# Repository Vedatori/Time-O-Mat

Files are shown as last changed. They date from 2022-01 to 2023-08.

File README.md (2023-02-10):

# Time-O-Mat [cz]
Time-O-Mat jsou hodiny navržené pro Letní robotický tábor 2022 organizovaný spolkem [Vědátoři](vedatori.com). Jedná se o otevřenou platformu, která si klade za cíle zlepšit dovednosti při mechanické stavbě a pájení. Účastníci dostali tento výrobek jako stavebnici, kdy z předem připravených dílů sestavili mechanickou část a poté pájeli nestandardní součástky na DPS s předem osazenými SMD součástkami. Po finalizaci je možné hodiny naprogramovat a používat pro zlepšení schopností algoritmizace a programování účastníků díky možnostem, které poskytují vsupní a výstupní periferie.

Mechanickou část lze rozdělit na dvě hlavní části - krabici a osmičky (segmentové zobrazovače). Vnější části krabice jsou vyřezány z překližky na laserové řezačce a obsahují zámkové západky. Ty se při stavbě lepí disperzním lepidlem a po vyschnutí tvoří pevný základ pro uložení ostatních dílů. Pouze horní část je odnímatelná a připevněná šrouby, které jsou schované v podpůrných 3D tištěných dílech, aby nekazily estetický dojem. Základní díl osmiček a dvojtečky je vytisknutý na 3D tiskárně a difuzery jednotlivých segmentů vyřezané z mléčného plexiskla se do něj vkládají z vnitřní strany a jsou uchyceny pomocí západek. Spojení osmiček a krabice zajišťuje 3D tištěný nosník umístěný uvnitř krabice, který také fixuje desky plošných spojů (DPS).

Hlavní DPS obsahuje zejména mikrokontroler ESP32, který je na ni připájen. Programování a napájení je zajištěno přes USB C. Hlavní DPS obsahuje také tlačítka, fotorezistory, bzučák a teplotní senzor. Do horního krytu je vsazena tenká podlouhlá DPS, která slouží jako senzor s osmi kapacitními tlačítky. Dominantou tohoto zařízení jsou DPS ve tvaru osmiček a dvojtečky, které jsou vsazeny za difuzery. Za každým segmentem jsou umístěny tři adresovatelné RGB LED. Další takové LED jsou umístěny zezadu na LED pásku, který zajišťuje ambientní podsvětlení prostoru za výrobkem. Hodiny jsou rozebiratelné, jednotlivé DPS jsou spojeny konektory, vzdálenější periferie pomocí kabelů.

Všechny periferie byly zvoleny tak, aby vytvořily hodiny s mnoha volitelnými postranními funkcionalitami. Díky nim je možné u účastníků tábora rozvíjet jejich schopnost algoritmizovat úlohu a programovat. Pro hodiny byla naprogramována softwarová knihovna, která výrazně zjednodušuje ovládání všech periferií. Pomocí této knihovny byl vytvořen vzorový software, který zobrazuje základní čas po připojení hodin na Wi-Fi. Po odpojení je poté čas uchován pomocí integrovaného RTC modulu, což umožňuje provoz hodin bez trvalého připojení k internetu. Hodiny je možné ovládat pomocí vstupních periferií nebo přes WiFi skrz počítač nebo smartphone, které přistupojí k interně hostované webové stránce. Všechny tyto vlastnosti lze přeprogramovat a přidat nové funkcionality podle přání vlastníka hodin. Zařízení se programuje ve Visual studio Code v jazyce c++ pomocí frameworku esp32-arduino.

Myšlenkou tohoto projektu je, aby Time-O-Mat tvořil každodenní užitečný doplněk pokoje, ale aby mohl být jeho software jednoduše modifikován a rozvíjen tak, jak si každý jeho vlastník představuje.

## Návod
Při stavbě hodin Time-O-Mat postupujte podle připravených návodů v následujícím pořadí:
1. [Návod pro elektroniku](https://github.com/vedatori/Time-O-Mat/blob/main/Manuals/Time-O-Mat_electronics_cz.md)
1. [Návod pro mechaniku](https://github.com/vedatori/Time-O-Mat/blob/main/Manuals/Time-O-Mat_mechanics_cz.md)
1. [Návod pro programování](https://github.com/vedatori/Time-O-Mat/blob/main/Manuals/Time-O-Mat_programming_cz.md)

# Time-O-Mat [en]
Time-O-Mat is a clock designed for Summer robotics camp 2022 (cz) organized by Vědátoři team (cz). It is a robotic platform offering development of mechanical assembly and soldering skills. The project has been designed as a kit for participants to be assembled and special electronic components to be soldered on a pre-assembled printed circuit board (PCB). When assembled it can be used to improve algorithmization and programming skills.

Mechanical set consists of two main parts - box and eights (segment displays). Box is made of laser cut plywood parts with latches that are mostly glued together. Upper parts are fastened using bolts hidden in inner 3D printed parts. The eights are 3D printed bodies with diffusers made of plexiglass clicked in them. Inner 3D printed parts ensure connection of the box and the eights.

Main PCB carries ESP32. It is programmed and powered using USB C and contains buttons, buzzer and photosensors. Capacitive touchbar with eight touch buttons is placed on upper part of the enclosure. Main eye-catcher of the clock is eight-shaped PCB with segments containing three adressable RGB LEDs in each segment. Ambient backlight is provided by LED strip on the backside of the clock. Clock can be disassembled if needed for upgrade or service and connectors are used for PCB interconnections.

All of the peripherals had been chosen to enrich the clock with various related functions. This enables development of algorithmization and programming skills of camp participants. Special internally developed software library makes programming of the clock much easier and allows better understanding of software features. Repository contains demo project that allows WiFi connection and time alignment of the clock with the Internet. Time is stored in RTC module after power off and it is not needed to establish WiFi connection after next power on. Clock can be controlled using input peripherals and Wi-Fi (using smartphone or PC) thru internally hosted website.

New features based on owner's needs can be easily introduced. Main aim of Time-O-Mat is to be a daily companion that offers easy software modifications and development.

## Licence
* Obsah tohoto repozitáře mimo složku *Software* je sdílen pod licencí [Attribution-NonCommercial-ShareAlike 4.0 International (CC BY-NC-SA 4.0)](https://creativecommons.org/licenses/by-nc-sa/4.0/).
* Obsah složky *Software* je sdílen pod licencí [GNU Lesser General Public License v3.0](https://www.gnu.org/licenses/lgpl-3.0.en.html).

## License
* The contents of this repository excluding folder *Software* is shared under license [Attribution-NonCommercial-ShareAlike 4.0 International (CC BY-NC-SA 4.0)](https://creativecommons.org/licenses/by-nc-sa/4.0/).
* The contents of the folder *Software* is shared under license [GNU Lesser General Public License v3.0](https://www.gnu.org/licenses/lgpl-3.0.en.html).

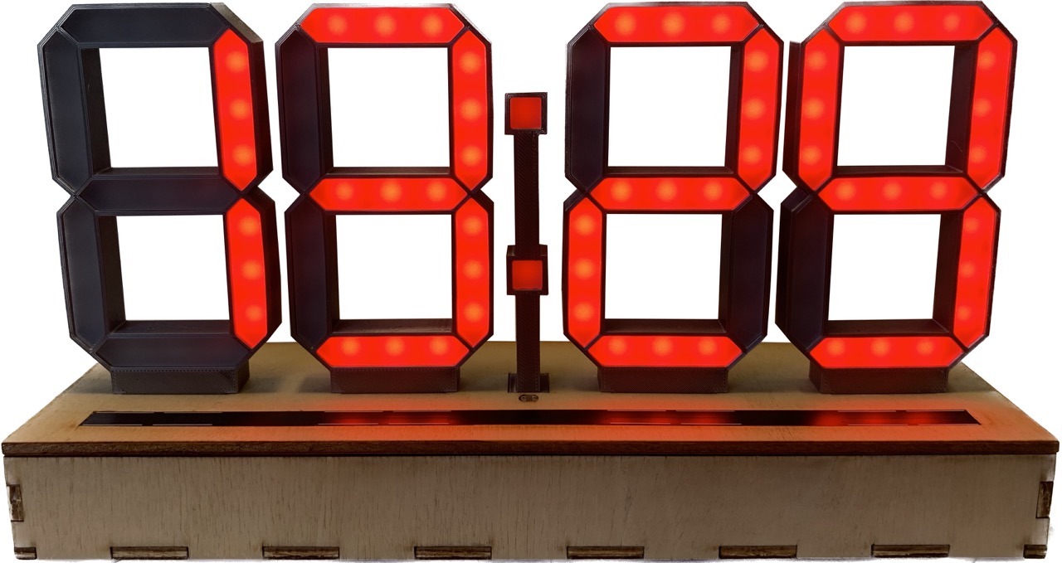
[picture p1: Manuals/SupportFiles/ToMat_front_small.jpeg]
Time-O-Mat front view

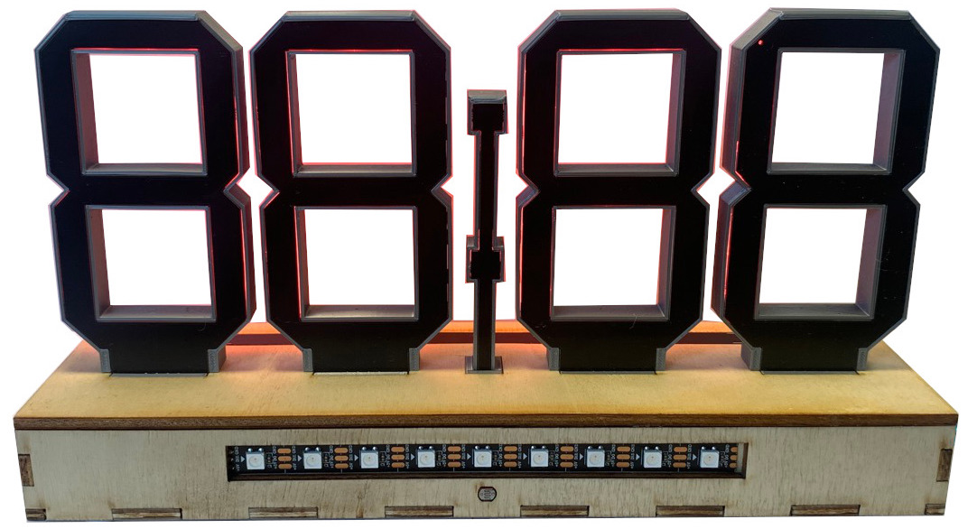
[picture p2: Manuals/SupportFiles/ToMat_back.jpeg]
Time-O-Mat back view

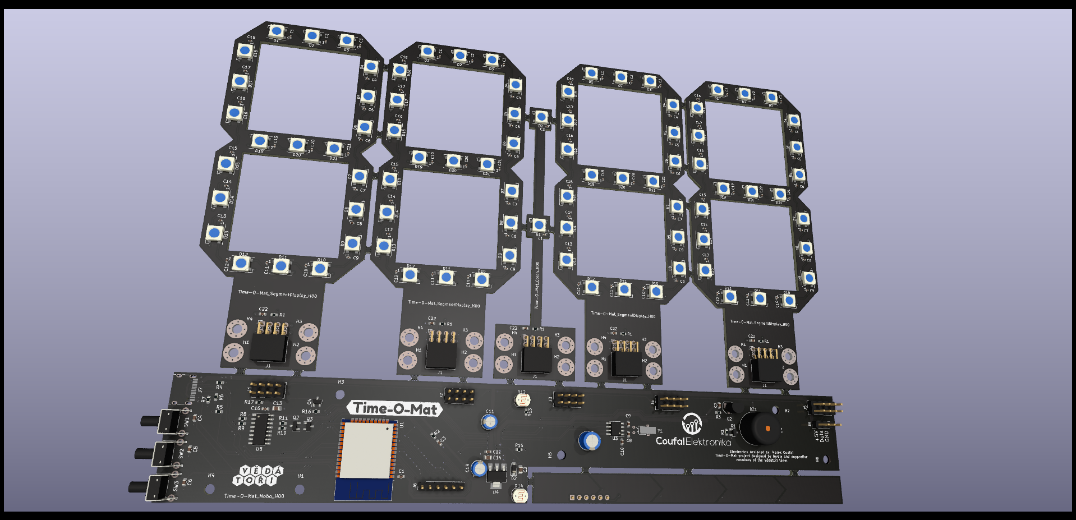
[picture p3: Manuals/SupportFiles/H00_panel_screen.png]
generated 3D model of panelized H00 PCBs


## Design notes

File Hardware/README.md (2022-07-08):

<h1>Designer's notes for Hardware development</h1>
<h2>USB C power supply current capability</h2>
The capability of each power supply can be determined by reading analog voltages on pins CC1 and CC2 connected to voltage dividers.

If the USB C standard in the cable and power adapter in use is properly implemented, one of the CC pins should always read 0V and the second one should be on one of the following voltage levels:
<ul>
  <li><strong>0,42V</strong> - legcy USB (1000mA most of the times)</li>
  <li><strong>0,94V</strong> - 1500mA</li>
  <li><strong>1,68V</strong> - 3000mA</li>
</ul>
The order of CC pins (e.g. if CC1 is 0V and CC2 is one of the three voltages or vice versa) is determined by the orientation of the cable and does not matter in our application.

<h2>To do list for next HW revision</h2>
<ul>
  <li>Zener diodes for power rails protection</li>
  <li>multi board wide power connector for testing</li>
  <li>add I2C header if possible</li>
  <li>buzzer pin spacing too wide</li>
  <li>Touch connector to JST, possibly without ground</li>
  <li>Fotorezistory - jeden na prostředek před dvojtečokou kolmo z desky, druhej ve stejné výčce</li>
  <li>lišta 240 mm</li>
  <li>díry 4 dolů a dvě mezi osmičky</li>
  <li>konektor na ws pásek k hraně</li>
  <li>reset possibly šroubovákem</li>
  <li>smdčka u segmentů bokem</li>

</ul>

<h2>To do list for next (H02) HW revision</h2>
<ul>
  <li>Add JST-XH connectors for the photoresistor in the back and backlight LED strip.</li>
  <li>Change touchbar graphics</li>
  <li>Lower supercapacitor resistor value</li>
  <li>Add 100k resistors in series between CC and Sensor V pins</li>
  <li>Maybye move the temperature sensor to the bottom</li>
  <li>Add LPF to photoresistor inputs</li>
  <li>Bigger Vedatori logo on the bottom, change to silk layer instead of copper.</li>
</ul>

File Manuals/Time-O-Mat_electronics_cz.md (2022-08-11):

V tomto dokumentu je uveden návod na osazení desky plošných spojů elektronickými součástkami. Některé součástky byly osazeny strojově při výrobě desek. Zbytek osazení je předmětem tohoto návodu.
Pro tento návod si zavedeme následující pojmy:
* DPS (Deska Plošných Spojů) - Laminátová deska pokrytá elektricky vodivými měděnými cestami, na kterou budeme nyní pájet součástky.
* PCB (Printed Circuit Board) - To stejné, co DPS.
* SMD (Surface Mount Device) - Tzv. bezvývodové elektronické součástky, které mají krátké nožičky. Tyto součástky jsou připájeny k DPS pouze z jedné strany. Tyto součástky byly osazevy strojově při výrobě DPS.
* THT (Through-hole Technology) - Tzv. vývodové elekotronické součástky, které mají dlouhé nožičky. Tyto nožičky jsou před zapájením součástky prostrčeny skrz otvory v DPS.

THT součástky budeme pájet následujícím způsobem:
1. Součástku vkládáme ze strany, kde je její obrys naznačen bílou čárou, tzv. silkscreenem.
1. Vývody (nožičky) součástek prostrčíme přisušnými otvory v DPS. Musí to jít lehce.
1. Součástku přitlačíme až k desce nebo co nejblíže.
1. Součástku pájíme ze strany, na kterou trčí její vývody. Tzn. z opačné strany, než je její bílý obrys na silkscreenu.
1. Vývody po zapájení zastřihneme.

___
# Obsah
* [Číslice - digity](#digity)
* [Hlavní PCB - horní strana](#hlavni_pcb_horni)
* [Hlavní PCB - spodní strana](#hlavni_pcb_spodni)
* [LED pásek](#led_pasek)
* [Dotyková lišta](#dotykova_lista)
* [Zadní fotorezistor](#zadni_fotorezistor)
___

<!-- _________________________________________________________________ -->
# <a name = digity>Číslice - digity</a>

## Potřebujeme:
* PCB s digity a dvojtečkou
* 5x female konektor 2x4 pinů do L
* 3D tištěný držák pro pájení konektorů
* štípací kleště
* pilník
* páječka

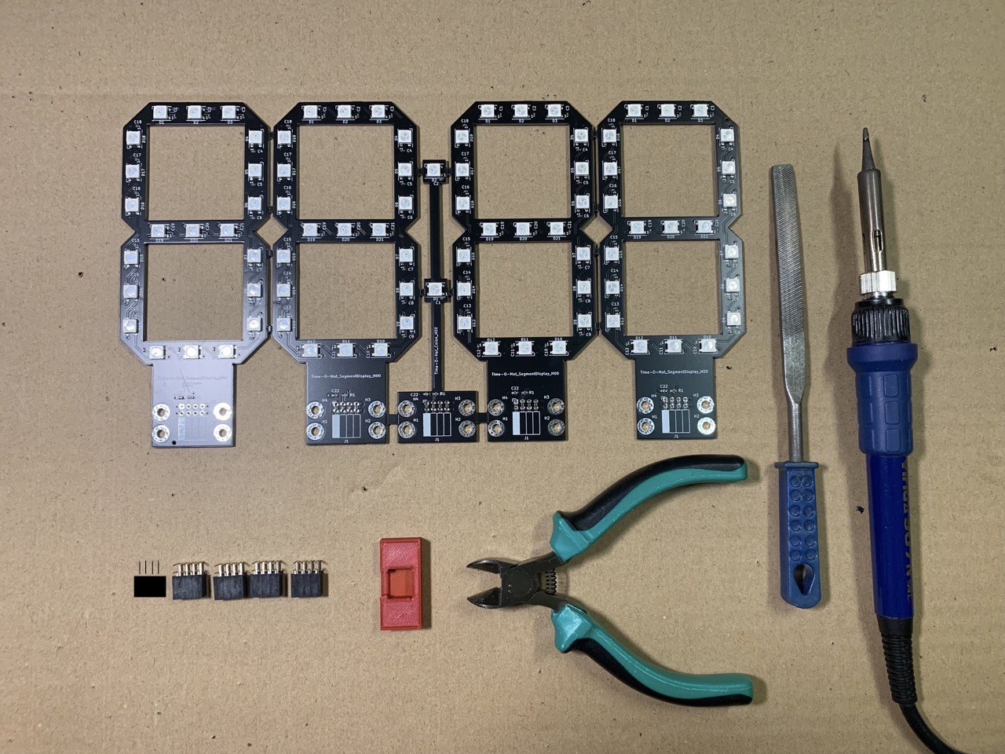
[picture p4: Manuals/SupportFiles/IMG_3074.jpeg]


## Postup:
Opatrně proti stolu od sebe odlámeme jednotlivé digity a dvojtečku.
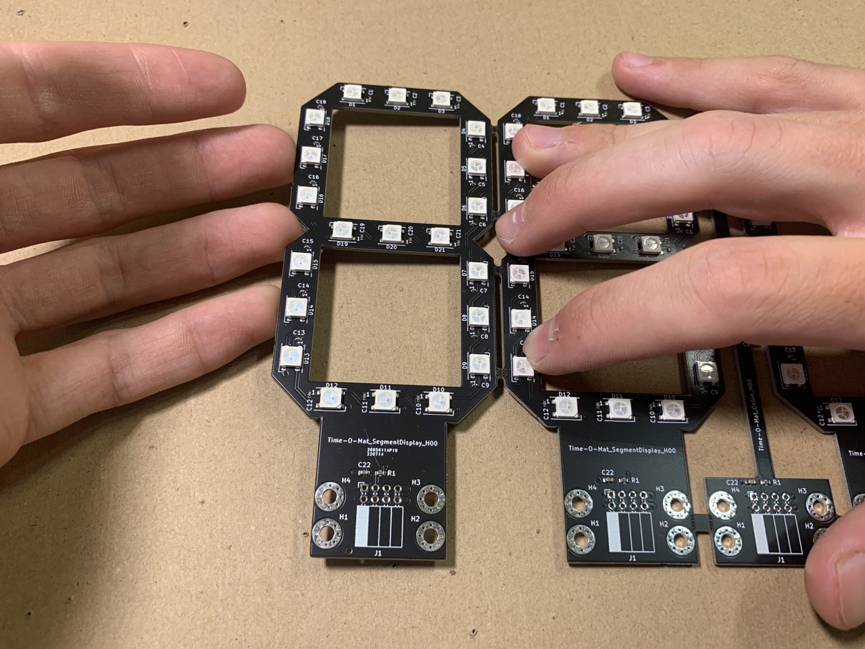
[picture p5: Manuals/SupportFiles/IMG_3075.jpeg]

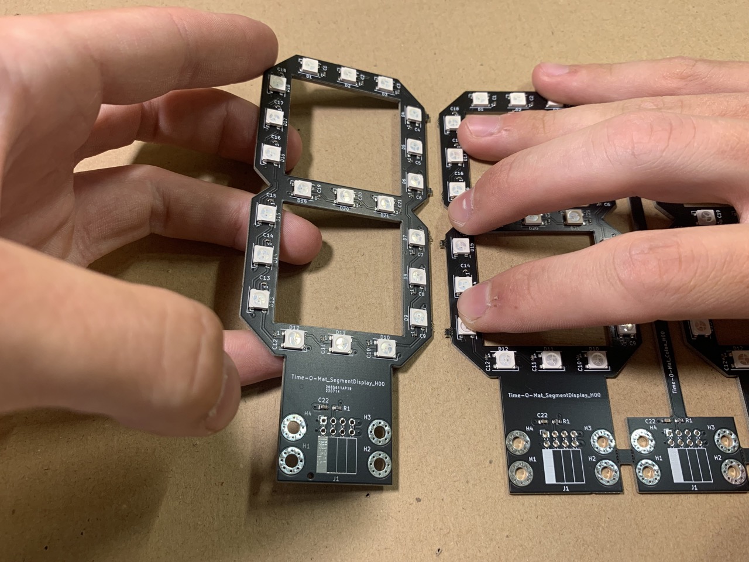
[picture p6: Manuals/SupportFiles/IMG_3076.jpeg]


Dáváme velký pozor, abychom lámali jen připravené můstky a nezlomili samotnou dvojtečku.
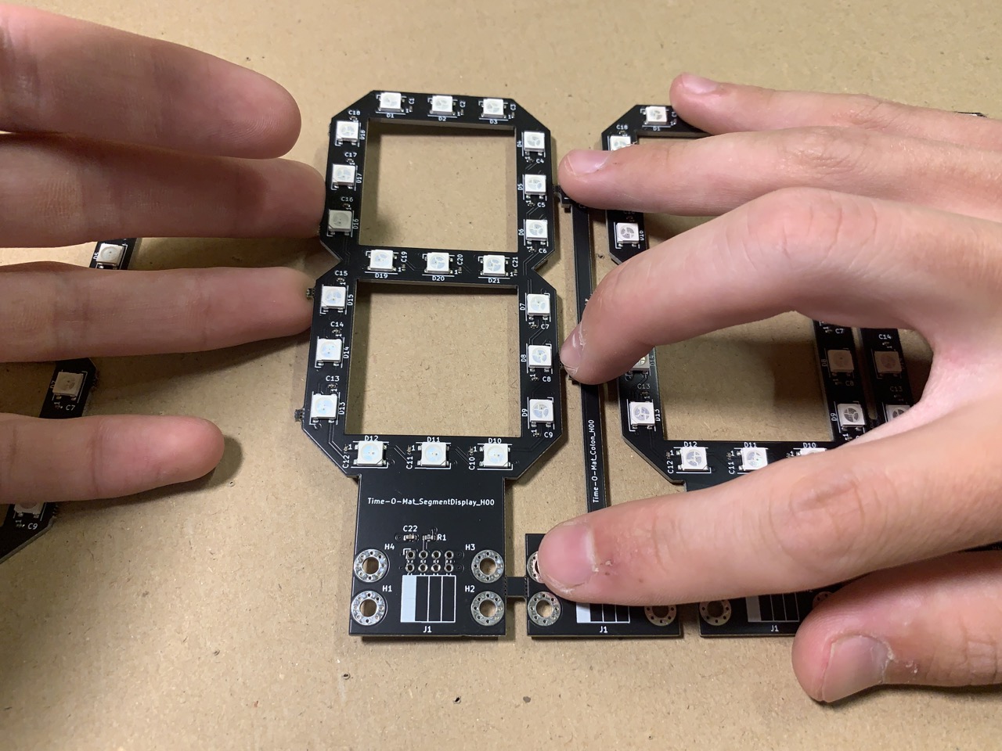
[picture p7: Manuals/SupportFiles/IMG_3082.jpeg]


Postupně rozlámeme všechny připravené můstky.
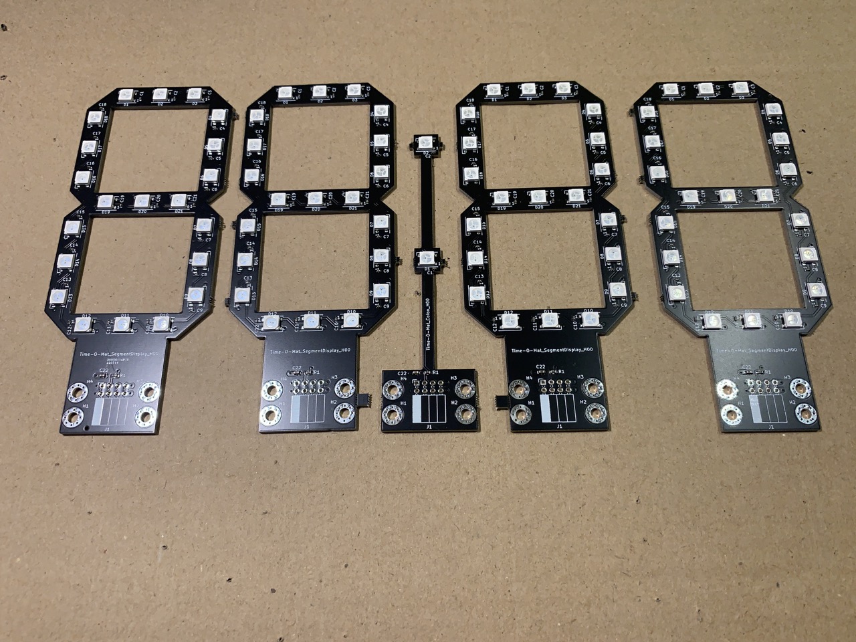
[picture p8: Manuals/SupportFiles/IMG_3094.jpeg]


Pomocí štípacích kleští odštípeme všechny zbylé můstky.
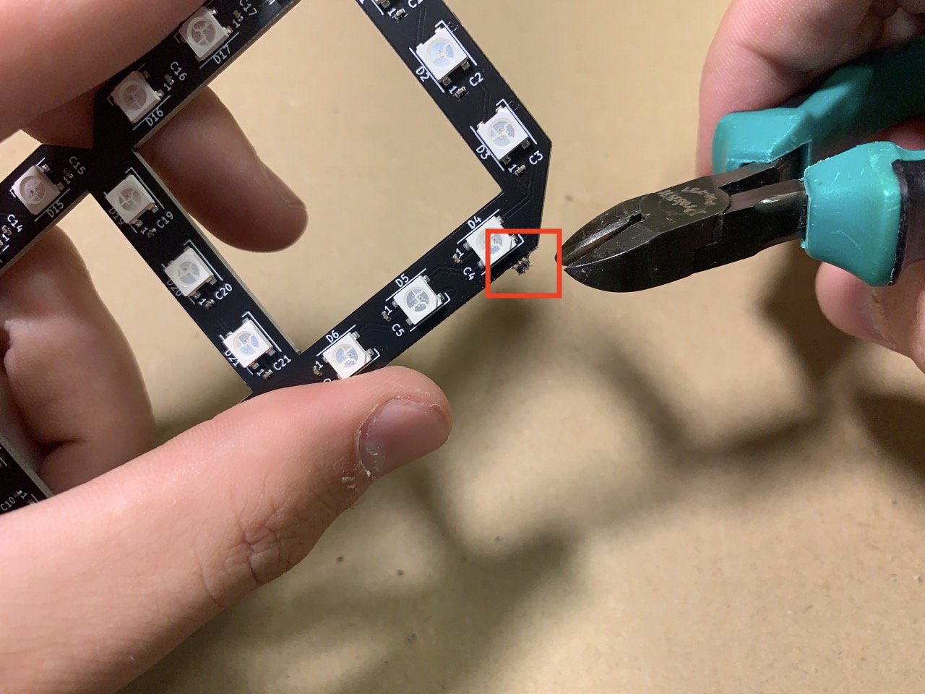
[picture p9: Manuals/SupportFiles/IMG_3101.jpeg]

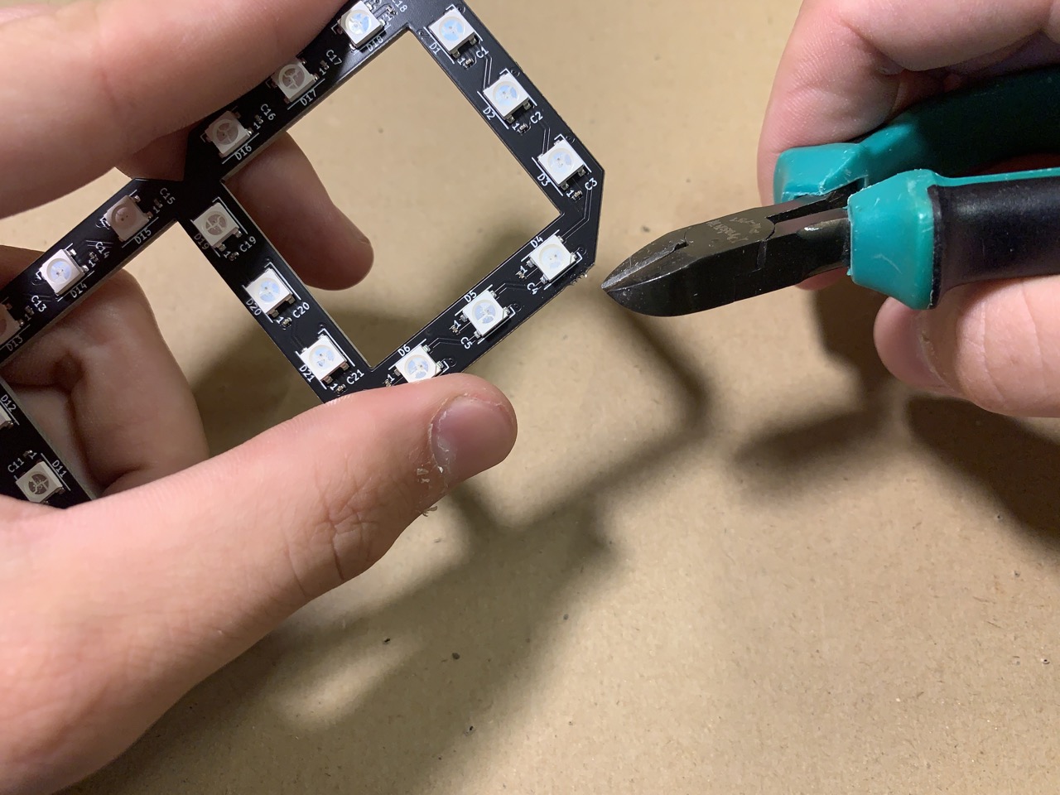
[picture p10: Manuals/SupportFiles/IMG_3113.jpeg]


Pomocí pilníků zabrousíme všechny zbytky po můstcích do roviny.
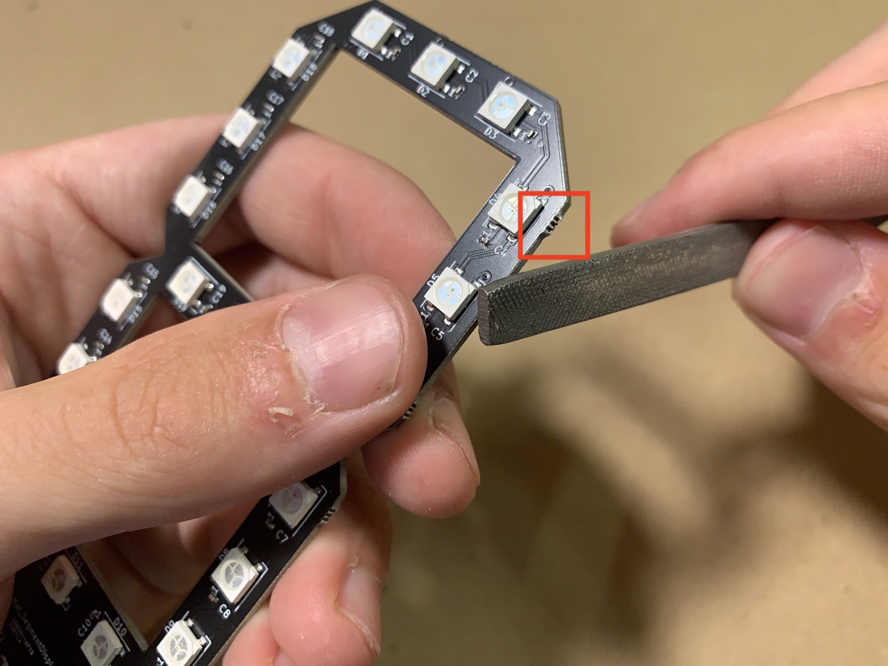
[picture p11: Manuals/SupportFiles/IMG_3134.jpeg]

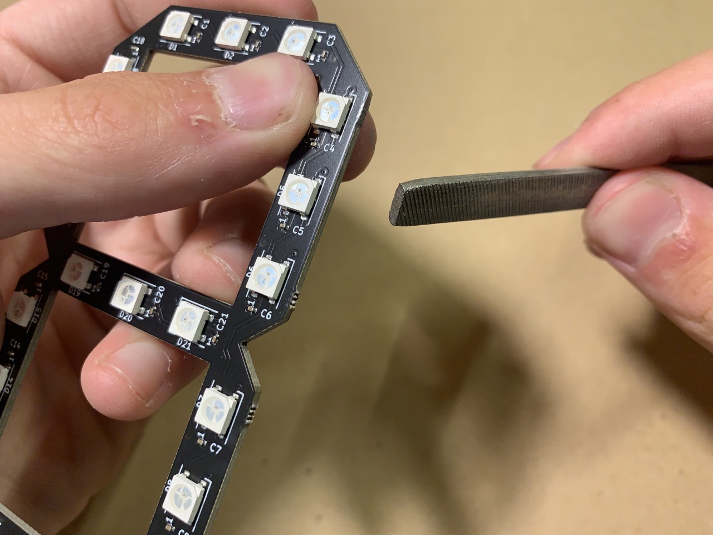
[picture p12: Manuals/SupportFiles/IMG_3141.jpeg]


Připravíme si díly pro pájení konektoru na 1 digit.
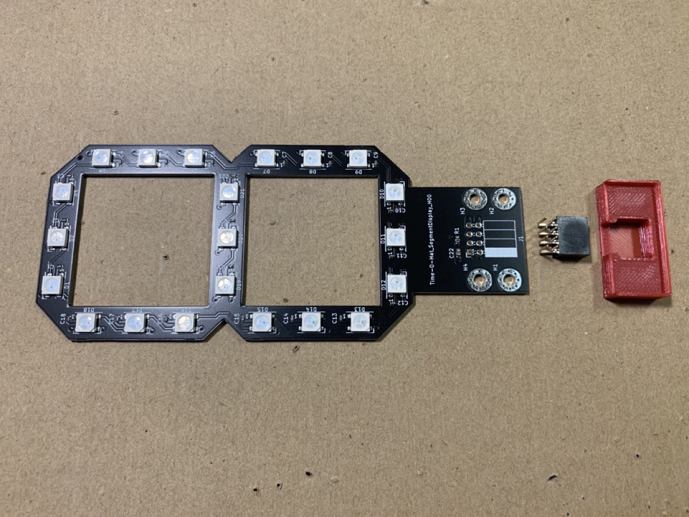
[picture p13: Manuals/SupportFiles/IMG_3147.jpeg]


Konektor zasuneme do 3D tištěného držáku.
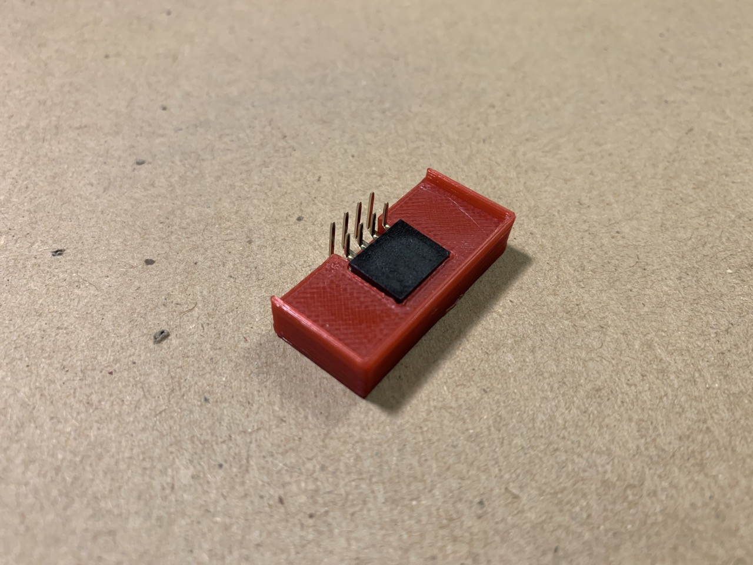
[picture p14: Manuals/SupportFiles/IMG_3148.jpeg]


Konektor s držákem nasadíme na digit.
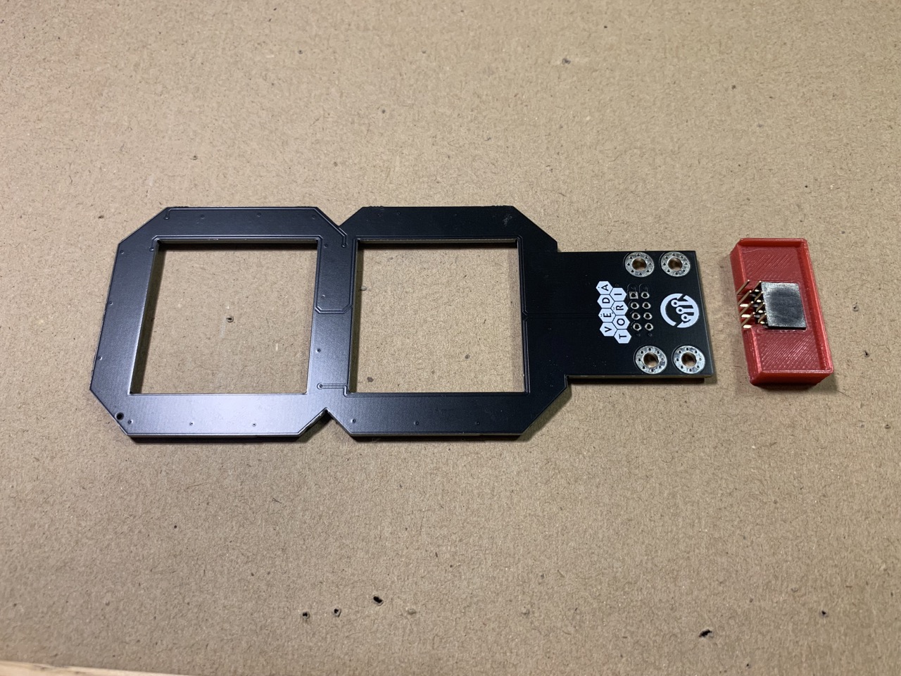
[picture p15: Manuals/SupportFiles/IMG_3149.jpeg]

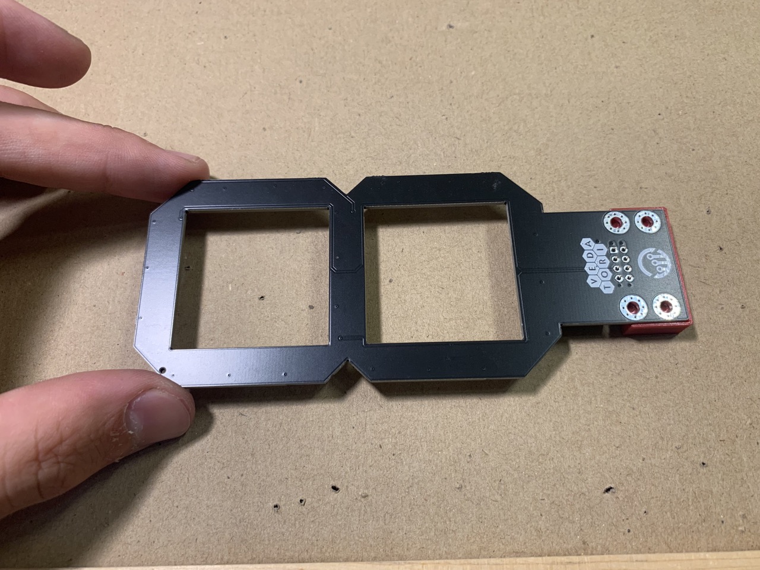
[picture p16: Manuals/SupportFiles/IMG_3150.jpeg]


Protější (levou) stranu digitu podložíme do roviny
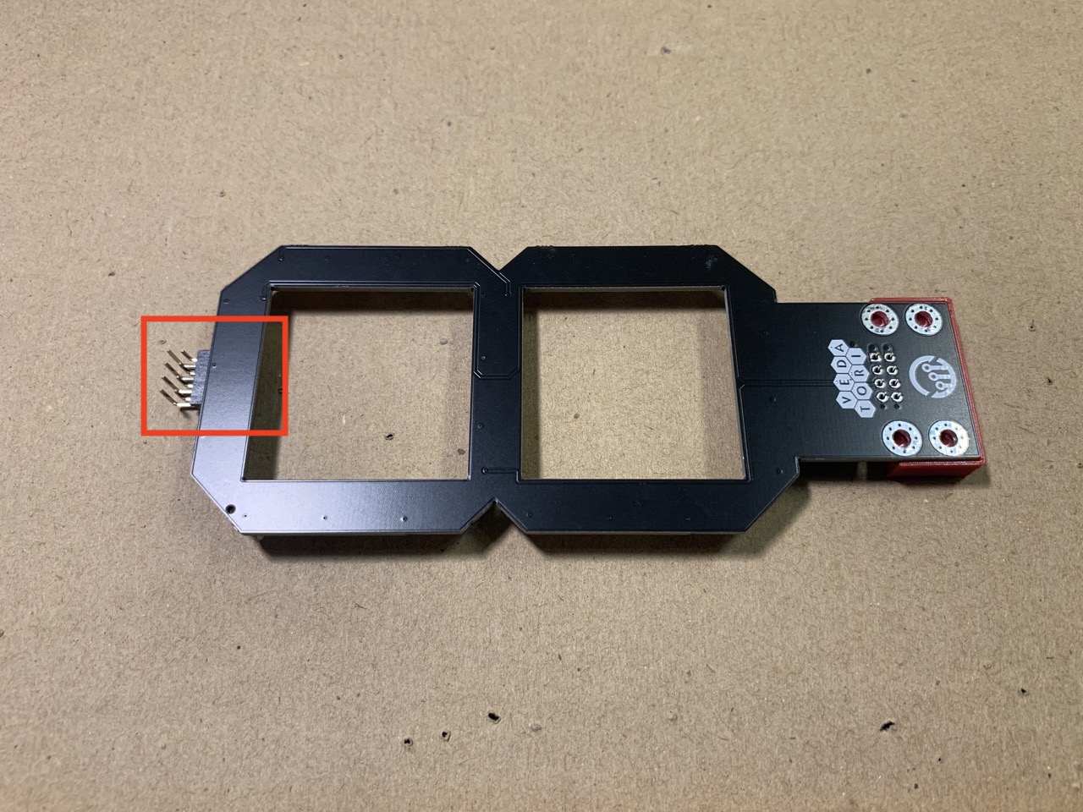
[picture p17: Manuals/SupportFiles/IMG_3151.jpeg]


Zapájíme všechny piny konektoru.
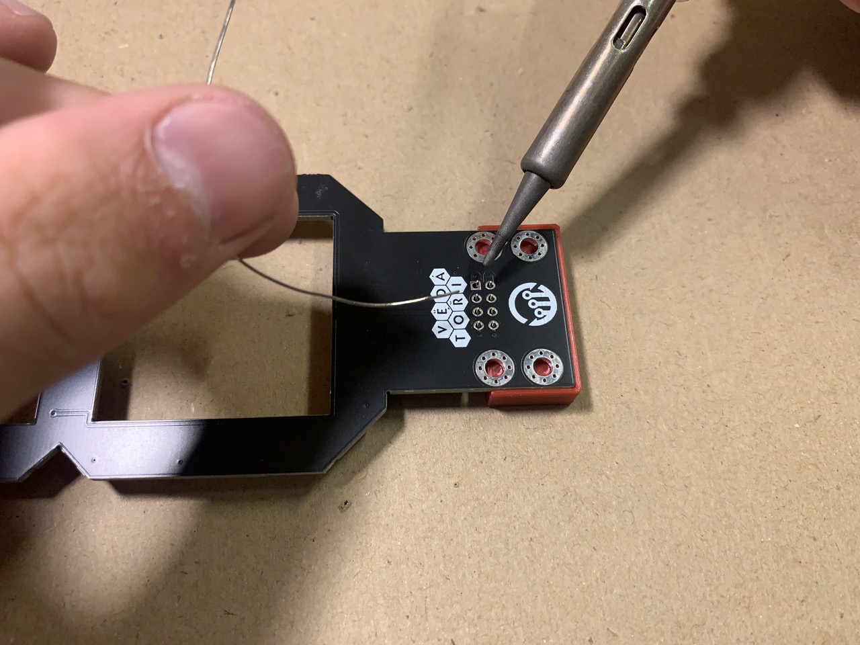
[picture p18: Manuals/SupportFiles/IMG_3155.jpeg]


Zapájíme tímto způsobem konektory na všechny digity a dvojtečku.
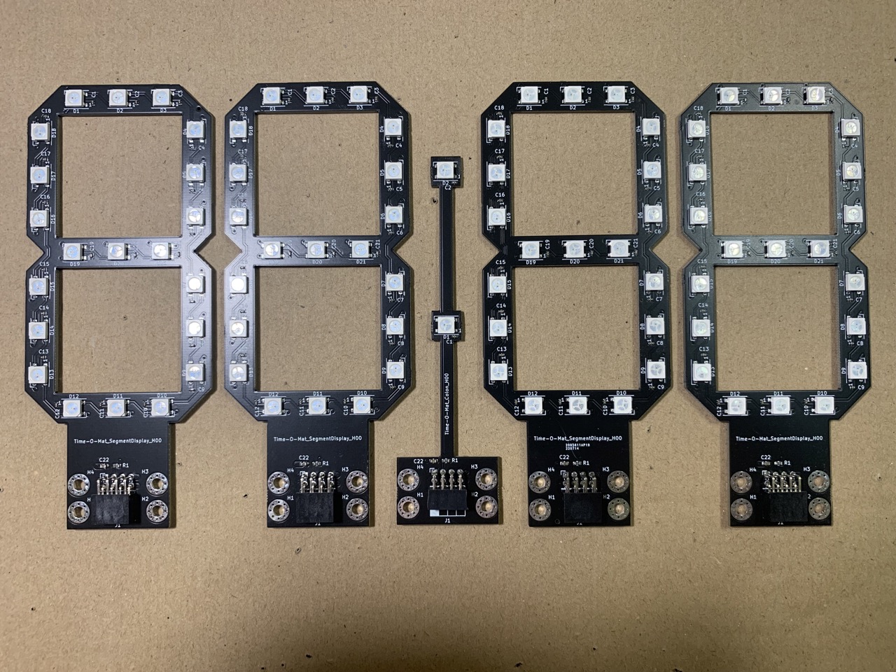
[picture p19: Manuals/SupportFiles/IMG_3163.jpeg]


<!-- _________________________________________________________________ -->
# <a name = hlavni_pcb_horni>Hlavní PCB - horní strana</a>

## Potřebujeme:
* hlavní PCB
* konektorovou lištu s piny 2x20
* konektor s 2 piny - horizontální
* konektor s 3 piny - horizontální
* konektor s 6 piny - vertikální
* 2x kondenzátor
* fotorezistor
* krystal
* piezoakustický měnič
* 3x tlačítko
* 2x 3D tištěný držák konektorů digitů
* 3D tištěný držák fotorezistoru
* štípací kleště
* páječka

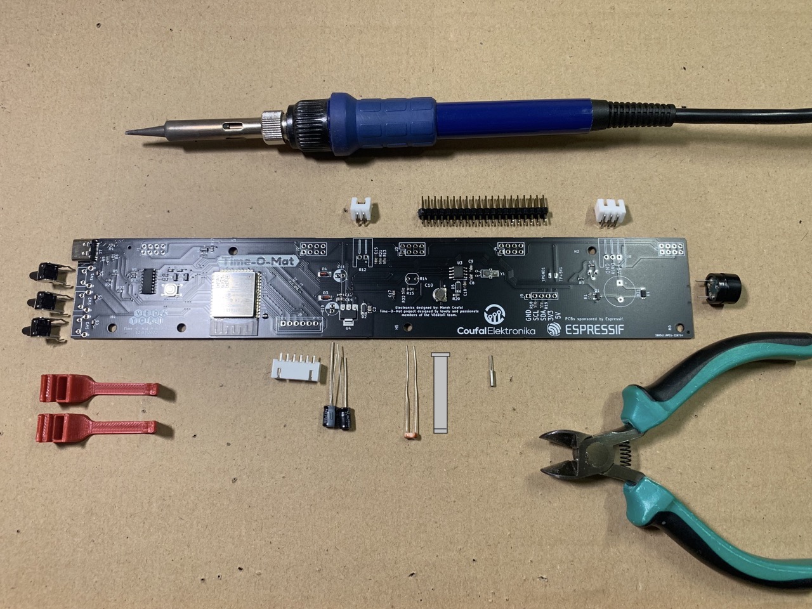
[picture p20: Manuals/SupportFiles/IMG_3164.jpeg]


## Postup:
Nasadíme horizontální konektory s 2 a 3 piny na hlavní PCB.
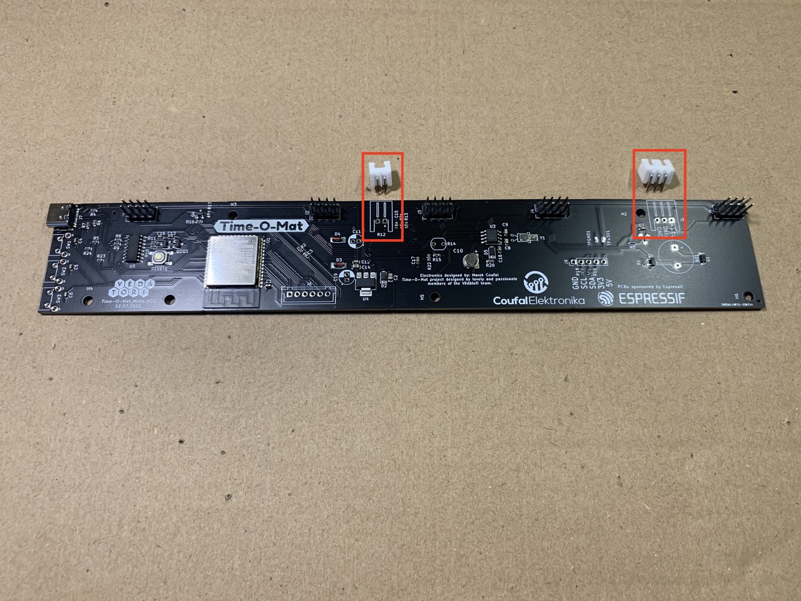
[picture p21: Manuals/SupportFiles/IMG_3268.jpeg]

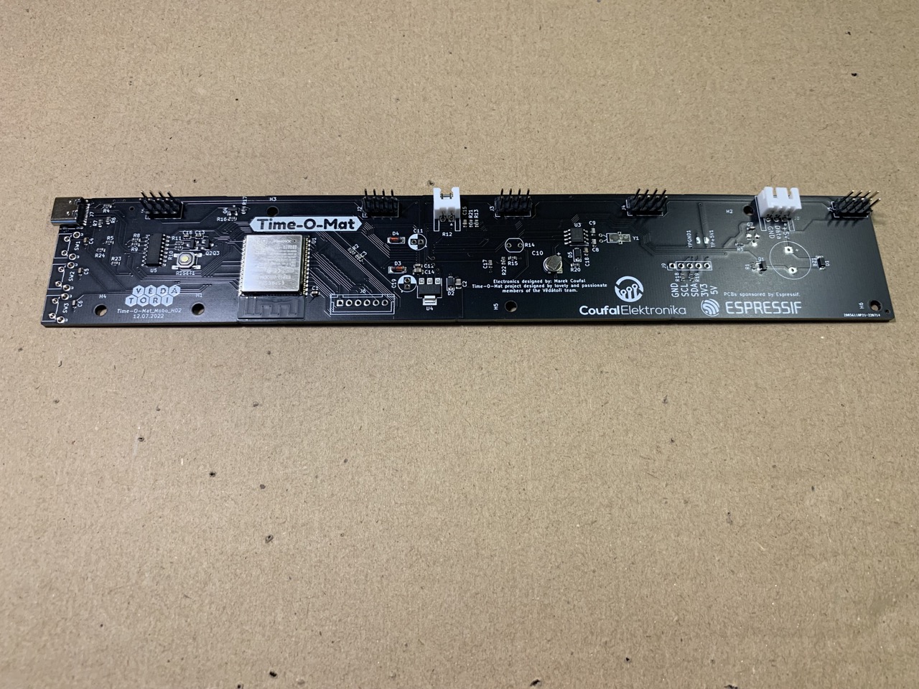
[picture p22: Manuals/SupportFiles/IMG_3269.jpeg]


Opatrně otočíme hlavní PCB a konektory zapájíme. Dáváme pozor, aby zůstaly přitlačené co nejblíže k PCB.
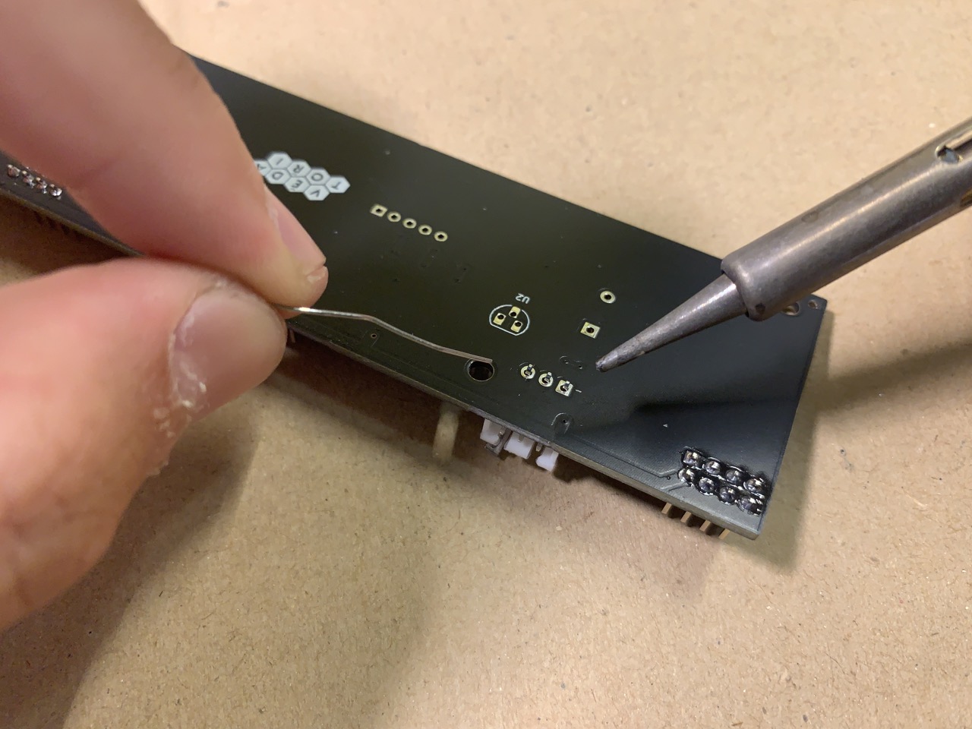
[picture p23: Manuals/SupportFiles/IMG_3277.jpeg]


Nasadíme 3 tlačítka na hlavní PCB.
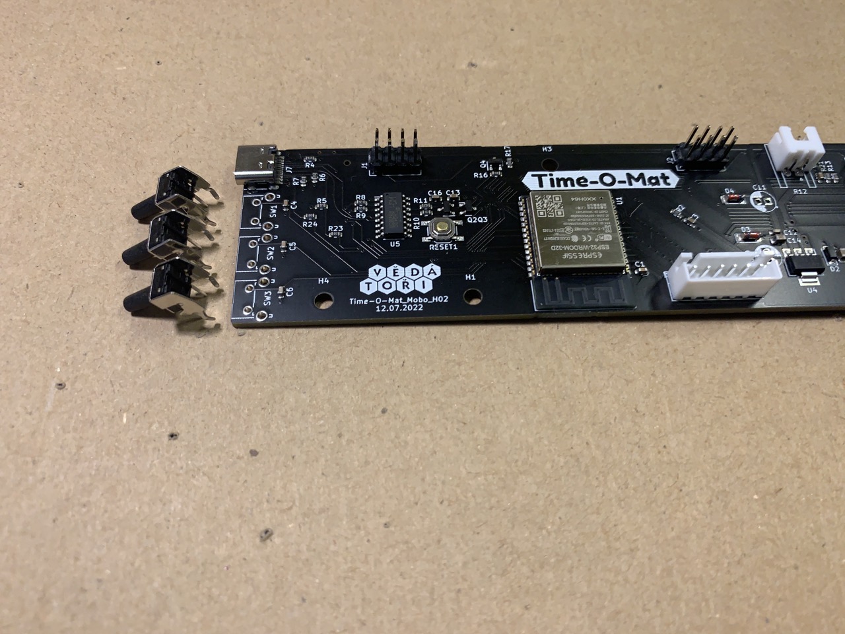
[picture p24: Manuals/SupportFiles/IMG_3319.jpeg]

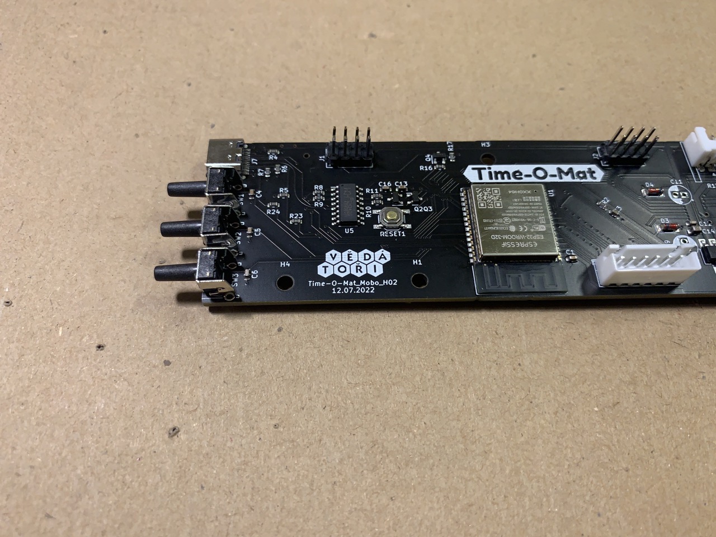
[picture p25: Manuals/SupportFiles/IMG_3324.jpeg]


Zapájíme tlačítka na hlavní PCB.
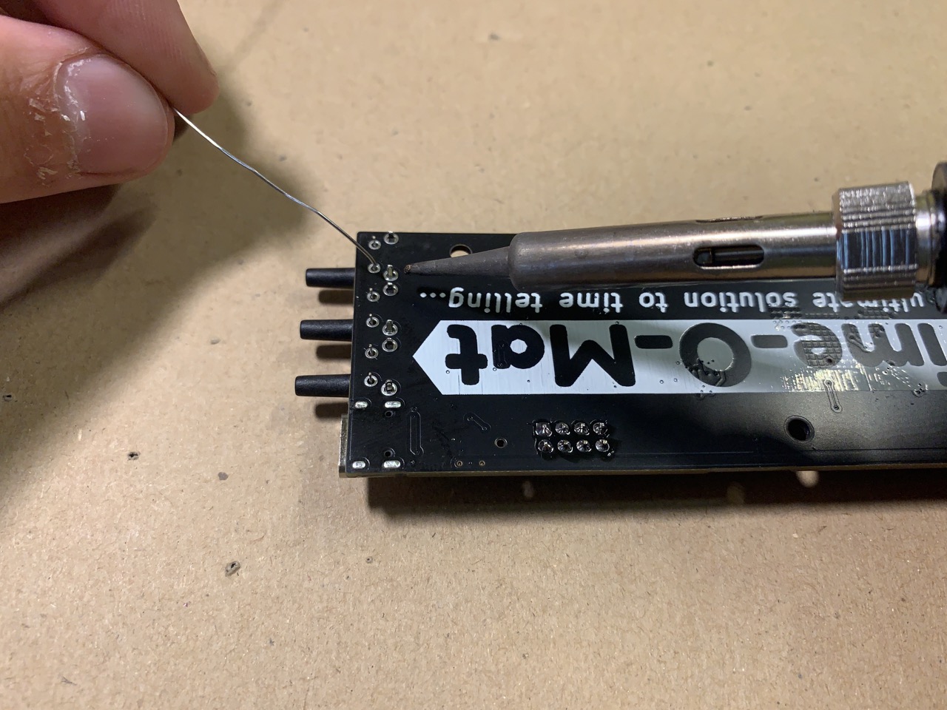
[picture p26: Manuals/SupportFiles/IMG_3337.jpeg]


U tlačítka 3 zakrátíme vývody štípacími kleštěmi.
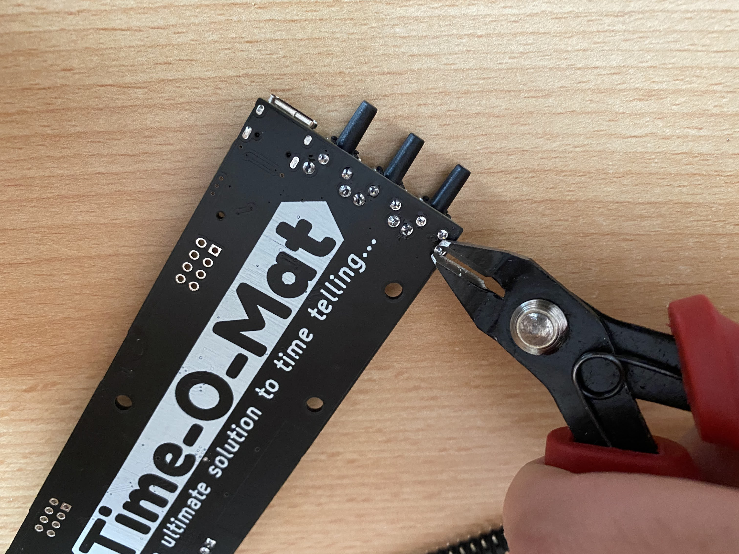
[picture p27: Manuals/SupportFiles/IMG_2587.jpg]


Pomocí štípacích kleští nastříháme konektorovou lištu na 5 kusů o rozměrech 2x4 piny. Vzniknou konektory digitů.



Nasuneme konektory digitů do 3D tištěných držáků.



Nasadíme držáky s konektory digitů na hlavní PCB.



Držáky konektorů digitů namáčkneme co nejblíže na hlavní PCB.


Zapájíme všech 8 pinů každého konektoru digitu.


Tímto způsobem zapájíme všech 5 konektorů digitů. Pozor, aby byl hlavní PCB při pájení vždy v rovině.


Nasadíme konektor s 6 piny na hlavní PCB.



Opatrně otočíme hlavní PCB a konektor zapájíme. Dáváme pozor, aby zůstal natlačený co nejblíže na PCB.


Nasadíme oba kondenzátory na hlavní PCB. Dbáme na polaritu! Delší nožička (+) patří do otvoru s černým okolím a vyznačeným plusem.



Kondenzátory zapájíme.


Pomocí štípacích kleští ustřihneme nožičky kondenzátorů co nejblíže hlavnímu PCB.


Nasadíme piezoakustický měnič na hlavní PCB. Dbáme na polaritu! Plus na měniči musí odpovídat plusu na PCB.



Měnič zapájíme.


Pomocí štípacích kleští ustřihneme nožičky měniče co nejblíže hlavnímu PCB.


Nasadíme krystal na hlavní PCB. Polarita je libovolná.


Krystal zapájímě. Dbáme na to, aby byl krystal při pájení opřený o stůl, tedy dělila ho od PCB mezera.


Krystal ohneme k PCB do pozice vyznačené na silkscreen.


Vybereme si jednu z ustřižených nožiček kondenzátorů z minulých kroků a v polovině ji ohneme.


Nožičku nasadíme do hlavní PCB do děr vedle krystalu.



Nožičku zapájíme ze spodní strany PCB.


Pomocí štípacích kleští ustřihneme zbytky nožičky co nejblíže PCB.


Zapájíme nožičku ke krystalu na horní straně PCB.



Vsuneme fotorezistor do držáku fotorezistoru.



Nasadíme držák s fotorezistorem na hlavní PCB. Na polaritě nezáleží. Dbáme, aby byl fotorezistor co nejvíce natlačen na PCB.


Fotorezistor zapájíme.


Pomocí štípacích kleští ustřihneme zbytky nožiček co nejblíže PCB.


<!-- _________________________________________________________________ -->
# <a name = hlavni_pcb_spodni>Hlavní PCB - spodní strana</a>

## Potřebujeme:
* hlavní PCB
* teploměr DS18B12
* štípací kleště
* páječku



# Postup:
Nasadíme teploměr za *spodní* strany PCB až skoro nejblíže k PCB.


Teploměr zapájíme.


Pomocí štípacích kleští ustřiheneme zbytky nožiček co nejblíže k PCB.


<!-- _________________________________________________________________ -->
# <a name = led_pasek>LED pásek</a>

## Potřebujeme:
* LED pásek
* konektor s 3 piny a drátovými vývody
* páječku



## Postup:
LED pásek a konce drátů sesouhlasíme v pořadí tak, jak je vidět na obrázku. Důležité je, aby šipky mezi LED směřovaly pryč od drátků a aby barvy drátků byly ve stejném pořadí, jako na fotce.


Odizolované konce drátků zapájíme.



<!-- _________________________________________________________________ -->
# <a name = dotykova_lista>Dotyková lišta</a>

## Potřebujeme:
* dotykovou lištu
* konektor s 6 piny a drátovými vývody
* páječku

## Postup:
Na všechny plošky na spodní straně lišty předem naneseme pájku.


Postupně zapájíme drátky. Zelený připojíme na plošku s popisem GND, ostatní připojujeme tak, jak jsou zasunuté v konektoru (žádné se nesmí křížit). Je nutné dodržet orientaci podle fotky. Také je možné si podle ní zkontrolovat pořadí barev.



<!-- _________________________________________________________________ -->
# <a name = zadni_fotorezistor>Zadní fotorezistor</a>

## Potřebujeme:
* fotorezistor
* konektor 2 piny a drátovými vývody
* 2x cca 0,8 cm dlouhý kousek smršťovací bužírky
* 3D tištěný držák fotorezistoru
* stahovací pásku
* páječku
* zdroj tepla (zapalovač)



## Postup:
Vývody fotorezistoru provlékneme skrz 3D tištěný držák. Výstupek v držáku směřuje směrem k tělu fotorezistoru.


Na oba drátky nasuneme smršťovací bužírku.


Vývody fotorezistoru zkrátíme tak, aby v délce cca 7 mm čněly z držáku.


K oběma vývodům fotorezistoru připájíme drátky. Na polaritě nezáleží.


Oba vývody ohneme směrem ke ztenčené části 3D tištěného držáku. Smršťovací bužírku nasuneme co nejvíce přes pájené spoje. Pod dozorem vedoucího teplem smrštíme. Pozor, pracujete s otevřeným plamenem!


Kolem zúžené části držáku utáhneme stahovací pásku tak, aby její hlava směřovala k drátkům. Stahovací pásku poté zastřihneme.



Finální pohled na díl:


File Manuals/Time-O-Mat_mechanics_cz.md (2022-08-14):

Tento dokument je návodem k sestavení mechanické části hodin Time-O-Mat. Hodiny jsou sestaveny z dílů vytištěných na 3D tiskárně, řezaných laserem (plexisklo a dřevo), spojovacího materiálu (šrouby a matky) a dalších doplňků.
Do postupu poprvé přidáváme lepení dílů, takže je potřeba tomu uzpůsobit styl práce. Pokud si před zalepením dílu nejste něčím jistí, je dobré si to buďto vyzkoušet ještě před nanesením lepidla a nebo zavolat vedoucího, který vám poradí. 

Používat budeme dvě lepidla
* **Herkules** - disperzní vodou ředitelné lepidlo na dřevo. Doba zasychání záleží na objemu naneseného lepidla, obecně platí, že pomocí tečkování aplikátorem ho naneseme takové množství, aby moc nebo vůbec nevytékalo z lepeného spoje po jeho zmáčnutí. Nanášíme pouze na jednu lepenou plochu a tečky můžeme poté špičkou lepidla rozetřít do plochy.
* **Chemoprén** - ten se nanáší pomocí párátka na obě plochy a roztírá se po ploše. I tady platí, že by lepidlo nemělo vytékat z lepeného spoje nadměrně ven. Po nanesení máte několik minut na spojení ploch, takže ani v tomto případě nemusíte extrémně spěchat. 

Při práci je důležité mít pořád čisté ruce a pracovní podložku, abyste si dřevo neumazali.
Další novinkou je lakování krabice. K tomu jsme vybrali polyurethanový lak, který je ředitelný vodou. Pro dobrý výsledek stačí nanést tenkou vrstvu laku tak, aby byla pokrytá celá lakovaná plocha (poznáte po naklonění plochy proti světlu). Nanáší se dvě vrstvy, to je v návodu popsáno.

___
# Obsah
* [Příprava překližkových dílů](#preklizka)
* [Vlepení LED pásku](#LEDpas)
* [Ochrana dotykové lišty](#lista)
* [Slepení krabičky](#krabice)
* [Vkládání difuzorů do segmentů](#osmicky)
* [Lakování krabičky](#lak)
* [Druhá vrstva laku](#lak2)
* [Vlepení lišty a fotorezistou](#vlepeni)
* [Finální sestavení](#final)
___

<!-- _________________________________________________________________ -->
# <a name = preklizka>Příprava překližkových dílů</a>

## Potřebujeme:
* všechny díly z překližky
* Hrubý smirek (zelený - 150)
* Jemný smirek (černý - 600)




## Postup:
Ukliďte si pracovní plochu po předchozích krocích, tj. odstraňte pájku, příslušenství k pájení a zbytky po něm.

Obruste hrubým (zeleným) smirkem tmavě gravírovaný prostor pro dotykovou lištu. Odbrušte tmavé gravírování v zahloubení. Zelený smirek nepoužívejte pro další broušení!



Výsledek po broušení tmavě gravírovaného prostoru musí vypadat jako na obrázku. Vyzkoušejte, že vám do něj zapadne dotyková lišta a že nikde nevyčnívá.



Jemným (černým) smirkem obruste pohledové plochy dřevěných dílů. Pohledové plochy jsou ty, kde je něco vygravírováno nebo ty, které jsou méně opálené od laseru.


Ukliďte si pracovní plochu po předchozích krocích, tj. setřete prach vzniklý broušením (nejlépe mokrou hadrou nebo kapesníkem).

<!-- _________________________________________________________________ -->
# <a name = LEDpas>Vlepení LED pásku</a>

## Potřebujeme: 
* zadní strana krabice
* podpůrný díl překližky pro LED pásek
* LED pásek s napájenými přívodními drátky
* Lepidlo Herkules
* Malý zalamovací nůž

 

## Postup:
Seřízněte hranu na vnitřní (nepohledové straně) zadního dílu překližky. Při pohledu na vnitřní stranu (zámky dolů) je to pravá hrana vnitřního otvoru. Zahlubte ji cca do hloubky 2 mm. 



Nalepte LED pásek na podpůrný díl. Musí být nalepený rovně, k tomu slouží vodící linky na dřevěném díle. Dávejte pozor, ať vývody směřují k výřezu na okraji.



BEZ LEPENÍ si sestavte spodní a zadní díl krabice, jak vidíte na obrázku. Do otvoru vložte 3D tištěný držák na fotorezistor, také ho NELEPTE.



Lepidlem Herkules nalepte překližku s LED páskem na zadní stěnu krabičky. Naneste malé množství lepidla tak, aby se nedostalo do prostoru uvnitř vodících čar. Je nutné díly slepit přesně tak, aby vodící čáry lícovaly s otvorem v zadní stěně překilžky. 




Slepené díly zatěžte a nechte uschnout.


<!-- _________________________________________________________________ -->
# <a name = lista>Ochrana dotykové lišty</a>

## Potřebujeme:
* Dotkyová lišta
* Papírová páska
* Malý zalamovací nůž



## Postup:
Nalepte pohledovou stranu (bez pájecích plošek) dotykové lišty na papírovou pásku.


Ořežte papírovou pásku přesně na rozměr lišty. Pásku nechte přilepenou, dokud v návodu nebude pokyn k jejímu sundání.



<!-- _________________________________________________________________ -->
# <a name = krabice>Slepení krabičky</a>

## Potřebujeme:
* Všechny díly krabice kromě víka
* Lepidlo Herkules
* Papírová páska




## Dobrá rada pro lepení:
Nanášejte vždy odpovídající množství lepidla. Pokud vám lepidlo po stlačení dílů vyteče na pohledové hraně, otřete ho papírovým ubrouskem směrem ven z krabice, nikdy ne dovnitř.



## Postup:
Slepte "ohrádku" ze zadní, přední, levé a pravé stěny krabičky. Zalepte první spoj, lepidlo naneste na všechny plochy, které se spojí. Slepený spoj poté stáhněte kusem pásky o délce cca 6 cm. Spodní překližkový díl zatím nelepte, ale použijte ho jako stojánek při lepení.





Stejně slepte i další rohy.




Před přilepením spodního dílu se ujistěte, že je správně otočený - je v něm výřez, který musí být blíž přední straně (bez LED pásku). Obdobným způsobem slepte "ohrádku" se spodním dílem. Papírovou páskou uchyťte všechny rohy a třemi pásy pásky délky cca 10 cm spojte krabičku tak, jak je vidět na obrázku. Při spojování dílů páskou vždy přidržte spojované díly tak, aby mezi nimi nebyla mezera.







<!-- _________________________________________________________________ -->
# <a name = osmicky>Vkládání difuzorů do segmentů</a>

## Potřebujeme:
* 4x 7-segment hodin (osmička)
* 28x Plexi segment hodin
* 1x dvojtečka
* 2x Plexi segment dvojtečky
* Kapesník / čistý hadr
* Inbus klíč vel. cca 3
* Jemný smirek (černý - 600)




## Postup:
Zkontrolujte všechny segmenty, jestli se na jejich hranách nenachází otřepy. Případné otřepy zbruste jemným smirkem. Stačí 1-2 tahy smirkem přes hranu.



Otřete kapesníkem všechny segmenty, které budete do osmiček a dvojtečky vkládat. 


Vsaďte segmenty do osmičky. Mají mírně lichoběžníkovitý tvar, do osmičky směřujte užší plochu segmentu. Jako první vsaďte spodní segment, poté postupujte směrem nahoru. Segmenty musíte vsazovat rovně, jinak se v tištěném díle vzpříčí. Pokud se to stane, nejjednoduší je segment vytáhnout a usadit znovu. Každý segment musí zapadnout do 3D tištěných západek.






Pokud je plast v okolí osmičky ohnutý, segment je nejspíš špatně usazený. Srovnejte ho, zkontrolujte, zda je zapadlý do zámků. Pokud je ohnutí jen mírné, je možné ho srovnat tak, že se 3D tištěný díl zmáčkne prsty.


Vsaďte plexi segmenty do dvojtečky. Tentokrát je vkládejte pod úhlem, jako první pod západku vložte širokou část. Tenkou část poté zatlačte inbus klíčem nebo podobnou širší koncovkou. 



<!-- _________________________________________________________________ -->
# <a name = lak>Lakování krabičky</a>

## Potřebujeme:
* Polyuretanový lak
* Slepená spodní část krabičky
* Víko krabičky
* Štětec
* Miska s vodou



## Postup:
Nalakujte pohledovou stranu víka (s gravírováním). Snažte se, aby lak nevniknul do otvorů v desce a do vygravírované prohlubně. Lak, který se do nich dostane, z nich odstraňte pomocí špejle, špachtle nebo párátka. Štětcem setřete přebytečný lak, který se usadil na hranách.



Sundejte ze spodní části krabice všechny pásky, které je držely při lepení. Natřete vnější plochy krabičky. Nechte ji uschnout tak, aby se natřené části nedotýkaly podložky (něčím krabičku podepřete). Štětcem setřete přebytečný lak, který se usadil na hranách. Lakem kompletně přetřete i LED pásek.

 


Štětec po dokončení lakování okamžitě ponořte do vody a vymyjte.

Ukliďte si pracovní plochu po předchozích krocích, tj. setřete prach vzniklý broušením (nejlépe mokrou hadrou nebo kapesníkem).

<!-- _________________________________________________________________ -->
# <a name = lak2>Druhá vrstva laku</a>

## Potřebujeme:
* Horní víko krabičky
* Spodní část krabičky
* Jemný smirkový papír (600 - černý)
* Polyuretanový lak
* Štětec, sklenice s vodou

## Postup:
Převědčte se, že první vrstva laku je vytvrzená. Poku ano, přebrušte lakované plochy. Většinou stačí méně než 10 tahů po každé ploše. Nebrušte LED pásek ani jeho okolí.


Přejeďte čistým prstem po vybroušeném povrchu a přesvědčte se, že je hladký.

Přebroušené povrchy nalakujte druhou vrstvou laku. Lak nechte vyschnout tak, aby se lakované části nedotýkaly podkladu (jako minule). Lak naneste znovu i k LED pásku.

Štětec po dokončení lakování okamžitě ponořte do vody a vymyjte.    

<!-- _________________________________________________________________ -->
# <a name = vlepeni>Vlepení lišty, fotorezistoru a spaceru</a>

## Potřebujeme:
* Fotorezistor napájený na přívodní kabel
* Dotyková lišta s napájeným kabelem
* Spacer pro desku plošných spojů
* Lepidlo Chemopren
* Libovolný šroub M3 a matka
* Párátko
* Šroubovák

## Postup:
Před slepením ověřte orientaci dotykové lišty, kabel musí směřovat k otvorům na osmičky. 



Vlepte dotykovou lištu do vygravírované prohlubně. Naneste lepidlo na obě lepené plochy. Lepidlo nanášejte pomocí párátka a rozetřete. Zatěžte.    




Vlepte fotorezistor s jeho držákem. Lepidlo naneste na zadní a spodní plochu držáku i dřeva. Přimáčkněte nejlépe svorkou.




Nalepte spacer do krabice. Musí být umístěn v blízkosti děr v boční ploše. Po nalepení ho stáhněte šroubem a matkou.




Tavnou pistolí zafixujte vývody dotykové lišty.



<!-- _________________________________________________________________ -->
# <a name = final>Finální sestavení</a>

## Potřebujeme:
* 4x osmička
* Dvojtečka
* Distanční vložky pro osmičky a dvojtečku
* 10x M3x25
* 1x M3x20
* 4x M3x30
* 15x M3 matka
* Nalakovaná krabice
* Obě části 3D tištěného nosníku
* Stojné nožky



## Postup:
Do horních otvorů na matky v nosnících vložte 5 matek. V případě potřeby je zatlačte o tvrdou podložku. Pokdu volně vypadávají, můžete je přichytit trochou lepidla.



Vložte desku plošných spojů do plastové osmičky. Stejně tak i do dvojtečky.



 

Plastovou osmičku vsuňte do první pozice včetně plastového distančního dílu. 




Do otvoru u kraje desky zasuňte předem šroub M3x25 se zápustnou hlavou.


Nosník vložte k první plastové osmičce. Do otvoru vložte matku a do ní zašroubujte první šroub. Nedotahujte.




Stejný postup zopakujte s druhou částí nosníku a osmičkou na poslední pozici.




Vložte ostatní osmičky a dvojtečku, jejich desky plošných spojů a distanční díly, přidejte k nim matky a zašroubujte. Pořád neutahujte.



Až jsou vložené všechny části, postupně šrouby utáhněte.
 


Zapojte konektor dotykové lišty na hlavní desku.


Spojte hlavní desku s osmičkami a dvojtečkou.
 



Zapojte fotorezistor a LED pásek.


Připevněte hlavní desku šroubem M3x20.


Vsuňte horní část sestavy do spodní, zasuňte na doraz. Pozor na kabely, neskřípněte je.


Na šrouby M3x30 nasuňte nožky. Šrouby s nožkami zašroubujte skrz otvory ve spodní části krabice.


Až bude mechanika kompletní, sundejte ochrannou pásku z dotykové lišty.


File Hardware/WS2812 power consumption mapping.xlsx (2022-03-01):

All LEDs, blue only
PWM value 8 bit | PSU current (mA) | LEDs only current (mA) | Current / LED (mA)
0 | 101 | 0 | 0.00000
1 | 102 | 1 | 0.01163
2 | 103 | 2 | 0.02326
3 | 104 | 3 | 0.03488
4 | 106 | 5 | 0.05814
5 | 107 | 6 | 0.06977
6 | 109 | 8 | 0.09302
7 | 110 | 9 | 0.10465
8 | 113 | 12 | 0.13953
9 | 116 | 15 | 0.17442
10 | 118 | 17 | 0.19767
11 | 121 | 20 | 0.23256
12 | 124 | 23 | 0.26744
13 | 127 | 26 | 0.30233
14 | 130 | 29 | 0.33721
15 | 132 | 31 | 0.36047
16 | 136 | 35 | 0.40698
17 | 138 | 37 | 0.43023
18 | 141 | 40 | 0.46512
19 | 144 | 43 | 0.50000
20 | 146 | 45 | 0.52326
21 | 148 | 47 | 0.54651
22 | 155 | 54 | 0.62791
23 | 159 | 58 | 0.67442
24 | 164 | 63 | 0.73256
25 | 170 | 69 | 0.80233
26 | 175 | 74 | 0.86047
27 | 180 | 79 | 0.91860
28 | 186 | 85 | 0.98837
29 | 191 | 90 | 1.04651
30 | 196 | 95 | 1.10465
31 | 201 | 100 | 1.16279
32 | 206 | 105 | 1.22093
33 | 211 | 110 | 1.27907
34 | 217 | 116 | 1.34884
35 | 222 | 121 | 1.40698
36 | 227 | 126 | 1.46512
37 | 232 | 131 | 1.52326
38 | 236 | 135 | 1.56977
39 | 241 | 140 | 1.62791
40 | 247 | 146 | 1.69767
41 | 253 | 152 | 1.76744
42 | 258 | 157 | 1.82558
43 | 264 | 163 | 1.89535
44 | 269 | 168 | 1.95349
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

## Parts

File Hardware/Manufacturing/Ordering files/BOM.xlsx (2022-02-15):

Comment | Designator | Footprint | LCSC Part Number
100nF | C1,C2 | Capacitor_SMD:C_0402_1005Metric | C1525
10uF | C22 | Capacitor_SMD:C_0603_1608Metric | C19702
WS2812E | D1,D2 | LED_SMD:LED_WS2812B_PLCC4_5.0x5.0mm_P3.2mm | C139127
75R | R1 | Resistor_SMD:R_0603_1608Metric | C4275
100n | C1,C4,C5,C6,C7,C12,C16,C18 | Capacitor_SMD:C_0603_1608Metric | C14663
10u | C2,C13,C14 | Capacitor_SMD:C_0805_2012Metric | C15850
1u | C3 | Capacitor_SMD:C_0603_1608Metric | C15849
6pF | C8,C9 | Capacitor_SMD:C_0603_1608Metric | C37474
B5819W | D1,D2 | Diode_SMD:D_SOD-123 | C8598
918-418K2023S40001 | J7 | Connector_USB:USB_C_Receptacle_HRO_TYPE-C-31-M-12 | C167321
2N7002 | Q1,Q4 | Package_TO_SOT_SMD:SOT-23 | C8545
S8050 | Q2,Q3 | Package_TO_SOT_SMD:SOT-23 | C2146
10K | R1,R2,R13,R15,R16,R17 | Resistor_SMD:R_0603_1608Metric | C25804
12K | R10,R11 | Resistor_SMD:R_0603_1608Metric | C22790
4K7 | R3 | Resistor_SMD:R_0603_1608Metric | C23162
5K1 | R4,R5,R6,R7 | Resistor_SMD:R_0603_1608Metric | C23186
470R | R8,R9 | Resistor_SMD:R_0603_1608Metric | C23179
ESP32-WROOM-32D | U1 | RF_Module:ESP32-WROOM-32 | C473012
DS1302ZN+ | U3 | Package_SO:SOIC-8_3.9x4.9mm_P1.27mm | C910859
AMS1117-3.3 | U4 | Package_TO_SOT_SMD:SOT-223-3_TabPin2 | C6186
CH340G | U5 | Package_SO:SOIC-16_3.9x9.9mm_P1.27mm | C84681
100nF | C1,C2,C3,C4,C5,C6,C7,C8,C9,C10,C11,C12,C13,C14,C15,C16,C17,C18,C19,C20,C21 | Capacitor_SMD:C_0402_1005Metric | C1525
10uF | C22 | Capacitor_SMD:C_0603_1608Metric | C19702
WS2812E | D1,D2,D3,D4,D5,D6,D7,D8,D9,D10,D11,D12,D13,D14,D15,D16,D17,D18,D19,D20,D21 | LED_SMD:LED_WS2812B_PLCC4_5.0x5.0mm_P3.2mm | C139127
75R | R1 | Resistor_SMD:R_0603_1608Metric | C4275
100nF | C1,C2,C3,C4,C5,C6,C7,C8,C9,C10,C11,C12,C13,C14,C15,C16,C17,C18,C19,C20,C21 | Capacitor_SMD:C_0402_1005Metric | C1525
10uF | C22 | Capacitor_SMD:C_0603_1608Metric | C19702
WS2812E | D1,D2,D3,D4,D5,D6,D7,D8,D9,D10,D11,D12,D13,D14,D15,D16,D17,D18,D19,D20,D21 | LED_SMD:LED_WS2812B_PLCC4_5.0x5.0mm_P3.2mm | C139127
75R | R1 | Resistor_SMD:R_0603_1608Metric | C4275
100nF | C1,C2,C3,C4,C5,C6,C7,C8,C9,C10,C11,C12,C13,C14,C15,C16,C17,C18,C19,C20,C21 | Capacitor_SMD:C_0402_1005Metric | C1525
10uF | C22 | Capacitor_SMD:C_0603_1608Metric | C19702
WS2812E | D1,D2,D3,D4,D5,D6,D7,D8,D9,D10,D11,D12,D13,D14,D15,D16,D17,D18,D19,D20,D21 | LED_SMD:LED_WS2812B_PLCC4_5.0x5.0mm_P3.2mm | C139127
75R | R1 | Resistor_SMD:R_0603_1608Metric | C4275
100nF | C1,C2,C3,C4,C5,C6,C7,C8,C9,C10,C11,C12,C13,C14,C15,C16,C17,C18,C19,C20,C21 | Capacitor_SMD:C_0402_1005Metric | C1525
10uF | C22 | Capacitor_SMD:C_0603_1608Metric | C19702
WS2812E | D1,D2,D3,D4,D5,D6,D7,D8,D9,D10,D11,D12,D13,D14,D15,D16,D17,D18,D19,D20,D21 | LED_SMD:LED_WS2812B_PLCC4_5.0x5.0mm_P3.2mm | C139127
75R | R1 | Resistor_SMD:R_0603_1608Metric | C4275

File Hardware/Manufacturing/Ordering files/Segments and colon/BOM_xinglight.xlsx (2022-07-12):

Comment | Designator | Footprint | LCSC Part Number
100nF | C1,C2,C3,C4,C5,C6,C7,C8,C9,C10,C11,C12,C13,C14,C15,C16,C17,C18,C19,C20,C21 | Capacitor_SMD:C_0402_1005Metric | C1525
10uF | C22 | Capacitor_SMD:C_0603_1608Metric | C19702
470R | R1 | Resistor_SMD:R_0603_1608Metric | C23179
WS2812 Xinglight | D1,D2,D3,D4,D5,D6,D7,D8,D9, D10,D11,D12,D13,D14,D15,D16,D17,D18,D19,D20,D21 | LED_SMD:LED_WS2812B_PLCC4_5.0x5.0mm_P3.2mm | C2843785

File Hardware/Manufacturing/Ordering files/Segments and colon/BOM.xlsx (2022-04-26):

Comment | Designator | Footprint | LCSC Part Number
100nF | C1,C2,C3,C4,C5,C6,C7,C8,C9,C10,C11,C12,C13,C14,C15,C16,C17,C18,C19,C20,C21 | Capacitor_SMD:C_0402_1005Metric | C1525
10uF | C22 | Capacitor_SMD:C_0603_1608Metric | C19702
WS2812 Worldsemi | D1,D2,D3,D4,D5,D6,D7,D8,D9 | LED_SMD:LED_WS2812B_PLCC4_5.0x5.0mm_P3.2mm | C2761795
470R | R1 | Resistor_SMD:R_0603_1608Metric | C23179
WS2812 Xinglight | D10,D11,D12,D13,D14,D15,D16,D17,D18,D19,D20,D21 | LED_SMD:LED_WS2812B_PLCC4_5.0x5.0mm_P3.2mm | C2843785

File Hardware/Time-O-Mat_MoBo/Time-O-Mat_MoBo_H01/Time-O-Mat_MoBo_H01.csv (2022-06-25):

Comment | Designator | Footprint | LCSC
Buzzer | BZ1 | Time-O-Mat_Library:Buzzer_12x9.5RM6.6
100n | C1,C4,C5,C6,C7,C12,C16,C18 | Capacitor_SMD:C_0603_1608Metric | C14663
70mF | C10 | Time-O-Mat_Library:SM3R3703T01U | C396469
100u | C11,C19 | Capacitor_THT:CP_Radial_D5.0mm_P2.00mm | C43803
10u | C13 | Capacitor_SMD:C_0603_1608Metric | C19702
10u | C2,C14 | Capacitor_SMD:C_0805_2012Metric | C15850
1u | C3 | Capacitor_SMD:C_0603_1608Metric | C15849
6pF | C8,C9 | Capacitor_SMD:C_0603_1608Metric | C37474
B5819W | D1,D2,D5 | Diode_SMD:D_SOD-123 | C8598
3V3 | D3 | Diode_SMD:D_MiniMELF | C8056
5V6 | D4 | Diode_SMD:D_MiniMELF | C8062
CoufalElektronika_logo | G1 | Time-O-Mat_Library:Coufal_elektronika_text_30x13mm
Vedatori_logo | G2 | Time-O-Mat_Library:Vedatori_copper_exposed_15mm
Vedatori_logo | G3 | Time-O-Mat_Library:Vedatori_15mm
Espressif_logo | G5 | Time-O-Mat_Library:Espressif_logo_30mm
MountingHole | H1,H2,H3,H4,H5,H6 | MountingHole:MountingHole_3.2mm_M3
Conn_02x04_Odd_Even | J1,J2,J3,J4,J5 | Connector_PinHeader_2.54mm:PinHeader_2x04_P2.54mm_Vertical
Conn_01x06_Male | J6 | Connector_JST:JST_XH_B6B-XH-A_1x06_P2.50mm_Vertical
918-418K2023S40001 | J7 | Connector_USB:USB_C_Receptacle_HRO_TYPE-C-31-M-12 | C167321
Conn_01x03 | J8 | Connector_PinHeader_2.54mm:PinHeader_1x03_P2.54mm_Vertical
Conn_01x05_Male | J9 | Connector_PinHeader_2.54mm:PinHeader_1x05_P2.54mm_Vertical
2N7002 | Q1,Q4 | Package_TO_SOT_SMD:SOT-23 | C8545
S8050 | Q2,Q3 | Package_TO_SOT_SMD:SOT-23 | C2146
10K | R1,R2,R13,R15,R18,R19 | Resistor_SMD:R_0603_1608Metric | C25804
12K | R10,R11 | Resistor_SMD:R_0603_1608Metric | C22790
R_Photo | R12,R14 | OptoDevice:R_LDR_5.1x4.3mm_P3.4mm_Vertical
1K | R16,R17 | Resistor_SMD:R_0603_1608Metric | C21190
100K | R20 | Resistor_SMD:R_0603_1608Metric | C25803
4K7 | R3 | Resistor_SMD:R_0603_1608Metric | C23162
5K1 | R4,R5,R6,R7 | Resistor_SMD:R_0603_1608Metric | C23186
470R | R8,R9 | Resistor_SMD:R_0603_1608Metric | C23179
SW_SPST | RESET1 | Button_Switch_SMD:SW_SPST_TL3342 | C318884
SW_SPST | SW1,SW2,SW3 | Button_Switch_THT:SW_Tactile_SPST_Angled_PTS645Vx83-2LFS
TestPoint | TPGND1,TP+5V1 | Connector_Wire:SolderWirePad_1x01_SMD_1x2mm
ESP32-WROOM-32D | U1 | RF_Module:ESP32-WROOM-32 | C473012
DS18B20 | U2 | Package_TO_SOT_THT:TO-92_HandSolder
DS1302ZN+ | U3 | Package_SO:SOIC-8_3.9x4.9mm_P1.27mm | C910859
AMS1117-3.3 | U4 | Package_TO_SOT_SMD:SOT-223-3_TabPin2 | C6186
CH340G | U5 | Package_SO:SOIC-16_3.9x9.9mm_P1.27mm | C84681
Crystal_GND2 | Y1 | Crystal:Crystal_DS26_D2.0mm_L6.0mm_Horizontal_1EP_style2

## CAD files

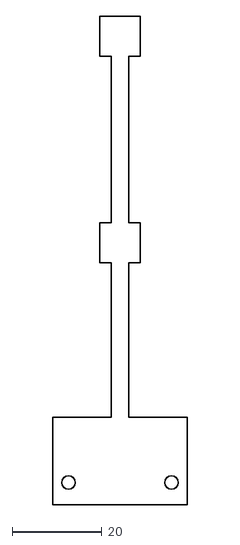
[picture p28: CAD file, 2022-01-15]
Hardware/Time-O-Mat_Colon/Eight v2 - Dot PCB outline.dxf
30.0 x 109.2

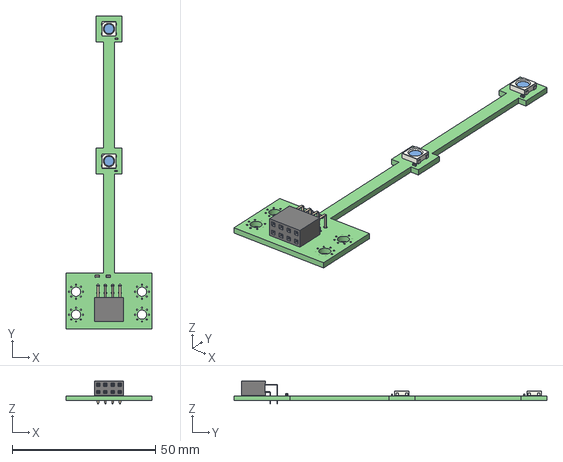
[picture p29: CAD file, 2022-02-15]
Hardware/Time-O-Mat_Colon/Time-O-Mat_Colon_H00/Time-O-Mat_Colon_H00.step
30.0 x 109.2 x 7.98 mm
Time-O-Mat_Colon_H00 PCB

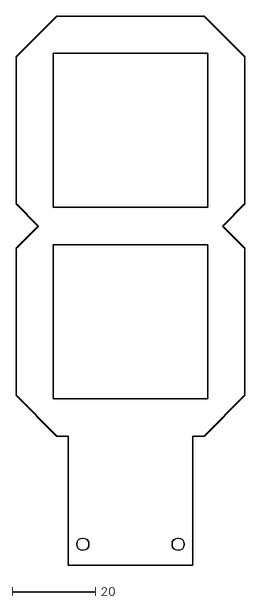
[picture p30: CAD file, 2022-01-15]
Hardware/Time-O-Mat_SegmentDisplay/Eight v2 - PCB outline (1).dxf
55.1 x 132.3

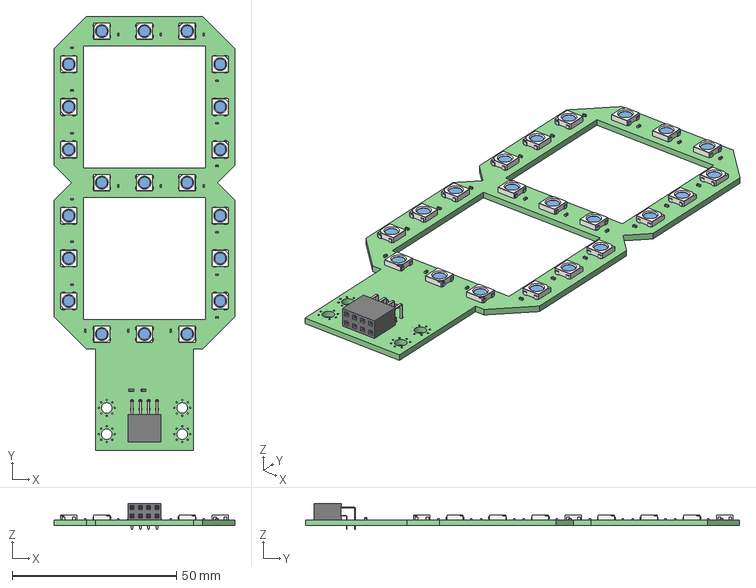
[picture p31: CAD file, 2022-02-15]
Hardware/Time-O-Mat_SegmentDisplay/Time-O-Mat_SegmentDisplay_H00/Time-O-Mat_SegmentDisplay_H00.step
55.1 x 132.3 x 7.98 mm
Time-O-Mat_SegmentDisplay_H00 PCB

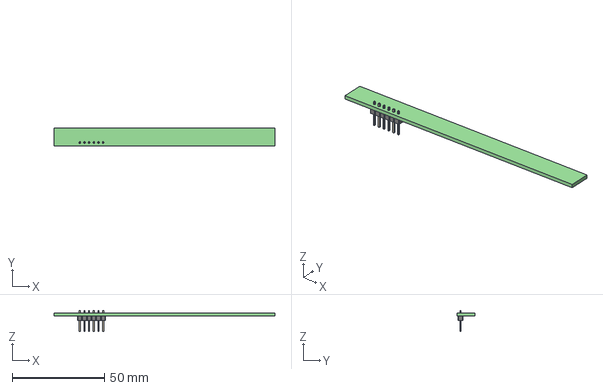
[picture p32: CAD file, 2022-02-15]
Hardware/Time-O-Mat_TouchBar/Time-O-Mat_TouchBar_H00/Time-O-Mat_TouchBar_H00.step
120.0 x 10.0 x 11.5 mm
Time-O-Mat_TouchBar_H00 PCB

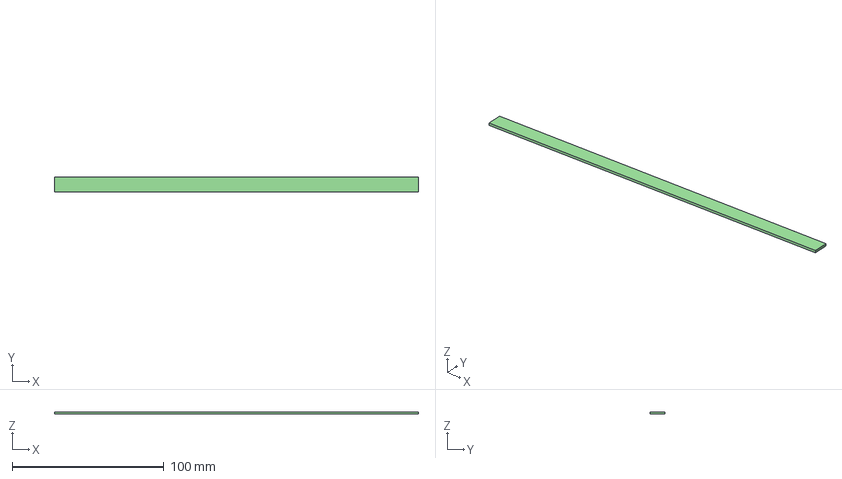
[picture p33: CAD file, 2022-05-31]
Hardware/Time-O-Mat_TouchBar/Time-O-Mat_TouchBar_H01/Time-O-Mat_TouchBar_H01.step
240.0 x 10.0 x 1.60 mm

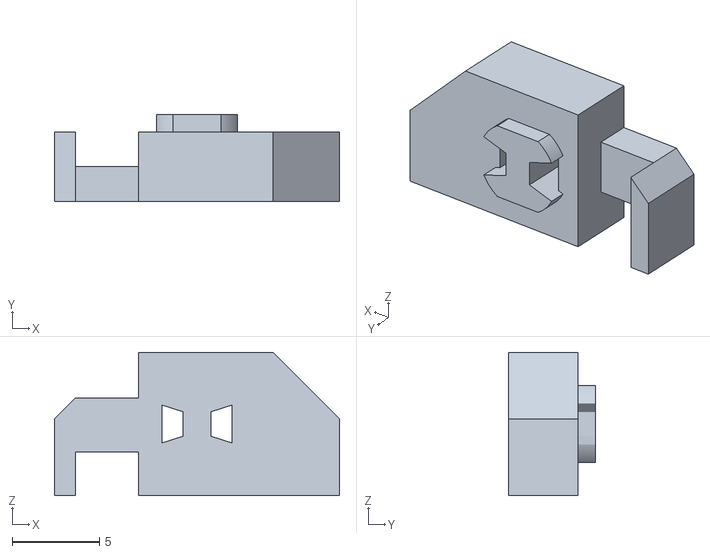
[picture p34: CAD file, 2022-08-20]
Mechanics/Box/Box - Photoresistor bracket 3DP.stl
16.3 x 5.00 x 8.20

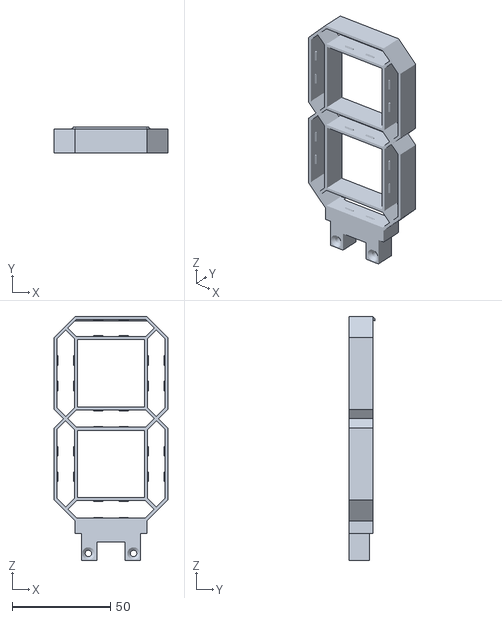
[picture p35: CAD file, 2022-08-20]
Mechanics/Eight/Eight v3 - Eight 3DP.stl
57.9 x 13.0 x 124.3

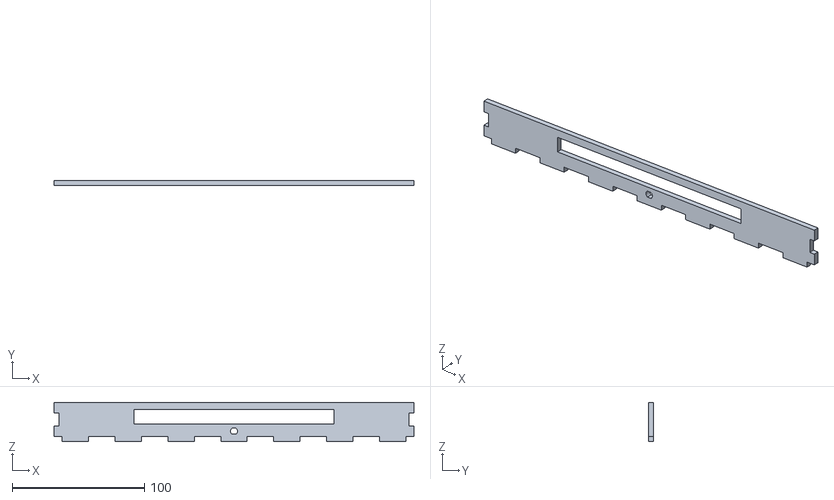
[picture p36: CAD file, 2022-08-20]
Mechanics/Box/Box - Back.stl
272.0 x 3.80 x 29.8

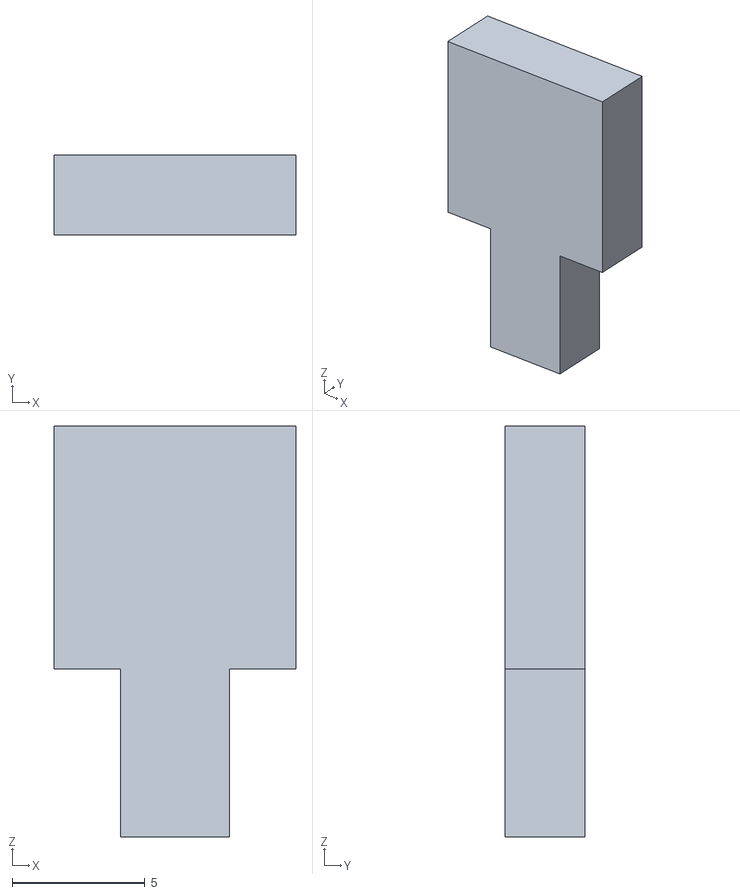
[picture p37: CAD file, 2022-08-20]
Mechanics/Eight/Eight v3 - Diff dot.stl
9.10 x 3.00 x 15.5

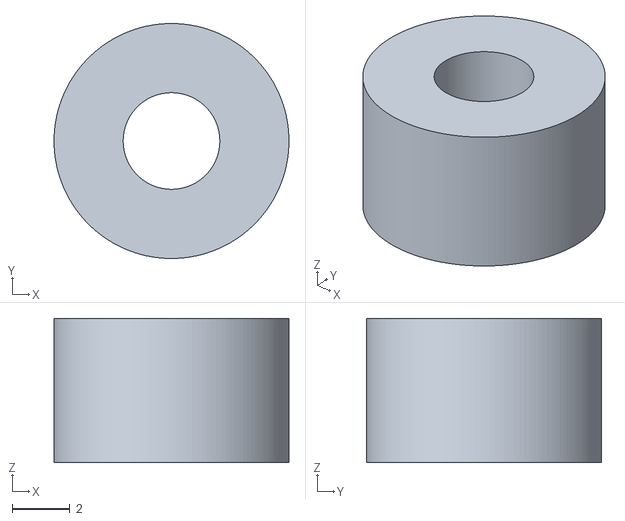
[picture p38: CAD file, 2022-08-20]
Mechanics/Box/Box - Spacer 3DP.stl
8.15 x 8.15 x 5.00

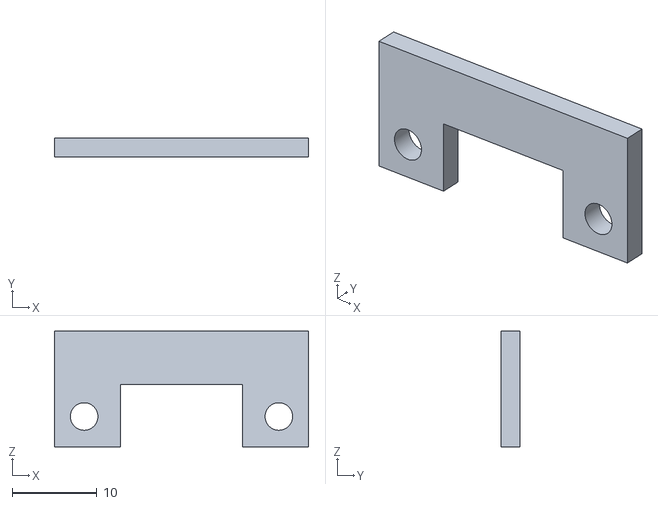
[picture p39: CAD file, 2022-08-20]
Mechanics/Eight/Eight v3 - Eight spacer 3DP.stl
30.0 x 2.25 x 13.7

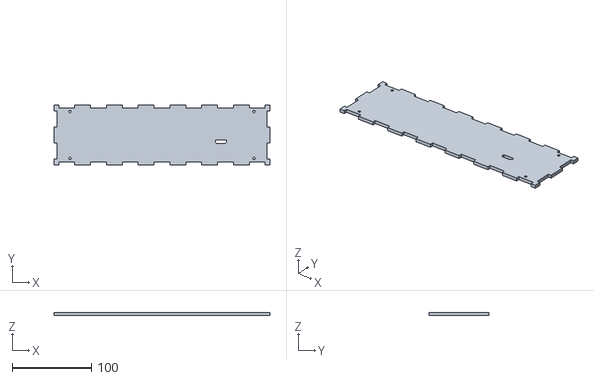
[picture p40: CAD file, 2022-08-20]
Mechanics/Box/Box - Bottom.stl
272.0 x 76.0 x 3.80

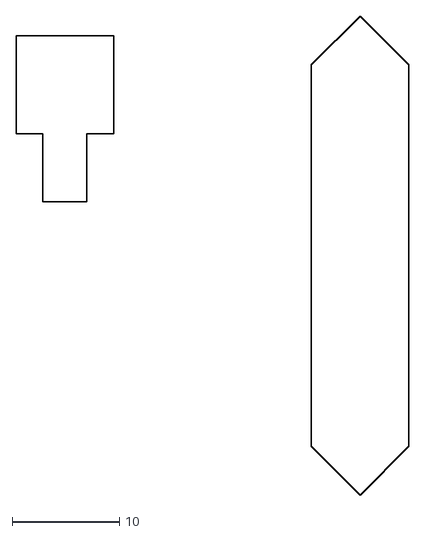
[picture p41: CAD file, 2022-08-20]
Mechanics/Eight/Eight v3 segments.dxf
36.6 x 44.6

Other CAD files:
Mechanics/Box/Box - Front.stl
Mechanics/Eight/Eight v3 - Dot 3DP.stl
Mechanics/Box/Box - Top.stl
Mechanics/Eight/Eight v3 - Diffuser.stl
Mechanics/Box/Box - Holder pt1 3DP.stl
Mechanics/Box/Box - Holder pt2 3DP.stl
Mechanics/Box/Box - LED strip bracket.stl
Mechanics/Box/Box - Left.stl
Mechanics/Box/Box - Right.stl
Mechanics/Box/Box - Stand 3DP.stl
Mechanics/Box/box.dxf
Mechanics/Eight/Eight v3 - Dot spacer 3DP.stl

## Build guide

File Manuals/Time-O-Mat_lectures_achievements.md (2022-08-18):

V tomto dokumentu se nachází rozpis programovacích lekcí a zadání programovacích úkolů. 

**Programovací lekce** nejsou povinné, ale jsou velmi vhodné pro začátečníky. Zájem o lekci budete vyjadřovat tak, že na svůj řádek v tabulce připíšete na konec číslo lekce, o kterou máte zájem. Jakmile jste lekci absolvovali, číslo zakroužkujete tak, aby bylo jasné, které lekce už jste absolvovali. Účast na lekci je ohodnocena 1 Chotěcoinem.

**Programovací úkoly** jsou úkoly, které budete řešit samostatně. Ke každému úkolu potřebujete soubor znalostí, který je obsažen v některých z lekcí. Úkoly je však možné řešit i jen pomocí programovacího manuálu (pro pokročilé). Splnění úkolu bude kontrolovat vedoucí a odmění ho 2 - 4 Chotěcoiny. Po splnění úkolu si v tabulce na vašem řádku zaznačte křížkem jeho splnění. 

# Lekce 0
Zprovozníme programovací prostředí VS Code + PlatformIO tak, abyste mohli nahrát kód do Time-O-Mat z vašeho PC.

## Úkol 0 - Blikání LED
Pomocí kódu z manuálu rozsvítit LED.

# Lekce 1
Rozblikáme LED na digitech nebo LED pásku.

## Výsledný kód

```
#include "ToMat/ToMat.h"

void setup() {
    ToMat.begin();
}

void loop() {
    ToMat.display.setLED(0, 5, blue);
    delay(500);

    ToMat.display.setLED(0, 5, black);
    delay(500);    
}
```

## Úkol 1 - Blikání LED
Napište program, který bude blikat druhou LED na nultém digitu. Doba svitu i doba zhasnutí je 300 ms.

## Úkol 2 - Záblesky LED
Napište program, který každou vteřinu krátce zobrazí číslo 1 na posledním digitu. Doba zobrazení je 100 ms v každé vteřině.

## Úkol 3 - Železniční přejezd
Napište program, který bude blikat jako železniční přejezd. Blikat budou levý a pravý horní segment na jednom digitu, oba červenou barvou.

# Lekce 2
Přečteme stav tlačítka, ukážeme si binární proměnnou a v závislosti na ní rozezníme piezoakustický měnič.

## Výsledný kód

```
#include "ToMat/ToMat.h"

void setup() {
    ToMat.begin();
}

void loop() {
    if(ToMat.buttonRead(0)) {
        ToMat.piezo.tone(100);
    }
    else {
        ToMat.piezo.stop();
    }
    delay(20);
}
```

## Úkol 4 - Manuální blikání LED
Napište program, který bliká libovolnou LED pouze při stisknutém tlačítku nejblíž USB konektoru. Doba svícení je 200 ms. Doba zhasnutí je 200 ms.

## Úkol 5 - Stabilní stav LED
Napište program, který bude stiskem tlačítka přepínat svícení dvou různých segmentů na dvou různách digitech. Vždy bude svítit pouze jeden segment, stiskem tlačítka se tento segment vypne a zapne se ten druhý. Dalším stiskem tlačítka se znovu zapne pouze ten původní segment a proces lze opakovat.

# Lekce 3
Přečteme hodnotu na fotorezistoru, ukážeme si číselnou proměnnou. Hodnotu výstupu z fotorezistoru si zobrazíme na LED.

## Výsledný kód

```
#include "ToMat/ToMat.h"

void setup() {
    ToMat.begin();
}

int x;

void loop() {
    ToMat.display.setFront(black);
    x = (ToMat.illumination.getRaw(0)/205);
    ToMat.display.setLED(0, x, blue);
    printf("%d \n ", x);
    delay(20);
}
```

## Úkol 6 - Rychlost blikání
Napište program, který bude blikat libovolným segmentem a rychlost tohoto blikání se zvětší, když se sníží intenzita osvětlení na předním fotorezistoru (např. bude zakrytý prstem).

## Úkol 7 - Počítadlo stisků tlačítka
Napište program, který počítá, kolikrát bylo stisknuto tlačítko SW1. Při resetování programu se počítadlo vynuluje. Pokud chceme zjistit, kolikrát bylo tlačítko SW1 stisknuto, musíme stisknout tlačítko SW2 a program musí pípnout daným počtem pípnutí.

# Lekce 4
Ukážeme si podmínku "if" na příkladu s LED. Pro ovládání se naučíme použít dotykovou lištu. 

```
#include "ToMat/ToMat.h"

void setup() {
    ToMat.begin();
}

void loop() {
    ToMat.display.setFront(black);
    if(ToMat.touchBar.getPressed(2)) {
        ToMat.display.setLED(1, 0, green);
    }
    else if(ToMat.touchBar.getPressed(3)) {
        ToMat.display.setLED(1, 2, green);
    }
    else {
        ToMat.display.setLED(1, 1, red);
    }
    delay(20);
}
```

## Úkol 8 - Zvuková signaliazce tmy
Napište program, který rozezní piezoakustický měnič, pokud Time-O-Mat vneseme do temnoty.

## Úkol 9 - Nastavení jasu LED po stisku tlačítka
Napište program, který při každém stisku jednoho z tlačítek na dotykové liště rozsvítí další LED v rámci jednoho segmentu a původní LED zhasne - "posune" světlo na LED na další pozici(začne se LED s indexem 0 a vždy se zvyšuje o 1). Po dosažení poslední LED se znovu rozsvítí nultá LED a proces se opakuje. Pokud není tlačítlo stisknuto, pořád svítí stejná LED.

# Lekce 5
Time-O-Mat začne komunikovat s počítačem pomocí sériové linky. Vyčteme okolní teplotu.

```
#include "ToMat/ToMat.h"

void setup() {
    ToMat.begin();
}

int teplota;

void loop() {
    teplota = ToMat.getTemperature();
    printf("%d\n", teplota);
    delay(200);
}
```

## Úkol 10 - Vypsání hodnoty LED
Přepracujte úkol 9 tak, aby Time-O-Mat přes sériovou linku přenášel číslo LED, která právě svítí.

## Úkol 11 - Vyslání času od startu Time-O-Mat bez funkce millis()
Napište program, který bude vypisovat celočíselnou proměnnou každou vteřinu. Tuto proměnnou však každou milisekundu zvyšte o 1. Je chování tohoto programu stejné jako v případě použití funkce `millis()`?

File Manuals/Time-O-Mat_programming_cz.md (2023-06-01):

Toto je návod na programování hodin Time-O-Mat. Začneme instalací vývojového prostředí na váš PC, následně si ukážeme základní pravidla programovacího jazyka C++ a poté začneme využívat funkce výrobku Time-O-Mat.

V tomto návodu se budeme zabývat programováním mikrokontroléru (mikropočítače) ESP32. K tomu je od výrobce ESP32 připraven framework (sada nástrojů urychlujících vývoj) ESP-IDF v jazyce C. Nadstavbou tohoto frameworku je další framework [arduino-esp32](https://github.com/espressif/arduino-esp32), který přidává další sadu nástrojů a je již napsán v jazyce C++. Arduino-esp32 používáme v našem projektu pro Time-O-Mat. Bylo k němu potřeba přidat množství kódu (knihovna *Time-O-Mat*), který se stará o *základní životní funkce* Time-O-Mat a umožňuje jednodušší používání jeho funkcionalit (z `main.cpp`). V tomto návodě se budeme zabývat jen uživatelským pohledem na používání knihovny *Time-O-Mat*.

___
# Obsah
* [Vývojové prostředí](#IDE)
* [Nahrání demo programu - kontrola](#kontrola)
* [Ovládání demo programu](#ovladani)
* [Nový projekt](#novyprojekt)
* [První program](#prvniprogram)
* [Komentáře](#komentare)
* [Proměnné](#promenne)
* [Podmínky](#podminky)
* [Cyklus](#cyklus)
* [Funkce](#funkce)
* [LEDky](#ledky)
* [Tlačítka](#tlacitka)
* [Piezoakustický měnič](#piezo)
* [Fotorezistory](#fotorezistory)
* [Dotyková lišta](#lista)
* [Teploměr](#teplomer)
* [Sériová linka](#seriovka)
* [Displej a podsvícení](#displej)
* [WiFi](#wifi)
* [Vzdálený příkazový řádek](#prikazy)
___

<!-- _________________________________________________________________ -->
# <a name = IDE>Vývojové prostředí</a>

Pro programování Time-O-Mat je použito vývojové prostředí [Visual Studio Code](https://code.visualstudio.com/download) s rozšířením PlatformIO. Pro instalaci prostředí a rozšíření můžete použít tento [návod](https://docs.platformio.org/en/latest/ide/vscode.html#installation), jehož hlavní část je na obrázku níže:

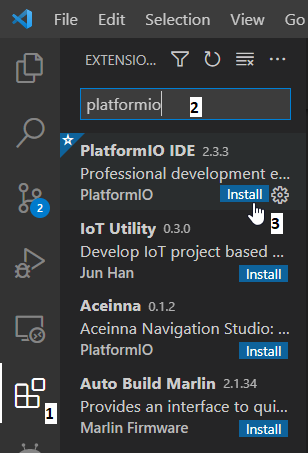
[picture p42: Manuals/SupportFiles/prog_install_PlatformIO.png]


<!-- _________________________________________________________________ -->
# <a name = kontrola>Nahrání demo programu - kontrola</a>

V této části nahrajete do Time-O-Mat připravený program pro jeho otestování. Program umožňuje připojení Time-O-Mat k WiFi a zobrazení aktuálního času.

Pro naprogramování Time-O-Mat si stáhněte [tento repozitář](https://github.com/vedatori/Time-O-Mat/archive/refs/heads/main.zip). Stáhnutý soubor *Time-O-Mat-main.zip* si rozbalte na disk svého PC na libovolnou lokaci tak, abyste ho našli. 
**Pozor:** PlatformIO nedokáže pracovat s diakritikou v cestě k projektu. Projekt tedy nesmí být součástí složky, která má diakritiku v názvu. Všechny projekty musí být uloženy v cestě bez háčků a čárek!
Pokud vaše uživatelské jméno obsahuje diakritiku, tak nemůžete používat Plochu ani složku Dokumenty, ale musíte vytvořit například *C:/Vedatori/Time-O-Mat-main*.

Ve VS Code otevřete nabídku *File*, klikněte na *Open Folder* a zvolte složku *Software/demo_project* z dříve rozbalené složky-repozitáře *Time-O-Mat-main*.

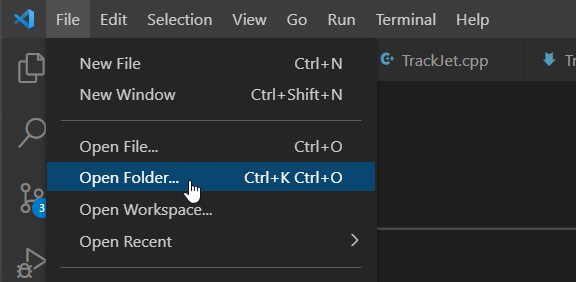
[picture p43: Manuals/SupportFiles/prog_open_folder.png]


Otevřete soubor *main.cpp* který je v cestě *demo_project/src/main.cpp*.

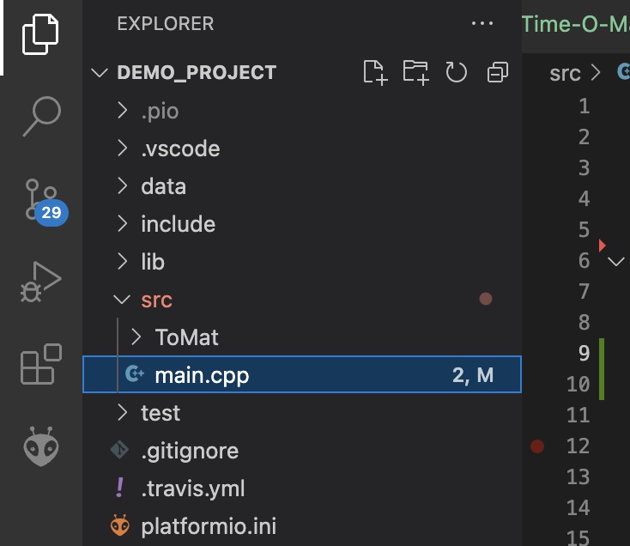
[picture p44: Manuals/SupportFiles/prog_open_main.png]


V souboru *main.cpp* upravte název výrobku "<your_name>" tak, aby byl poznatelný, např. jako "Franta" nebo "FrantaFlinta". 
Je možné přidat i heslo pro přihlašování např. takto
"`Time-O-Mat.startWiFiCaptain("<your_name>", "12345678");`".
Heslo musí mít minimálně 8 znaků, jinak nebude použito.

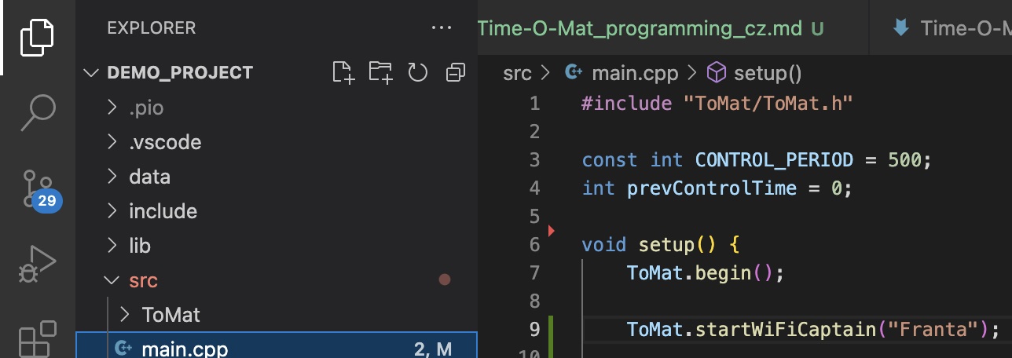
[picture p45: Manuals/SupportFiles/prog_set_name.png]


Po otevření projektu bude VS Code chvíli pracovat. Pokud ještě pracuje, počkejte, dokud text na dolní liště nezmizí.



Připojte Time-O-Mat pomocí USB-C kabelu k PC.

V dolní liště PlatformIO stiskněte šipku a tím nahrejte program do Time-O-Mat.



Počkejte, až se dokončí nahrávání a zobrazí v dolním terminálu *SUCCESS*.

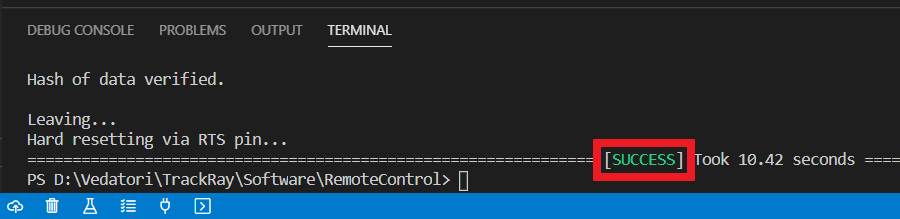
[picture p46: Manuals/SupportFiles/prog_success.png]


V dolní liště PlatformIO stiskněte tlačítko úplně v pravo a tím spusťe PlatformIO terminál.

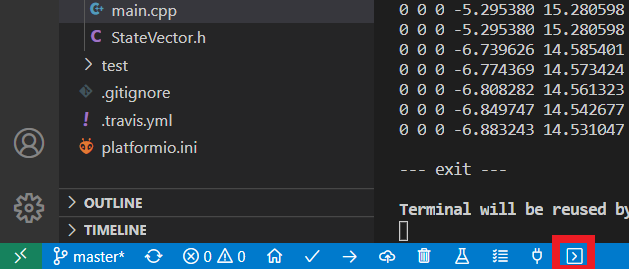
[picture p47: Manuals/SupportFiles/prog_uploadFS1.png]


Do nově otevřeného termínálu v dolní částí VS Code zadejte příkaz `pio run -t uploadfs` a stiskněte *ENTER*.

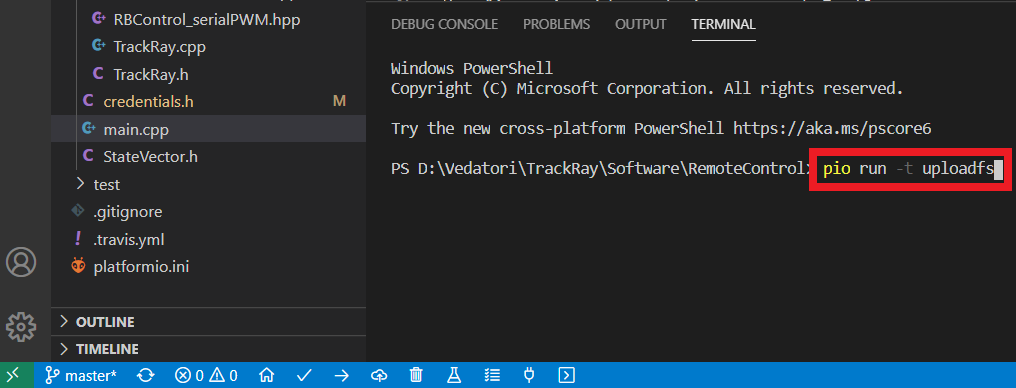
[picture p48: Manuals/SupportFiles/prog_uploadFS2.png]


Počkejte, až se dokončí nahrávání a zobrazí v dolním terminálu *SUCCESS*.



Nyní je výrobek plně naprogramován. Pro ovládání na svém chytrém zařízení vyhledejte WiFi síť s názvem *Time-O-Mat_<your_name>*. Zadejte do webového prohlížeče adresu *192.168.4.1* nebo jakoukoli jinou ve tvaru *www.neco.cz*. Načte se hlavní stránka pro ovládání Time-O-Mat.

Pro přihlášení Time-O-Mat k externí WiFi síti klikněte na tlačítko *WiFi setup*. Po delší chvíli se zobrazí stránka s dostupnými WiFi sítěmi. Zde zadejte přihlašovací údaje od externí WiFi a potvrďte přihlášení.

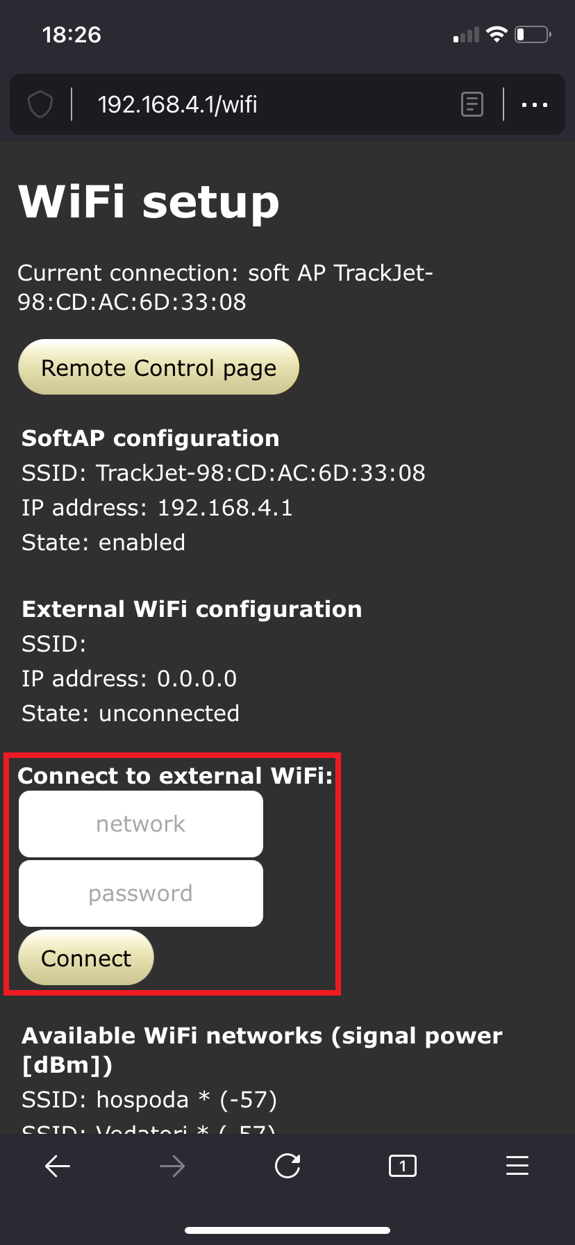
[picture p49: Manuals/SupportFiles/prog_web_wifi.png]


Pokud přihlášení k externí WiFi proběhne úspěšně, objeví se potvrzení *connected* a přidělená IP adresa. Tato síť bude uložena a vyhledána i po restartu. Připojte se se svým chytrým zařízením také na externí WiFi a zadejte do prohlížeče IP adresu přidělenou Time-O-Mat. V tomto případě *192.168.88.197*.

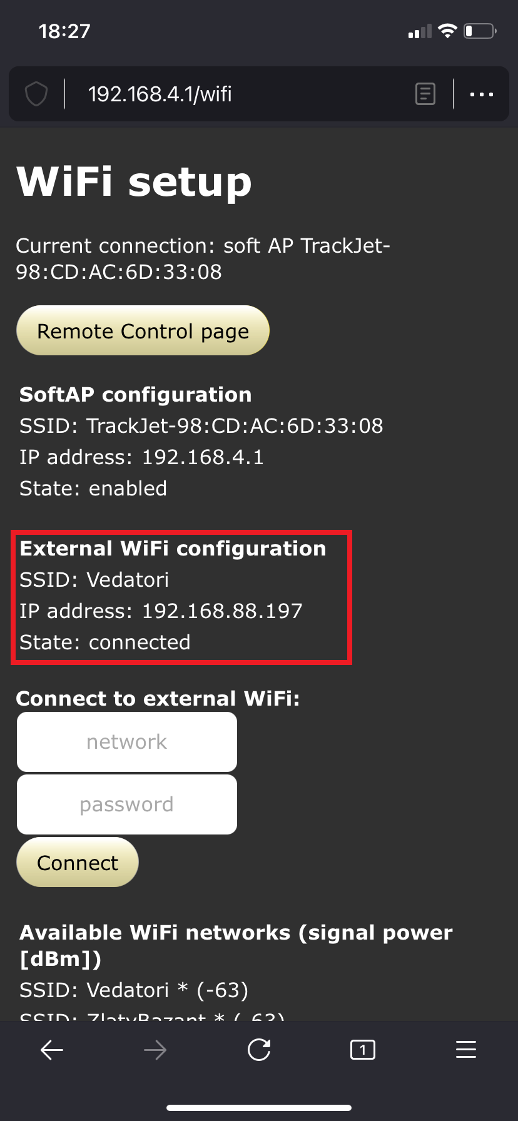
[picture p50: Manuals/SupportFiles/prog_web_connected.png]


Načte se opět hlavní stránka ovládání Time-O-Mat. Tímto je vypnuta interní WiFi *Time-O-Mat_<your_name>*. Pro její opětovné zapnutí přejděte do nastavení WiFi a klikněte na tlačítko *Enable AP* nebo restartujte Time-O-Mat.

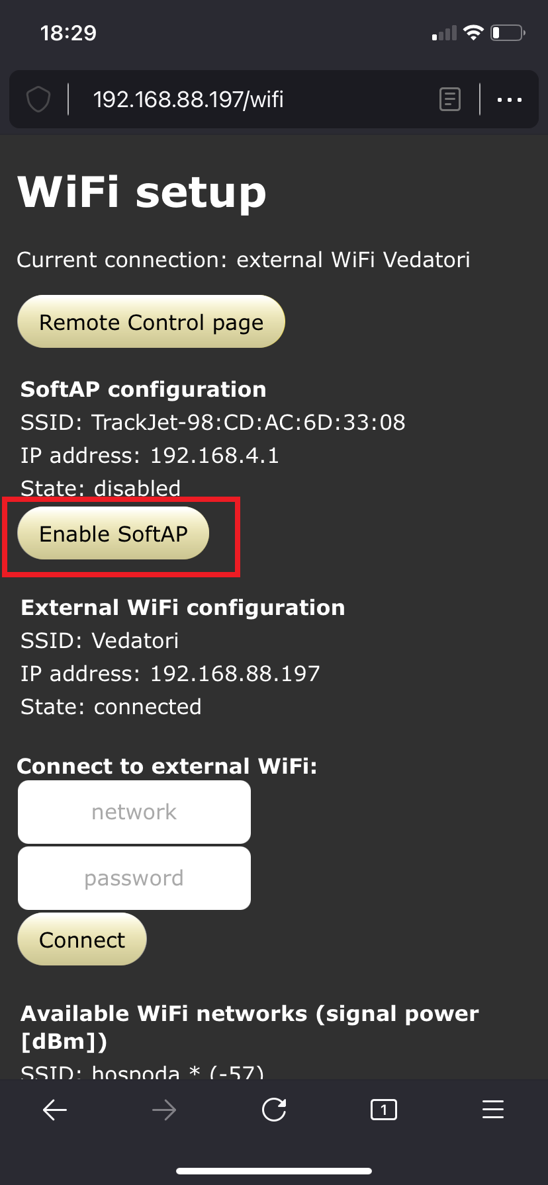
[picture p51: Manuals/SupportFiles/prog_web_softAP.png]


Demo program umožňuje také nastavení Time-O-Mat.
* Nastavení času pomocí tlačítek: 
* Nastavení času pomocí webového rozhraní: 
* Nastavení barvy displeje pomocí tlačítek: 
* Nastavení barvy displeje pomocí webového rozhraní: 
* 
* 

<!-- _________________________________________________________________ -->
# <a name = ovladani>Ovládání demo programu</a>

Time-O-Mat je možné skrze právě nahraný demo program uživatelsky ovládat a nastavovat jeho parametry. Jedná se o uživatelské funkce Time-O-Mat SW knihovny, které jsou zpravidla nastaveny v hlavním souboru *main.cpp*. Zde je také možné je jednoduše měnit a přizpůsobovat si funkčnost Time-O-Matu. Demo program je možné ovládat násedujícími způsoby:

## Fyzická tlačítka a dotyková lišta
* Nastavení času: Při přidržení tlačítka 0 na levé straně (nejdále od displeje) a dotýkání se 2 dotykových tlačítek nejvíce vlevo je možné nastavit čas po minutách dolů (levé) a nahoru (pravé). Po tomto nastavení se přestane synchronizovat čas s internetovým časem až do restartu.
* Nastavení barvy displeje: Při přidržení tlačítka 0 na levé straně (nejdále od displeje) a dotýkání se zleva 3. a 4. dotykového tlačítka je možné nastavit červenou složku barvy displeje. Levým ubereme a pravým přidáme na intenzitě. Pro zelenou složku použijeme 5. a 6. dotykové tlačítko. Pro modrou složku použijeme 7. a 8. tlačítko.
* Zahrání táborové znělky: Stiskem tlačítka 1 na levé straně (uprostřed) spustíme demo skladbu *Maniac*.
* Reset: Stiskem tlačítka 2 na levé straně (nejblíže displeji) resetujeme Time-O-Mat.

## Webové rozhraní
* Nastavení času: Do pole *Command entry* zadáme příkaz je ve tvaru `settime HH MM`. Parametry `HH` a `MM` odpovídají hodinám a minutám. Například pro nastavení času 12:34 použijeme příkaz `settime 12 34`. Příkaz odešleme stiskem tlačítka *Enter*.
* Nastavení časové zóny: Do pole *Command entry* zadáme příkaz je ve tvaru `setzone X`. Parametr `X` je textový řetězec (kód) popisující danou časovou zónu. [Seznam časových zón a jejich kódů je zde](https://github.com/nayarsystems/posix_tz_db/blob/master/zones.csv). Například pro nastavení české časové zóny včetně časových posuvů použijeme příkaz `setzone CET-1CEST,M3.5.0,M10.5.0/3`. Změna času po úspěšné změně časové zóny se za dostupného internetu projeví okamžitě. Pozor, v případě zadání nesprávného kódu časové zóny bude automatická sychronizace času vypnuta (neprobíhá kontrola validnosti zadaného kódu).
* Nastavení barvy displeje: Do pole *Command entry* zadáme příkaz je ve tvaru `rgb R G B`. Parametry `R`, `G` a `B` odpovídají jednotlivým hodnotám RGB kódu zvolené barvy v rozsahu 0-255. Například pro nastavení zelené barvy použijeme příkaz `rgb 0 255 0`. Příkaz odešleme stiskem tlačítka *Enter*.

<!-- _________________________________________________________________ -->
# <a name = novyprojekt>Nový projekt</a>

Vytvoříme nový projekt a nahrajeme program do Time-O-Mat.

## Postup
Vytvořte si na disku svého PC složku pro vaše budoucí programy, například *C:/Time-O-Mat-moje-programy*.

Do této nové složky překopírujte složku *demo_project* ze stáhnutého repozitáře *Time-O-Mat-main*. Tato složka bude sloužit jako šablona tvých budoucích programů pro Time-O-Mat. 

Překopírovanou složku *demo_project* přejmenuj novým názvem, například na *01_prvni_program*.

Ve VS Code otevřete složku *01_prvni_program* pomocí *File*->*Open folder*.

Ve VS Code otevřete soubor *main.cpp* a nahraď jeho obsah následujícím kódem šablony:
```
#include "ToMat/ToMat.h"

void setup() {
    ToMat.begin();
}

void loop() {
    
}
```
Jednotlivé řádky šablony mají následující význam:
* `#include "ToMat/ToMat.h"` - Příkaz *#include* přidává do našeho programu kód z jiných míst. Nyní nám stačí přidání knihovny *ToMat.h* ze složky ToMat.
* `void setup() {}` - Toto je definice funkce. Funkce jsou kusy kódu, které můžeš opakovaně spustit tak, že zavoláš jejich jméno. Kód (tělo) funkce je ohraničen složenými závorkami { a }, a mezi nimi odsazen. Tato funkce se jmenuje *setup* a je spuštěna jedenkrát po zapnutí Time-O-Mat. O to se postará arduino-esp32 framework.
* `ToMat.begin();` - Toto je volání funkce z knihovny *Time-O-Mat*, která knihovnu inicializuje a připraví všechny její komponenty pro budoucí použití. Toto je třeba provést pouze jednou po startu výrobku, proto je příkaz umístěn ve funkci *setup*.
* `void loop()` - Toto je definice funkce *loop*. Ta je spouštěna stále dokola dokud je Time-O-Mat zapnutý.

Připojte Time-O-Mat pomocí USB-C kabelu k PC.

V dolní liště PlatformIO stiskněte šipku (*Upload*) a tím nahrajte program do Time-O-Mat.


Počkejte až se dokončí nahrávání a zobrazí v dolním terminálu *SUCCESS*. Nyní je nový program nahrán.


<!-- _________________________________________________________________ -->
# <a name = prvniprogram>První program</a>

Nyní napíšete svůj první vlastní program pro Time-O-Mat. Do šablony kódu na konec funkce *setup* připiště příkaz `ToMat.display.setLED(0, 0, white);`, tedy nad uzavírací závorku }. Tento příkaz vydá požadavek, aby se na digitu číslo 0 rozsvítila LED číslo 0 bílou barvou.

Všimněte si, že při psaní vám VS Code napovídá. Stačí napsat `ToMat.` a uvidíte nabídku připravených funkcí z knihovny *Time-O-Mat*. Pokud se tak nestane, nabídku vyvoláte stisknutím *Ctrl + Space*.
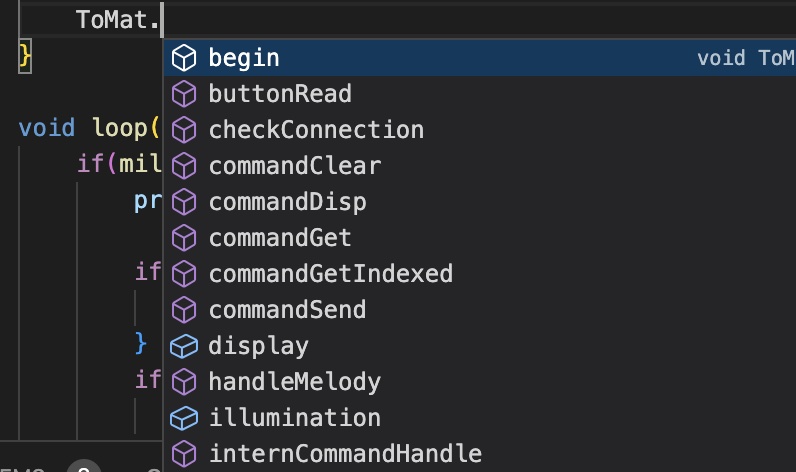
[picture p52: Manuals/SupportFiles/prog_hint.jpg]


Nahrajte program do Time-O-Mat a počkejte, až se LED rozsvítí. Gratulujeme, toto byl váš první vlastní program pro Time-O-Mat :-)

## Výsledný kód

```
#include "ToMat/ToMat.h"

void setup() {
    ToMat.begin();
    ToMat.display.setLED(0, 0, white);
}

void loop() {}
```

<!-- _________________________________________________________________ -->
# <a name = komentare>Komentáře</a>

Do svého kódu je někdy vhodné psát komentáře. Komentáře jsou kusy textu, které jsou viditelné pro programátora, čili vás, ale TracJet si jich nevšímá (ani se do něj nenahrají). Jsou vhodné zejména v místech, kdy ze samotného funkčního kódu není zřejmé, co dělá a k čemu slouží.

V jazyce C++ máme 2 typy komentářů:
1. Jenořádkový komentář je uvozen dvojitým lomítkem `//`. Celý zbytek řádku za dvojitým lomítkem je považován za komentář.
1. Víceřádkový komentář je uvozen lomítkem a hvězdičkou `/*`. Ukončen je hvězdičkou a lomítkem `*/`. Veškerý text mezi je považován za komentář. Začátek a konec mohou být na různých řádcích.

Příklad: Tento program nerozsvítí LEDku.
```
#include "ToMat/ToMat.h"

void setup() {
    ToMat.begin();
    ToMat.display.setLED(0, 0, white); // Toto je komentář
    //ToMat.display.setLED(0, 0, black); tento řádek se neprovede

    /* Toto je 
    víceřádkový komentář. */
}

void loop() {}
```

<!-- _________________________________________________________________ -->
# <a name = promenne>Proměnné</a>

## Motivace
Při psaní programů brzy dojdete k tomu, že potřebujete, aby si program něco *zapamatoval*. Může se jednat o výsledek matematicé operace, počítadlo kroků, uchování měřené hodnoty a tak dále. K tomuto účelu se v programech používají **proměnné**. Proměnné si můžeme představovat jako šuplíky s textovými popisky na sobě. Do šuplíku můžeme *vložit* nějakou informaci a někdy později ji opět vytáhnout. Popisek šuplíku zde představuje název proměnné.

## Vytvoření proměnné
Proměnnou vytvoříme následujícím příkazem:
```
typ_promenne nazev_promenne = hodnota;
```
`typ_promenne` udává jaký typ informace budeme do proměnné ukládat. Říkáme mu také *datový typ proměnné*. Může to být číslo, text atd.

`nazev_promenne` udává název proměnné, pomocí kterého dokážeme od sebe jednotlivé proměnné odlišit. Proto musí mít každá proměnná svůj jedinečný název. Snaž se pojménovávat proměnné výstižně, tedy např. *rychlost* je mnohem lepší než *prom*. V názvu proměnné můžeš používat znaky anglické abecedy, tj. bez diakritiky, velká a malá písmena, čísla a speciální znaky jako podrtžítko `_`. Podtžítkem můžeme oddělovat slova v názvu jedné proměnné.

`=` je operátor sloužící k přiřazení (vložení) určité hodnoty do proměnné.

`;` čili středník slouží k oddělování příkazů a píšeme ho vždy na konec příkazu. Na české klávesnici se nachází pod klávesou *ESC* vlevo nahoře.

## Základní datové typy proměnných
* `int` označuje proměnnou pro ukládání celých čísel, například `3`.
* `float` označuje proměnnou pro ukládání desetinných čísel, například `3.14`.
* `char` označuje jeden textový znak -> znak se udává v apostrofech, například `'c'` označuje znak *c*.
* `bool` označuje pravdivostní hodnotu -> *true* pro pravdu a *false* pro nepravdu.
* `String` označuje řetězec textových znaků -> řetězec se ohraničuje uvozovkami, například `"Ahoj svete"`.

## Operace s proměnnými

Operace *přiřazení* slouží k uložení dané hodnoty do proměnné. Hodnota, která je napravo od rovnítka `=` je uložena do proměnné uvedené nalevo od `=`: 
```
nazev_promenne = hodnota;
```

Číselné proměnné můžeme sčítat (+), odečítat (-), násobit (*) a dělit (/). 

Příklad:
```
#include "ToMat/ToMat.h"

void setup() {
    ToMat.begin();
    int cele_cislo = 0;
    cele_cislo = cele_cislo + 10;   // Zvýšíme hodnotu v proměnné o 10
    cele_cislo += 10;   // Zkrácený zápis stejné operace jako výše
    // Nyní je v proměnné cele_cislo uložena hodnota 20
}

void loop() {}
```

Zde jsou uvedeny příklady vytvoření proměnných zmíněných datových typů a uložení hodnoty do nich.
```
// proměnná pro celá čísla se jménem cele_cislo, ve které je hodnota 0
int cele_cislo = 0; 

// promenna pro desetinne cislo ve které je hodnota 3.14
float desetinne_cislo = 3.14; 

// proměnná znak, do které jsme uložili znak 'a'
char znak = 'a';

// proměnná otevreno, do které jsme uložili hodnotu pravda (true)
bool otevreno = true; 

// proměnná pro textový řetězec s hodnotou "nejaky text"
String text = "nejaky text";
```

<!-- _________________________________________________________________ -->
# <a name = podminky>Podmínky</a>

## Motivace
Při programování brzo zjistíte, že potřebujete, aby se váš program choval různě v různých situacích. Jinými slovy aby prováděl určité úseky kódu pouze za splnění daných podmínek. K tomu se používají *podmínky*. Ty umožňují programu provádět *rozhodnutí*.

## Konstrukce `if`
`if` je základní podmínka. Základem této konstrukce je *podmínka*, která se uvádí za `if` do kulatých závorek. Podmínka může být proměnná nebo logický výraz.
```
if(podminka) {
    ...kód který se provede, pokud je podmínka splněna (true)...
}
```

U `if` konstrukce docházi k vyhodnocení podmínky, tj. zjistí se, zda je podmínka pravdivá (`true`) nebo nepravdivá (`false(`). Pokud je pravdivá, provede se kód, který je za `if` uveden ve složených závorkách `{...kód...}`. V opačném případě program pokračuje až za `if`.

## Konstrukce `else`
Může existovat jen v případě, že před ní byl uvedený `if`. Úkolem `else` je provést kód v něm napsaný jen v případě, že předchozí `if` nebyl splněn.
```
if(podminka) {
    ...kód který se provede, pokud je podmínka splněna (true)...
}
else {
    ...kód který se provede, pokud není podmínka splněna (false)...
}
```

## Konstrukce `else if`
Pokud chceme postihnout více možných příapadů než dva dříve zmíněné (`true` a `false`), použijeme konstrukci `else if`.
```
if(podminka_1) {
    ...kód který se provede, pokud je podmínka 1 splněna (true)...
}
else if(podminka_2) {
    ...kód který se provede, pokud je podmínka 2 splněna (true)...
}
else {
    ...kód který se provede, pokud není podmínka 1 ani 2 splněna (false)...
}
```

Poznámka: Do jednotlivých konstrukcí větvení je možné libovolně vnořovat další konstrukce větvení.

## Podmínka
Podmínka dotazovaná při větvení určuje zda se bude daný úsek kódu provádět. K tomu je porovnávána s logickými hodnotami `true` a `false`. Tato hodnota může být uložena v pravdivostní proměnné typu `bool`:
```
bool podminka = true;
if(podminka) {
    ...kód je vykonán, protože podmínka je pravdivá...
}
```

K vytvoření podmínky z číselné hodnoty budeme používat tzv. *relační operátory*:
* `==` označuje porovnávání, takže 1 == 1 označuje, že se 1 rovná 1
* `!=` vykřičník před rovnítkem označuje opak, tudíž tento operátor značí nerovnost, tedy 1 != 2 označuje, že se 1 nerovná 2
* `<` menší než
* `>` větší než
* `<=` menší nebo rovno než
* `>=` větší nebo rovno než
Výsledek výrazu s relačními operátory nabývá hodnotu pravda `true` nebo nepravda `false`.
Příklad relačního operátoru:
```
int cele_cislo = 3;
if(cele_cislo < 5) {
    if (cele_cislo > -5) {
        cele_cislo = 0;
    }
}
// V proměnné cele_cislo je uložena hodnota 0, protože obě podmínky byly splněny
```

## Propojování podmínek
Podmínky je možné propojovat do jedné složitější pomocí logických operátorů. Jsou jimi
* `&&` (logické *A*) říká nám, že musí platit obě podmínky, aby byla podmínka splněna, jinak je nesplněna
* `||` (logické *NEBO*) říká nám, že musí platit alespoň jedna podmínka z nich, aby byla podmínka splněna, jinak je nesplněna
Ukázka: Následující program funguje stejně jako předchozí, používá ovšem využívá logické operátory.
```
int cele_cislo = 3;
if(cele_cislo < 5 && cele_cislo > -5) {
    cele_cislo = 0;
}
// V proměnné cele_cislo je uložena hodnota 0, protože obě podmínky byly splněny
```

<!-- _________________________________________________________________ -->
# <a name = cyklus>Cyklus</a>

## Motivace
Při programování se nám často stane, že potřebujeme některé úkony vykonat vícekrát. Případně vykonat velké množství podobných úkonů. K tomuto budeme používat *cykly*, které nám umožní opakovaně vykonávat úseky kódu.

Pro jedno bliknutí LEDkou poslouží tento program:
```
#include "ToMat/ToMat.h"

void setup() {
    ToMat.begin();

    ToMat.display.setLED(0, 0, white);

    delay(500);

    ToMat.display.setLED(0, 0, black);
}

void loop() {}
```

V tomto programu používáme příkaz *delay()* pro čekání na místu v kódu o určitý čas. Tento čas čekání je určen v milisekundách (1000 ms = 1s).

Pro 2 bliknutí LEDkou poslouží tento program, ve kterém jsme pouze zopakovali příkazy z minulého:
```
#include "ToMat/ToMat.h"

void setup() {
    ToMat.begin();

    ToMat.display.setLED(0, 0, white);
    delay(500);
    ToMat.display.setLED(0, 0, black);
    delay(500);
    ToMat.display.setLED(0, 0, white);
    delay(500);
    ToMat.display.setLED(0, 0, black);;
}

void loop() {}
```

Ale co kdybychom chtěli bliknout 1000 krát? Kód by nás přerostl. Cykly nám pomohou tento problém vyřešit. 

## Cyklus `while`
Cyklus `while` použijeme v případě, kdy předem nevíme, kolikrát chceme kód opakovat. Cyklus `while` se opakuje dokud je splněna jeho podmínka (`true`).
```
while(podminka){
    ...Co se ma provest pri kazdem opakovani...
}
```

V následném úseku kódu budeme blikat LEDkou dokud bude Time-O-Mat zapnutý:
```
while(true){
    ToMat.display.setLED(0, 0, white);
    delay(500);
    ToMat.display.setLED(0, 0, black);
}
```

## Cyklus `for`
Cyklus `for` použijeme v případě, kdy dopředu známe, kolikrát chceme kód opakovat. Cyklus `for` má následující formu:
```
for(vytvoreni_promenne; podminka; operace){
    ...Co se ma provest pri kazdem opakovani...
}
```

Oproti cyklu while je zde podmínková část složitější. Skládá se ze 3 částí:
* Vytvoř proměnnou, kterou využiješ v podmínce
* Zadej podmínku, která bude udávat, do kdy máme kód opakovat
* Uprav hodnotu proměnné, pokud je podmínka splněna

Následující program ukazuje, jak bliknout 10x s LED číslo 1 pomocí cyklus `for`.
```
for(int pocet_bliku = 0; pocet_bliku < 10; pocet_bliku++){
    ToMat.display.setLED(0, 0, white);
    delay(500);
    ToMat.display.setLED(0, 0, black);
}
```
Vytvořili jsme proměnnou `pocet_bliku`, která obsahuje celé číslo 0. Dokud je hodnota této proměnné menší než 10, zvýší se její hodnota 1 a provede se kód uvnitř cyklu. Jakmile hodnota proměnné rovna 10, cyklus se ukončí a program pokračuje směrem dolů.

<!-- _________________________________________________________________ -->
# <a name = ledky>LEDky</a>
V této kapitole si podrobněji ukážeme ovládání LEDek na Time-O-Mat.

Jednotlivé LEDky budeme ovládat pomocí příkazu `ToMat.display.setLED(int segmentID, int ledID, ColorRGB color)`. Jedná se o volání funkce s parametry v kulatých závorkách:
* `segmentID` udává, který digit chceme ovládat.
* `ledID` udává, kterou LED daného digitu chceme ovládat.
* `color` udává, jakou barvou má daná LED svítit. Můžeme použít předdefinované barvy *red, green, blue, cyan, magenta, yellow, black, white*, nebo si definovat vlastní.

Parametr `segmentID` nabývá následujících hodnot:
* `0` pro první digit zleva.
* `1` pro druhý digit zleva.
* `2` pro dvojtečku uprostřed.
* `3` pro třetí digit zleva.
* `4` pro čtvrtý digit zleva.
* `5` pro zadní LED pásek.

Parametr `ledID` čísluje LEDky v jednotlivých digitech v následujícím pořadí:
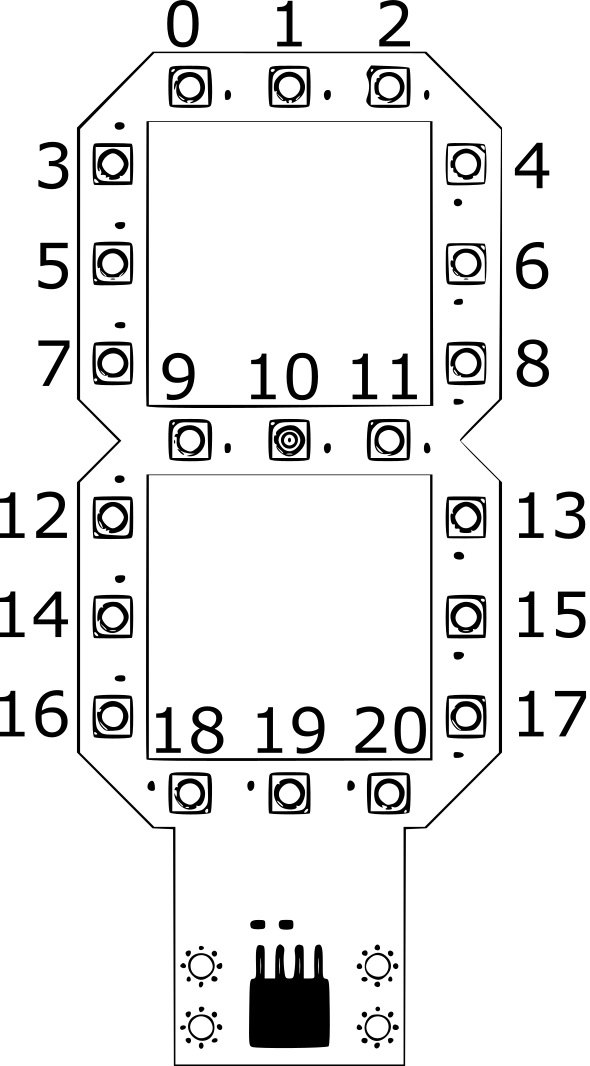
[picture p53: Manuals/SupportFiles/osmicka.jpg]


Parametr  `ledID` čísluje LEDky na dvojtečce od 0 (nahoře) po 1 (dole).

Parametr `ledID` čísluje LEDky na zadním LED pásku od 0 (vlevo) po 8 (vpravo) při pohledu na hodiny ze zadu.

Pro definování vlastní barvy použijeme kontrukci podobnou vytváření proměnných. Existují 2 formáty, pomocí kterých můžeme definovat vlastní barvu:
* RGB (red-červená, green-zelená, blue-modrá) příkazem `ColorRGB cervena = {255, 0, 0};`
* HSV (hue-chromatičnost, saturation-saturace, value-jas) příkazem `ColorHSV cervena = {0, 1, 1};`

Oba formáty dokážou definovat jakoukoli barvu, kterou umí barevné LEDky vysvítit, ale každý má své výhody a nevýhody. RGB popisuje barvy podobně jako stroje, tj. jak intenzivně má svítit která barevná složka každé z LEDek. HSV naopak popisuje barvy podobně, jako lidé a je v mnoha případech pohodlnější k použití, např. pro změnu barvy při zachování jasu.

Pomocí komentářů si v následujícím kódu vyberte jednu z definic barvy `cervena` a ověřte, že výsledkem je stejná červená barva.
```
#include "ToMat/ToMat.h"

void setup() {
    ToMat.begin();

    ColorRGB cervena = {255, 0, 0};
    ColorHSV cervena = {0, 1, 1};
    ToMat.display.setLED(0, 0, cervena);
}

void loop() {}
```

<!-- _________________________________________________________________ -->
# <a name = tlacitka>Tlačítka</a>
Nejjednodušším způsobem, jak můžete Time-O-Mat ovládat je pomocí tlačítek, která najdete na levé straně krabičky. Pro zjištění jestli je tlačítko zmáčknuto, budeme používat příkaz `ToMat.buttonRead(int buttonID)`. Parametrem `buttonID` určujeme, na které tlačítko se ptáme. Tlačítka jsou číslována od 0 (blíže USB) po 2 (dále od USB).

Příklad: Tento program rozsvítí LED při stisku tlačítka 0.
```
#include "ToMat/ToMat.h"

void setup() {
    ToMat.begin();
}

void loop() {
    if(ToMat.buttonRead(0)) {
        ToMat.display.setLED(0, 0, white);
    }
    else {
        ToMat.display.setLED(0, 0, black);
    }
    delay(20);
}
```

<!-- _________________________________________________________________ -->
# <a name = piezo>Piezoakustický měnič</a>
## Základy
Time-O-Mat obsahuje tzv. piezoakustický měnič, pomocí kterého dokáže vydávat zvuk.

* Stálý tón zapneme pomocí `ToMat.piezo.tone(uint16_t freq);`, kde `freq` je freqence v Hz.
* Veškerý zvuk vypneme pomocí `ToMat.piezo.stop();`.

Následující příklad přerušovaně "pípá" na frekvenci 1kHz.
```
#include "ToMat/ToMat.h"

void setup() {
    ToMat.begin();
}

void loop() {
    ToMat.piezo.tone(1000);
    delay(500);
    ToMat.piezo.stop();
    delay(500);
}
```

## Melodie
Time-O-Mat zvládá i jednoduché melodie. Jen pamatujte na to, že nedokáže hrát více tónů zároveň.
Pro spuštění melodie budeme používat `ToMat.piezo.playMelody(melodie);`.

### Melodie z Arduino songs
Asi nejjednoduším způsobem, jak přehrát melodii, je stáhnout ji z https://github.com/robsoncouto/arduino-songs.
Tam si najděte melodii, otevřte ji a zkopírujte `int melody[] = { ...` a `int tempo = ...`.
Melodii poté přehrajete pomocí `ToMat.piezo.playMelody(melody, sizeof(melody)/sizeof(melody[0]), tempo);`

Následující příklad zahraje melodi Nokie.

```
#include "ToMat/ToMat.h"

// Zkopírováno z Arduino songs
int nokieTempo = 180;
int nokieMelody[] = {

  // Nokia Ringtone 
  // Score available at https://musescore.com/user/29944637/scores/5266155
  
  NOTE_E5, 8, NOTE_D5, 8, NOTE_FS4, 4, NOTE_GS4, 4, 
  NOTE_CS5, 8, NOTE_B4, 8, NOTE_D4, 4, NOTE_E4, 4, 
  NOTE_B4, 8, NOTE_A4, 8, NOTE_CS4, 4, NOTE_E4, 4,
  NOTE_A4, 2, 
};

void setup() {
    ToMat.begin();
    ToMat.piezo.playMelody(nokieMelody, sizeof(nokieMelody)/sizeof(nokieMelody[0]), nokieTempo);
}

void loop() {
}
```

### Vlastní melodie
Psaní vlastních melodií je trochu složitější, ale zvládnutelné.

Vlastní melodii budeme zapisovat pomocí klasického notového zápisu, který v našem provedení vypadá následovně (celou melodii musíme psát do uvozovek): 
`Melody nazevMelodie("F5#/8 F5#/8 D5/8 B4/8 R/8*");`

Každá nota se skládá ze dvou částí.
* Před lomítkem se udává výška noty. `#` zvedá notu o 1/2 noty. `R` znamená pauza.
* Za lomítkem se udává délka noty. `*` prodlužuje notu o půlku.
    * `1` -> celá nota
    * `8` -> 1/8 celé noty
    * `2*` -> 1/2 + 1/4 -> 3/4 celé noty

#### Tempo
Vlastní melodii musíme nastavit i tempo. To se udává v BPM (beats per minute), nebo-li počet čtvrtnot za minutu.
Tempo lze nastavit dvěma způsoby.

Při definici melodie: 
```
Melody nazevMelodie("TEMPO=180 F5#/8 F5#/8 D5/8 B4/8 R/8*");
```

Nebo později:
```
Melody nazevMelodie("F5#/8 F5#/8 D5/8 B4/8 R/8*");
nazevMelodie.tempo = 180;
```
Ale pozor! `nazevMelodie.tempo = 180;` lze volat pouze uvnitř funkce (`void setup()`, `void loop()`, ... ). Proto doporučuji spíše první způsob.

#### Přehrání
Vlastní melodii přehrajeme pomocí `ToMat.piezo.playMelody(nazevMelodie);`.

Příklad:
```
#include "ToMat/ToMat.h"

Melody melodyTest("TEMPO=180 c3/4 d3/4 e3/4 f3/4 g3/4 g3/4 a3/4 h3/4 c4/2* c4#/1*");

void setup() {
    ToMat.begin();
	ToMat.piezo.playMelody(melodyTest);
}

void loop() {
}
```

## Další funkce ToMat.piezo
`ToMat.piezo.getState();` vrací aktuální stav.
* `0` -> nic nehraje
* `1` -> stálý tón
* `2` -> hraje melodie

<!-- _________________________________________________________________ -->
# <a name = fotorezistory>Fotorezistory</a>

Pro snímání úrovně osvětlení v okolí Time-O-Mat slouží fotorezistory. Hodiny jsou osazeny dvěma fotorezistory:
* Fotorezistor ID 0 je umístěn na horní straně krabice.
* Fotorezistor ID 1 je umístěn na zadní straně krabice.

Pro zjištění úrovně osvitu jednotlivých fotorezistorů použijeme příkaz `ToMat.illumination.getRaw(int photoresID);`, kde `photoresID` udává index fotorezistoru. Vrácena je nám celočíselná hodnota v rozsahu 0 (tma) až 4095 (světlo).

Následující příklad zjistí hodnotu osvitu fotorezistoru 0 a nastaví podle něj jas LEDky.
```
#include "ToMat/ToMat.h"

void setup() {
    ToMat.begin();
}

void loop() {
    int osvit = ToMat.illumination.getRaw(0);
    ColorRGB barva = {osvit/16, 0, 0};
    ToMat.display.setLED(0, 0, barva);
    delay(20);
}
```

<!-- _________________________________________________________________ -->
# <a name = lista>Dotyková lišta</a>

Pro detekci doteku prstu na horní dotykové liště použijeme příkaz `ToMat.touchBar.getPressed(int buttonID);`, kde `buttonID` udvává index dotykového tlačítka. Tlačítka jsou číslována od 0 (vlevo) po 7 (vpravo). Vrácena je binární hodnota 0 (nezmáčknuto) nebo 1 (zmáčknuto).

Následující příklad rozsvítí LED při zmáčknutí levého dotykového tlačítka (0).
```
#include "ToMat/ToMat.h"

void setup() {
    ToMat.begin();
}

void loop() {
    if(ToMat.touchBar.getPressed(0)) {
        ToMat.display.setLED(0, 0, white);
    }
    else {
        ToMat.display.setLED(0, 0, black);
    }
    delay(20);
}
```

<!-- _________________________________________________________________ -->
# <a name = teplomer>Teploměr</a>

Pro zjištění teploty v okolí Time-O-Mat pomocí senzoru DS18B20 použijeme příkaz `ToMat.getTemperature();`. Vráceno je desetinné číslo reprezentující teplotu ve stupních Celsia.

Následující příklad zjistí teplotu, uloží je do proměnné `teplota` a rozsvítí červenou LED pokud je vyšší než 25.
```
#include "ToMat/ToMat.h"

void setup() {
    ToMat.begin();
}

void loop() {
    int teplota = ToMat.getTemperature();
    if(teplota > 25.0) {
        ToMat.display.setLED(0, 0, red);
    }
    else {
        ToMat.display.setLED(0, 0, black);
    }
    delay(200);
}
```

<!-- _________________________________________________________________ -->
# <a name = seriovka>Sériová linka</a>

## Motivace
Při programování výrobků se často stane, že potřebujete s programem ve výrobku komunikovat. Například když se snažíte odhalit chybu, vypisovat hodnotu senzorů nebo informovat uživatele o ději v programu. Pro tento účel nám poslouží sériová linka.

## Program pro výpis textu na sériové lince
Pro výpis textu na sériové lince budeme používat příkaz `printf`. Abyste na sériové lince jedenkrát vypsali text *Hello World!*, použijte následující program:
```
#include "ToMat/ToMat.h"

void setup() {
    ToMat.begin();
}

void loop() {
    printf("Hello World!\n");
    delay(1000);
}
```

Okolo textu, který chceme vypsat, je třeba vložit dvojité uvozovky `"text"`. Řetězec `\n` označuje znak pro odřádkování, čili obdoba tlačítka *ENTER* v textových editorech. 

## Spuštění sériové linky
1. Po nahrání programu do Time-O-Mat necháme Time-O-Mat zapnutý a připojený USB kabelem k PC.
1. Pomocí tlačítka v levé dolní liště PlatformIO ve tvaru zásuvky spustíme sériovou linku.

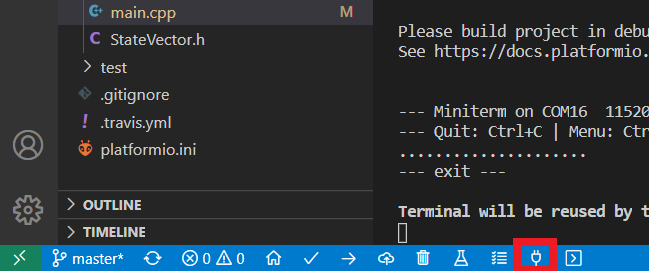
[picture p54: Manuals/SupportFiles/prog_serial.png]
    
1. V monitoru sériové linky v dolní částí okna VS Code najdete příchozí zprávy z Time-O-Mat. Uvidíte, že každou vteřinu přijde nová zpráva ve tvaru *Hello World!*, vždy na novém řádku:
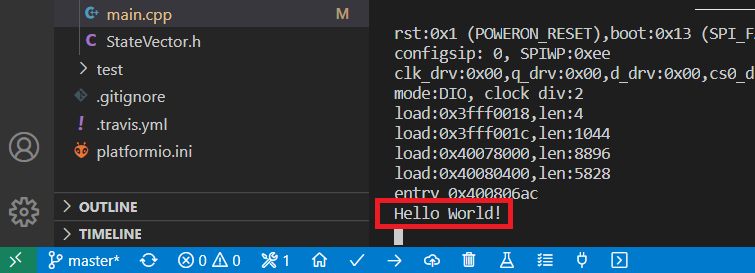
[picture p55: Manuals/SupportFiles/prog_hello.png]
    

## Výpis hodnot proměnných
Často potřebujeme vypsat i hodnotu některé z našich proměnných. V tomto případě můžeme použít takzvaná formátovací direktiva. V textu začínají znakem `%`:
* %d - (decimal) označuje proměnnou pro ukládání celých čísel, například `3`.
* %f - (float) označuje proměnnou pro ukládání desetinných čísel, například `3.14`.
* %c - (char) označuje jeden textový znak, například `'c'` označuje znak *c*.
* %s - (string) označuje řetězec textových znaků -> řetězec se ohraničuje uvozovkami, například `"Ahoj svete"`.

Pro úpravu formátu vypisovaných proměnných máme mnoho dalších možností, které jsou například na [Wiki](https://cs.wikipedia.org/wiki/Printf#Form%C3%A1tovac%C3%AD_%C5%99et%C4%9Bzec). Pro výpis celočíselné proměnné `cele_cislo` do sériové linky použijeme následující příkaz:
```
printf("%d\n", cele_cislo);
```

Příklad: Pro opakovaný výpis času od startu Time-O-Mat použijeme následující program. Hodnota času je uvedena v milisekundách:
```
#include "ToMat/ToMat.h"

void setup() {
    ToMat.begin();
}

void loop() {
    printf("%d\n", millis());
    delay(1000);
}
```

Funkce `millis()` nám vrací počet uplynulých milisekund od startu Time-O-Mat jako celé číslo. 

<!-- _________________________________________________________________ -->
# <a name = displej>Displej a podsvícení</a>
Pro ovládání LEDek na displeji a na zadním podsvícení je možné použít i schopnější funkce než `.setLED()`, která umí ovládat pouze jednu LEDku.

Pro rosvícení celého segmentu ledek jedním příkazem je možné použít konstrukci `ToMat.display.setSegment(int segmentID, ColorRGB color);`. Jedná se o volání funkce s parametry v kulatých závorkách:
* `segmentID` který segment (úsek LEDek) chceme ovládat. Odpovídají rozdělení jako u funkce `.setLED()`.
* `color` udává, jakou barvou má daný segment svítit.

Pro rozsvícení několika vybraných segmentů jedním příkazem použijeme konstrukci `ToMat.display.ssetSegments(SegmentSelector selector, ColorRGB color);`. Jedná se o volání funkce s parametry v kulatých závorkách:
* `selector` který definuje skupinu segmentů, které mají svítit. 
* `color` udává, jakou barvou mají dané segmenty svítit.

Parametr `selector` zde nabývá následujících hodnot:
* `all` - Svítí všechny LED.
* `frontlight` - Svítí všechny LED na předním panelu.
* `backlight` - Svítí všechny LED na zadním LED pásku.
* `digits` - Svítí všechny LED v digitech.
* `colon` - Svítí obě LED ve dvojtečce.

Pro definování vlastní kombinace pro rozsvícení více segmentů jedním příkazem použijeme kontrukci podobnou vytváření proměnných `SegmentSelector vyber = {0, 0, 0, 0, 0, 0};` Ve výčtu hodnota `0` udává, že daný segment nemá být rozsvícen a hodnota `1`, že daný digit má být rozsvícen. Hodnoty jsou ve stejném pořadí segmentů, jako je použito ve funkci `.setLED()`. 

Následující příklad nejdříve vybere 2 krajní digity s dvojtečkou a následně je rozsvítí červenou barvou.
```
#include "ToMat/ToMat.h"

void setup() {
    ToMat.begin();
    SegmentSelector vyber = {1, 0, 1, 0, 1, 0};
    ToMat.display.setSegments(vyber, red);
}

void loop() {}
```

Zobrazit znak na 1 digit z předního displeje je možné pomocí konstrukce `ToMat.display.setChar(int charID, char character, ColorRGB color);`. Jedná se o volání funkce s parametry v kulatých závorkách:
* `charID` udává, který digit chceme ovládat. Jsou číslovány od 0 (vlevo) po 3 (vpravo).
* `character` udává, jaké písmeno se má na digitu zobrazit. Hodnotou může být např. `"A"`.
* `color` udává, jakou barvou má daná LED svítit.

Konstrukce `ToMat.display.setText(String text, ColorRGB color);` slouží k nastavení všech 4 digitů na text definovaný v parametru `text` (typ String). Zobrazí se pouze první 4 písmena z parametru `text` a rozsvítí se barvou z parametru `color`.

Funkce `setChar()` i `setText` v základním volání zajístí, že je písmeno nebo text rozsvícen zvolenou barvou a okolní LED jsou zhasnuty. Toto chování je možné změnit pomocí volitelného parametru `mode` při volání `ToMat.display.setChar(int charID, char character, ColorRGB color, TextMode mode);` a obdobně pro funkci `setText`. Parametr `mode` je možné nastavit na následující hodnoty:
* `TextMode_textColor_otherBlack` - Standardní nastavení: text nastaven na zvolenou barvu, okolmní LED zhasnuty
* `TextMode_textColor_otherOmit` - Text nastaven na zvolenou barvu, okolní LED ponechány v původním stavu
* `TextMode_textBlack_otherColor` - Text zhasnut, okolní LED nastaveny na zvolenou barvu
* `TextMode_textBlack_otherOmit` - Text zhasnut na, okolní LED ponechány v původním stavu
* `TextMode_textOmit_otherColor` - Text ponechán v původním stavu, okolní LED nastaveny na zvolenou barvu
* `TextMode_textOmit_otherBlack` - Text ponechán v původním stavu, okolní LED zhasnuty

Konstrukce `ToMat.display.setBrightness(SegmentSelector selector, float brightness);` nastaví jas všech LEDek na vybraných segmentech. Všechny následující příkazy nastavující barvu LEDek vybraných segmentů budou nastavovat barvu se sníženým jasem. Jedná se o volání funkce s parametry v kulatých závorkách:
* `selector` udává výběr segmentů pro provedení nastavení.
* `brightness` nastavuje hodnotu jasu v rozsahu 0 (nesvítí vůbec) po 1 (svítí naplno).

Konstrukce `setTransition(SegmentSelector selector, TransitionType aTransitionType, float aTransitionRate);` slouží k nastavení přechodových animací, např. pro nastavení plynulých přechodů mezi různými stavy rozsvícení. Jedná se o volání funkce s parametry v kulatých závorkách:
* `selector` udává výběr segmentů pro provedení nastavení.
* `aTransitionType` udává druh přechodové animace. Možnosti jsou `Linear` a `Exponential`, kde 2. varianta je vizuálně přirozenější.
* `aTransitionTime` udává dobu trvání přechodové animace ve vteřinách. Např. `1.0` odpovídá přechodu plného rozsahu z tmy až do plného bílého svitu přechodem trvajícím 1 vteřinu.

Následující příklad nastaví jas předního displeje na `0.5`, plynulý přechod s rychlostí `2.0` a zobrazí červeně slovo `AHOJ` na předním displeji.
```
#include "ToMat/ToMat.h"

void setup() {
    ToMat.begin();
    ToMat.display.setBrightness(front, 0.5);
    ToMat.display.setTransition(front, linear, 2.0);
    ToMat.display.setText("AHOJ", red);
}

void loop() {}
```

Jas LED je shora omezen maximálním elektrickým proudem, který je možné udebírat z USB nabíječky. Proto nemusí být vždy možné dosáhnout plného jasu všech LED. USB-C nabíječky umožňují automatické zjištění maximálního dodávaného proudu, což Time-O-Mat podporuje. V standardním nastavení je zjišťování proudového limitu nabíječky automatické. Režim omezení odebíraného proudu je však možné nastavit i manuálně pomocí funkce `ToMat.power.setMode(PowerMode mode)`, kde parametr `mode` nabývá hodnot:
* `USB2_500mA` - Omezení proudu na 500mA
* `USB3_900mA` - Omezení proudu na 900mA
* `Medium_1500mA` - Omezení proudu na 1500mA
* `High_3000mA` - Omezení proudu na 3000mA
* `Automatic` - Automatické nastavení

Tuto funkci stačí zavolat pouze jednou a to umístěním do funkce `setup()`.

<!-- _________________________________________________________________ -->
# <a name = wifi>WiFi</a>
Pro spuštění WiFi a ovládací webové aplikace slouží funkce `ToMat.startWiFiCaptain("<your_name>")`. Po jejím zavolání bude postaráno o vytvoření WiFi přístupového bodu (AP) v Time-O-Mat a také o připojní k externí WiFi, jakmile má Time-O-Mat správné přihlašovací údaje a je v dosahu. Také je spuštěn server hostující webovou aplikaci pro dálkové ovládání Time-O-Mat.

<!-- _________________________________________________________________ -->
# <a name = prikazy>Vzdálený příkazový řádek</a>
Pro dálkové ovládání Time-O-Mat můžete použít i textové příkazy. Ty budete zadávat do pole *Command entry* na webové stránce dálkového ovládání. Po stisku tlačítka *Enter* (funguje i na klávesnici) je zadaný příkaz odeslán do Time-O-Mat. K použítí přijatého příkazu budeme používat následující funkce:
* `ToMat.commandGet()` - vrací textový řetězec (proměnnou typu *String*) obsahující aktuálně přijatý příkaz.
* `ToMat.commandGetIndexed(index)` - vrací textový řetězec obsahující jedno slovo z přijatého příkazu. Slova jsou oddělena mezerami a číslována od 0.
* `ToMat.commandClear()` - vymaže obsah celého aktuálně přijatého příkazu.

Příklad: Následující program blikne LED po obdržení příkazu "blink":
```
#include "ToMat/ToMat.h"

void setup() {
    ToMat.begin();
    ToMat.startWiFiCaptain("<your_name>");
}

void loop() {
    if(ToMat.commandGet() == "blink") {
        ToMat.display.setLED(0, 0, white);
        delay(500);
        ToMat.display.setLED(0, 0, black);
        ToMat.commandClear();  // nutné jinak bude v paměti pořád příkaz "blink" a LED bude pořád svítit
    }
    delay(100);
}
```

Time-O-Mat umožňuje textovou komunikaci i opačným směrem, tedy z Time-O-Mat do webové stránky dálkového ovládání.
* `ToMat.commandDisp(command)` - odešle textový příkaz *command* z Time-O-Mat a zobrazí ho šedě v poli *Command entry*.

Příklad: Následující program bude v textovém poli *Command entry* vypisovat stav tlačítka 1 na Time-O-Mat:
```
#include "ToMat/ToMat.h"

void setup() {
    ToMat.begin();
    ToMat.startWiFiCaptain("<your_name>");
}

void loop() {
    ToMat.commandDisp(String(Time-O-Mat.buttonRead(1)));
    delay(500);
}
```

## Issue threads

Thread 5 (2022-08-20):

Improved setText/setChar

ErikPech, 2022-08-20:
the setChar and setText functions both turn the unnecessary LED's off and the necessary LED's on, but sometimes it would be better to turn the unnecessary LED's off and do nothing else,  this can be done by just removing the "setLED(segmentID, i, color);" line of code from the setChar function but I believe that @MarPta has the skills to do this better and more organized thus why I created this issue

MarPta, 2023-06-01:
Done.

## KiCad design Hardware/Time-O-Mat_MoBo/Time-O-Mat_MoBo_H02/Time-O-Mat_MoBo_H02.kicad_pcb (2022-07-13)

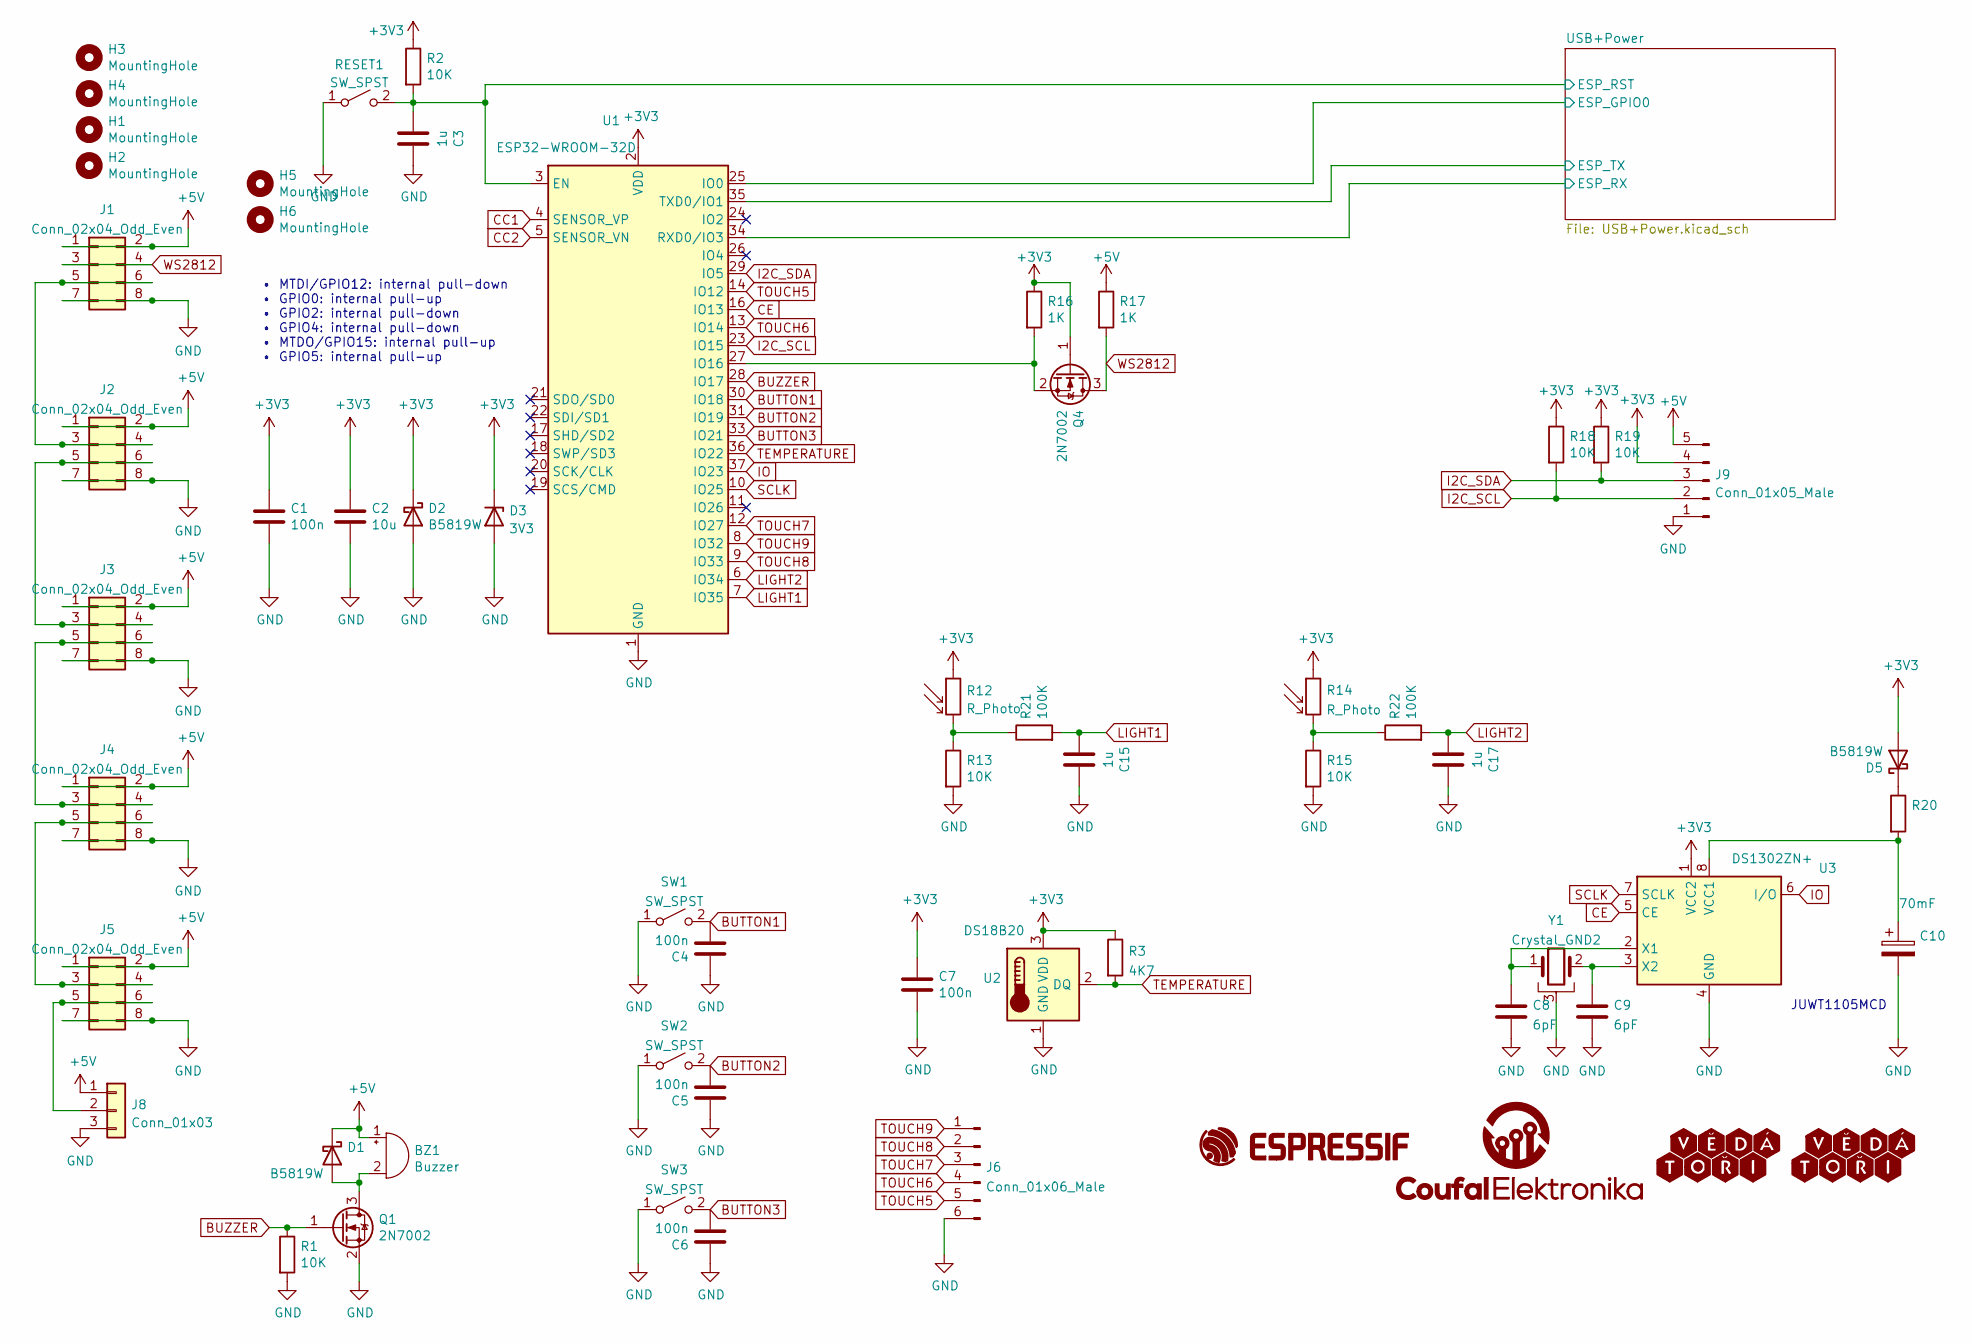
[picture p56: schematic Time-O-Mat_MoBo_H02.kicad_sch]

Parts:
BZ1: Buzzer; Buzzer_12x9.5RM6.6
C1, C4, C5, C6, C7: 100n; C_0603_1608Metric; LCSC C14663
C2: 10u; C_0805_2012Metric; LCSC C15850
C3, C15, C17: 1u; C_0603_1608Metric; LCSC C15849
C8, C9: 6pF; C_0603_1608Metric; LCSC C37474
C10: 70mF; SM3R3703T01U; LCSC C396469
D1, D2, D5: B5819W; D_SOD-123; LCSC C8598
D3: 3V3; D_MiniMELF; LCSC C8056
G1: CoufalElektronika_logo; Coufal_elektronika_text_30x13mm
G2: (no value)
G3: Vedatori_logo; Vedatori_15mm
G5: Espressif_logo; Espressif_logo_30mm
H1, H2, H3, H4, H5, H6: MountingHole; MountingHole_3.2mm_M3
J1, J2, J3, J4, J5: Conn_02x04_Odd_Even; PinHeader_2x04_P2.54mm_Vertical
J6: Conn_01x06_Male; JST_XH_B6B-XH-A_1x06_P2.50mm_Vertical
J8: Conn_01x03; JST_XH_S3B-XH-A-1_1x03_P2.50mm_Horizontal
J9: Conn_01x05_Male; PinHeader_1x05_P2.54mm_Vertical
Q1, Q4: 2N7002; SOT-23; LCSC C8545
R1, R2, R13, R15, R18, R19: 10K; R_0603_1608Metric; LCSC C25804
R3: 4K7; R_0603_1608Metric; LCSC C23162
R12: R_Photo; JST_XH_S2B-XH-A-1_1x02_P2.50mm_Horizontal
R14: R_Photo; R_LDR_5.1x4.3mm_P3.4mm_Vertical
R16, R17: 1K; R_0603_1608Metric; LCSC C21190
R20: LCSC C22859
R21, R22: 100K; R_0603_1608Metric; LCSC C25803
RESET1: SW_SPST; SW_SPST_TL3342; LCSC C318884
SW1, SW2, SW3: SW_SPST; SW_Tactile_SPST_Angled_PTS645Vx83-2LFS
U1: ESP32-WROOM-32D; ESP32-WROOM-32; LCSC C473012
U2: DS18B20; TO-92_HandSolder
U3: DS1302ZN+; SOIC-8_3.9x4.9mm_P1.27mm; LCSC C910859
Y1: Crystal_GND2; Crystal_DS26_D2.0mm_L6.0mm_Horizontal_1EP_style2

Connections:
+3V3: C1.1, C2.1, C7.1, D2.1 (K), D3.1 (K), D5.2 (A), J9.4, Q4.1 (G), R2.1, R3.1, R12.1, R14.1, R16.1, R18.1, R19.1, U1.2 (VDD), U2.3 (VDD), U3.1 (VCC2); also elsewhere on the board
+5V: BZ1.1 (-), D1.1 (K), J1.1, J1.2, J2.1, J2.2, J3.1, J3.2, J4.1, J4.2, J5.1, J5.2, J8.1, J9.5, R17.1; also elsewhere on the board
/USB+Power/ESP_GPIO0: U1.25 (IO0); also elsewhere on the board
/USB+Power/ESP_RST: C3.2, R2.2, RESET1.2 (B), U1.3 (EN); also elsewhere on the board
/USB+Power/ESP_RX: U1.34 (RXD0/IO3); also elsewhere on the board
/USB+Power/ESP_TX: U1.35 (TXD0/IO1); also elsewhere on the board
BUTTON1: C4.2, SW1.2 (B), U1.30 (IO18)
BUTTON2: C5.2, SW2.2 (B), U1.31 (IO19)
BUTTON3: C6.2, SW3.2 (B), U1.33 (IO21)
BUZZER: Q1.1 (G), R1.1, U1.28 (IO17)
CC1: U1.4 (SENSOR_VP); also elsewhere on the board
CC2: U1.5 (SENSOR_VN); also elsewhere on the board
CE: U1.16 (IO13), U3.5 (CE)
GND: C1.2, C2.2, C3.1, C4.1, C5.1, C6.1, C7.2, C8.2, C9.2, C10.2, C15.1, C17.1, D2.2 (A), D3.2 (A), J1.7, J1.8, J2.7, J2.8, J3.7, J3.8, J4.7, J4.8, J5.7, J5.8, J6.6, J8.3, J9.1, Q1.2 (S), R1.2, R13.2, R15.2, RESET1.1 (A), SW1.1 (A), SW2.1 (A), SW3.1 (A), U1.1 (GND), U1.15 (GND), U1.38 (GND), U1.39 (GND), U2.1 (GND), U3.4 (GND), Y1.3; also elsewhere on the board
I2C_SCL: J9.2, R18.2, U1.23 (IO15)
I2C_SDA: J9.3, R19.2, U1.29 (IO5)
IO: U1.37 (IO23), U3.6 (I/O)
LIGHT1: C15.2, R21.2, U1.7 (IO35)
LIGHT2: C17.2, R22.2, U1.6 (IO34)
unnamed: BZ1.2 (+), D1.2 (A), Q1.3 (D)
unnamed: C8.1, U3.2 (X1), Y1.1
unnamed: C9.1, U3.3 (X2), Y1.2
unnamed: C10.1, R20.2, U3.8 (VCC1)
unnamed: D5.1 (K), R20.1
unnamed: J1.5, J1.6, J2.3, J2.4
unnamed: J2.5, J2.6, J3.3, J3.4
unnamed: J3.5, J3.6, J4.3, J4.4
unnamed: J4.5, J4.6, J5.3, J5.4
unnamed: J5.5, J5.6, J8.2
unnamed: Q4.2 (S), R16.2, U1.27 (IO16)
unnamed: R12.2, R13.1, R21.1
unnamed: R14.2, R15.1, R22.1
SCLK: U1.10 (IO25), U3.7 (SCLK)
TEMPERATURE: R3.2, U1.36 (IO22), U2.2 (DQ)
TOUCH5: J6.5, U1.14 (IO12)
TOUCH6: J6.4, U1.13 (IO14)
TOUCH7: J6.3, U1.12 (IO27)
TOUCH8: J6.2, U1.9 (IO33)
TOUCH9: J6.1, U1.8 (IO32)
WS2812: J1.3, J1.4, Q4.3 (D), R17.2

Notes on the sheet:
JUWT1105MCD
• MTDI/GPIO12: internal pull-down • GPIO0: internal pull-up • GPIO2: internal pull-down • GPIO4: internal pull-down • MTDO/GPIO15: internal pull-up • GPIO5: internal pull-up

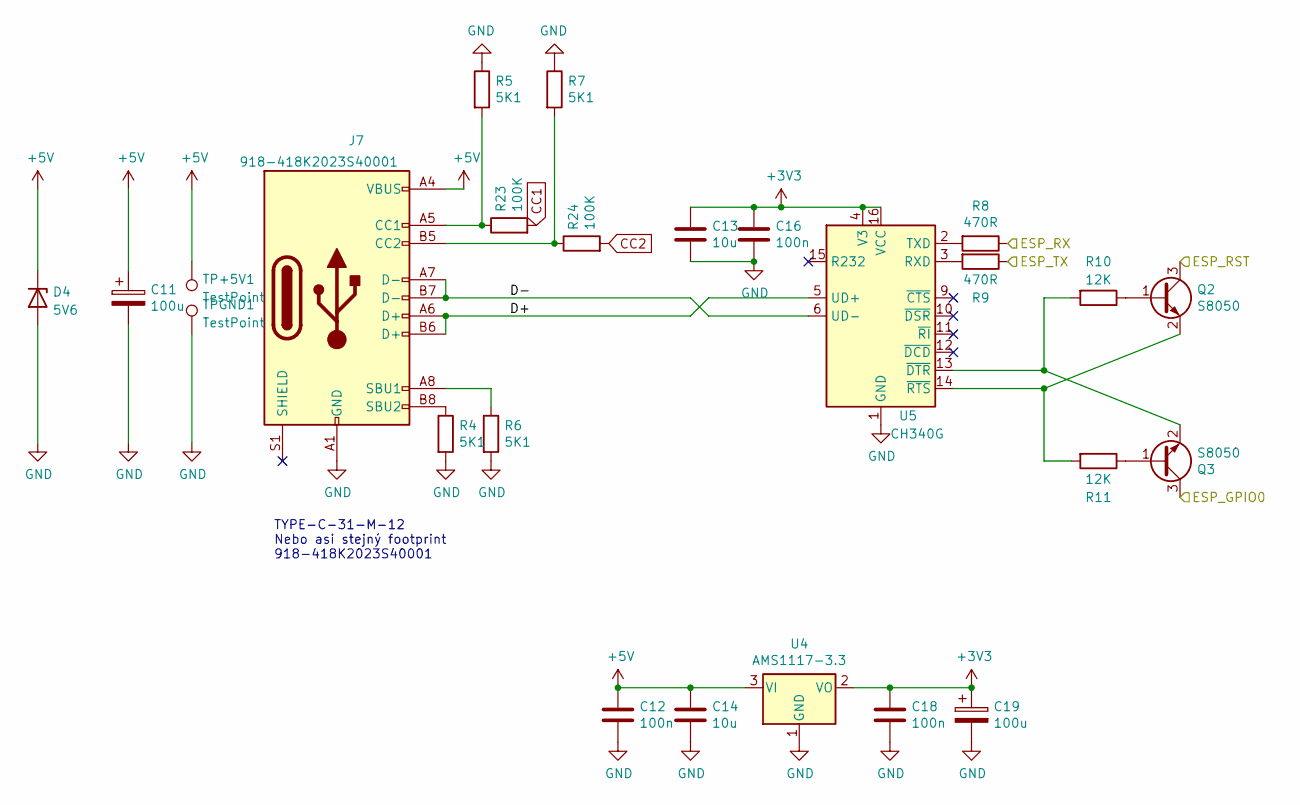
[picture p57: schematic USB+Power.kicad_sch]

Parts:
C11, C19: 100u; CP_Radial_D5.0mm_P2.00mm; LCSC C43803
C12, C16, C18: 100n; C_0603_1608Metric; LCSC C14663
C13: 10u; C_0603_1608Metric; LCSC C19702
C14: 10u; C_0805_2012Metric; LCSC C15850
D4: 5V6; D_MiniMELF; LCSC C8062
J7: 918-418K2023S40001; USB_C_Receptacle_HRO_TYPE-C-31-M-12; LCSC C167321
Q2, Q3: S8050; SOT-23; LCSC C2146
R4, R5, R6, R7: 5K1; R_0603_1608Metric; LCSC C23186
R8, R9: 470R; R_0603_1608Metric; LCSC C23179
R10, R11: 12K; R_0603_1608Metric; LCSC C22790
R23, R24: 100K; R_0603_1608Metric; LCSC C25803
TP+5V1: TestPoint; SolderWirePad_1x01_SMD_1x2mm
TPGND1: TestPoint; SolderWirePad_1x01_SMD_1x2mm
U4: AMS1117-3.3; SOT-223-3_TabPin2; LCSC C6186
U5: CH340G; SOIC-16_3.9x9.9mm_P1.27mm; LCSC C84681

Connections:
+3V3: C13.1, C16.1, C18.1, C19.1, U4.2 (VO), U5.4 (V3), U5.16 (VCC); also elsewhere on the board
+5V: C11.1, C12.1, C14.1, D4.1 (K), J7.A4 (VBUS), J7.A9 (VBUS), J7.B4 (VBUS), J7.B9 (VBUS), TP+5V1.1, U4.3 (VI); also elsewhere on the board
/USB+Power/D+: J7.A6 (D+), J7.B6 (D+), U5.5 (UD+)
/USB+Power/D-: J7.A7 (D-), J7.B7 (D-), U5.6 (UD-)
/USB+Power/ESP_GPIO0: Q3.3 (C); also elsewhere on the board
/USB+Power/ESP_RST: Q2.3 (C); also elsewhere on the board
/USB+Power/ESP_RX: R8.1; also elsewhere on the board
/USB+Power/ESP_TX: R9.1; also elsewhere on the board
CC1: R23.2; also elsewhere on the board
CC2: R24.2; also elsewhere on the board
GND: C11.2, C12.2, C13.2, C14.2, C16.2, C18.2, C19.2, D4.2 (A), J7.A1 (GND), J7.A12 (GND), J7.B1 (GND), J7.B12 (GND), R4.2, R5.1, R6.2, R7.1, TPGND1.1, U4.1 (GND), U5.1 (GND); also elsewhere on the board
unnamed: J7.A5 (CC1), R5.2, R23.1
unnamed: J7.A8 (SBU1), R6.1
unnamed: J7.B5 (CC2), R7.2, R24.1
unnamed: J7.B8 (SBU2), R4.1
unnamed: Q2.1 (B), R10.1
unnamed: Q2.2 (E), R11.2, U5.14 (~RTS)
unnamed: Q3.1 (B), R11.1
unnamed: Q3.2 (E), R10.2, U5.13 (~DTR)
unnamed: R8.2, U5.2 (TXD)
unnamed: R9.2, U5.3 (RXD)

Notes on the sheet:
TYPE-C-31-M-12 Nebo asi stejný footprint 918-418K2023S40001

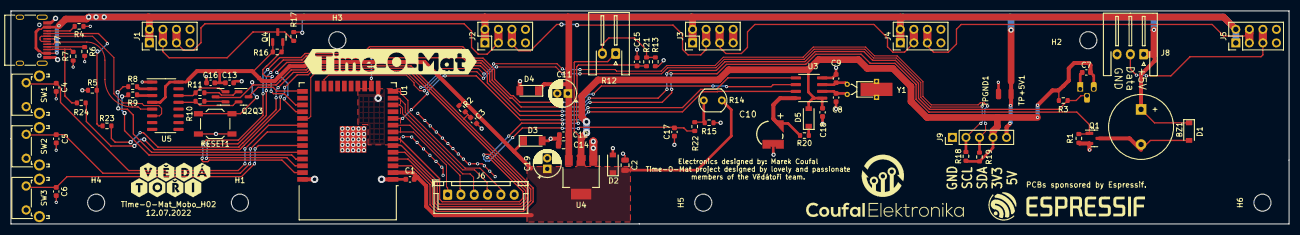
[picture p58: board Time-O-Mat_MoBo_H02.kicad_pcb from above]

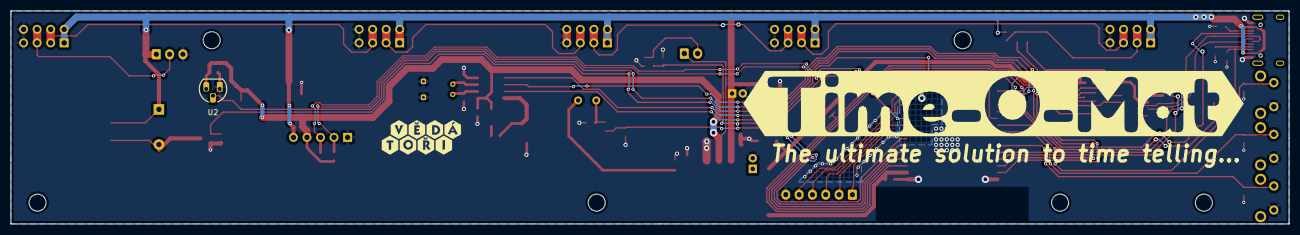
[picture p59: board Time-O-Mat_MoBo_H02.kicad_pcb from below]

Board: 2 copper layers, 240.0 x 40.0 mm, 86 parts (3 on the bottom side), 52 nets.

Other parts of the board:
kibuzzard-61E88A0E: G***; kibuzzard-61E88A0E
kibuzzard-61E8891A: G***; kibuzzard-61E8891A

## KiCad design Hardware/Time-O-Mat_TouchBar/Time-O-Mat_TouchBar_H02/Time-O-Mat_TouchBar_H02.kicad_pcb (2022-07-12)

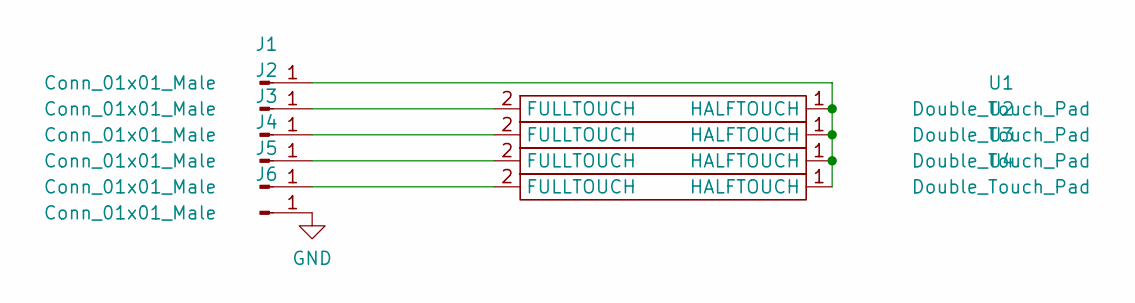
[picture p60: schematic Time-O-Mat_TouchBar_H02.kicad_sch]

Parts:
J1, J2, J3, J4, J5, J6: Conn_01x01_Male
U1, U2, U3, U4: Double_Touch_Pad; Double_Touchpad

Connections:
GND: J6.1
unnamed: J1.1, U1.1 (HALFTOUCH), U2.1 (HALFTOUCH), U3.1 (HALFTOUCH), U4.1 (HALFTOUCH)
unnamed: J2.1, U1.2 (FULLTOUCH)
unnamed: J3.1, U2.2 (FULLTOUCH)
unnamed: J4.1, U3.2 (FULLTOUCH)
unnamed: J5.1, U4.2 (FULLTOUCH)

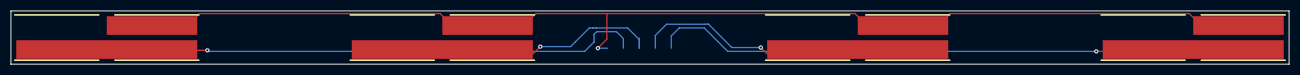
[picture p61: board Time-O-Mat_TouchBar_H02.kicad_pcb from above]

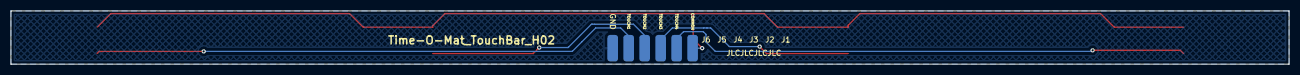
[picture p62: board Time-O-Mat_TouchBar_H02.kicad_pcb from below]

Board: 2 copper layers, 240.0 x 10.0 mm, 10 parts (6 on the bottom side), 5 nets.

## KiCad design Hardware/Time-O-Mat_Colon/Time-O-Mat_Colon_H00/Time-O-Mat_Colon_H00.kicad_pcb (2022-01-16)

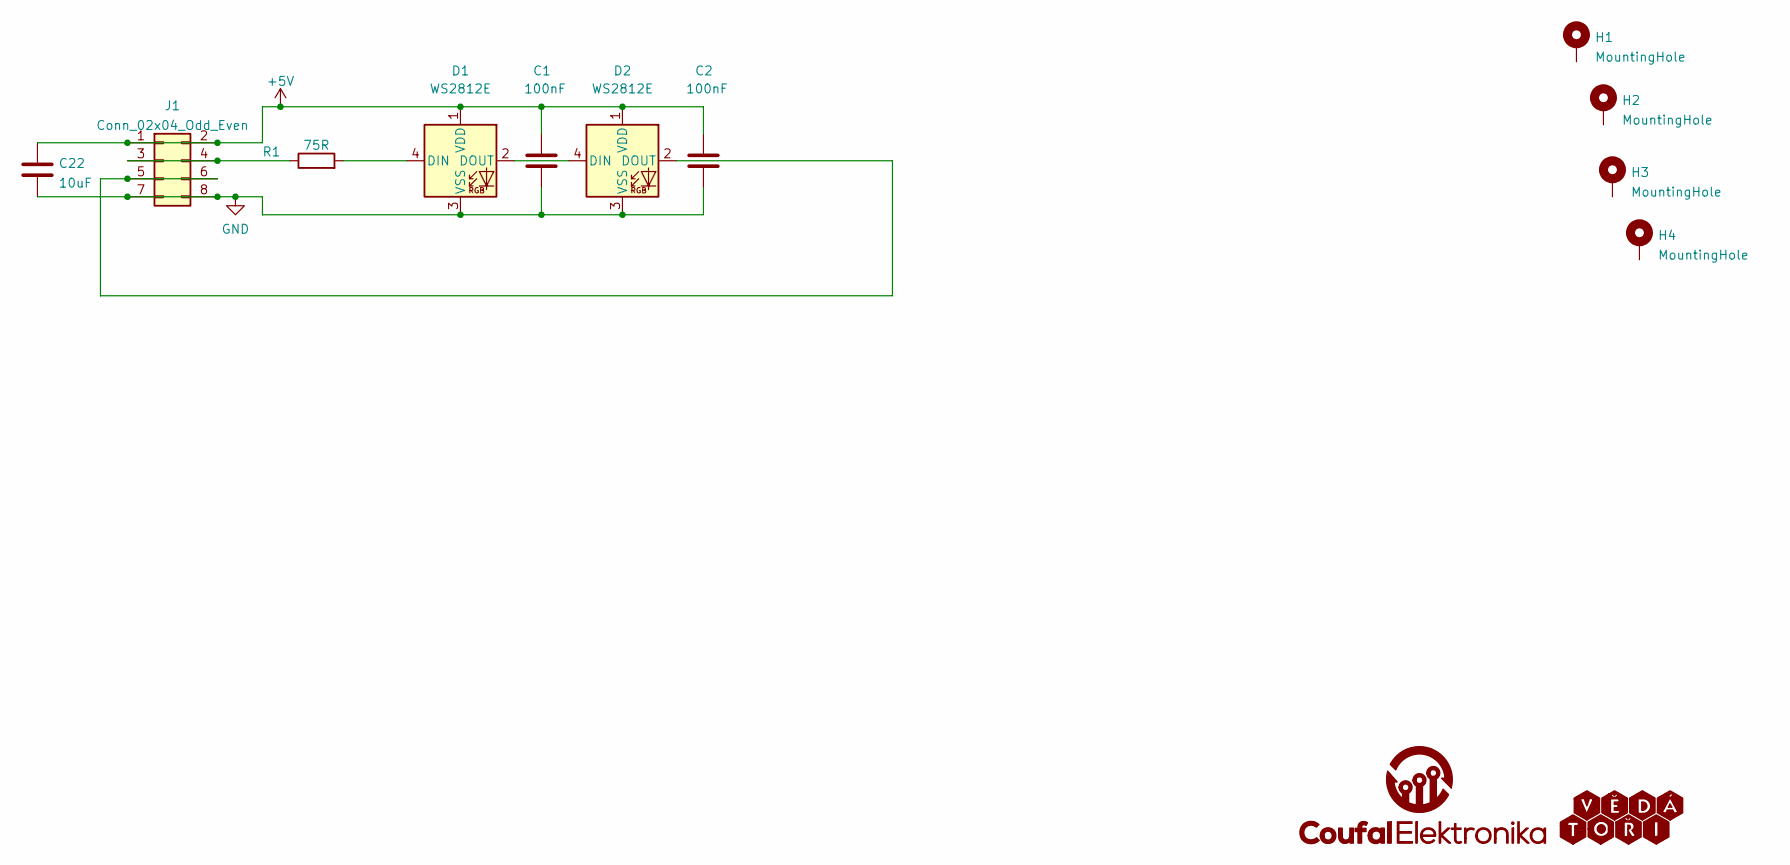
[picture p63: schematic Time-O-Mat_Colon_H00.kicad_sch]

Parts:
C1, C2: 100nF; C_0402_1005Metric; LCSC C1525
C22: 10uF; C_0603_1608Metric; LCSC C19702
D1, D2: WS2812E; LED_WS2812B_PLCC4_5.0x5.0mm_P3.2mm; LCSC C139127
G1: Vedatori_logo; Vedatori_15mm
G2: CoufalElektronika_logo; Coufal_elektronika_notext_10mm
H1, H2, H3, H4: MountingHole; MountingHole_3.2mm_M3_Pad_Via
J1: Conn_02x04_Odd_Even; PinSocket_2x04_P2.54mm_Horizontal
R1: 75R; R_0603_1608Metric; LCSC C4275

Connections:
+5V: C1.1, C2.1, C22.1, D1.1 (VDD), D2.1 (VDD), J1.1, J1.2
GND: C1.2, C2.2, C22.2, D1.3 (VSS), D2.3 (VSS), J1.7, J1.8
unnamed: D1.2 (DOUT), D2.4 (DIN)
unnamed: D1.4 (DIN), R1.2
unnamed: D2.2 (DOUT), J1.5, J1.6
unnamed: J1.3, J1.4, R1.1

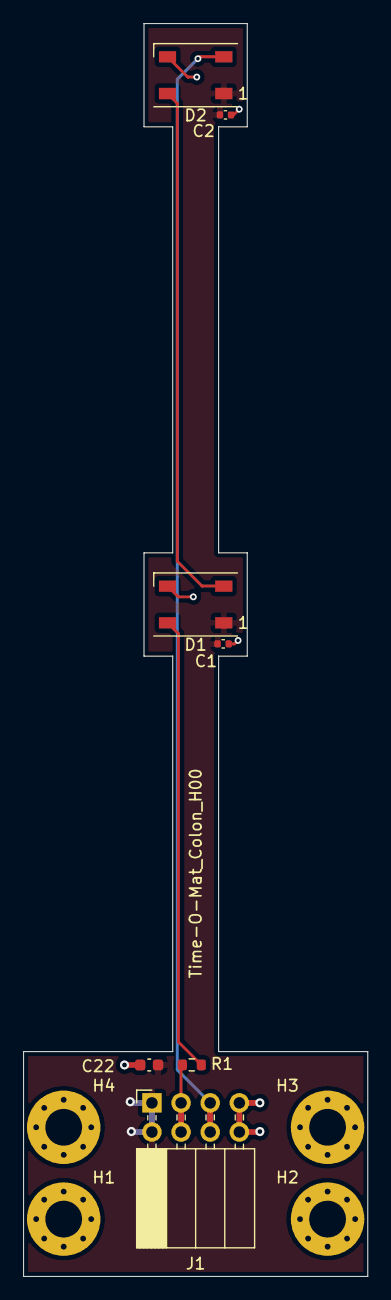
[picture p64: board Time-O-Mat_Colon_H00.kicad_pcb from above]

Board: 2 copper layers, 30.0 x 109.2 mm, 12 parts (1 on the bottom side), 6 nets.

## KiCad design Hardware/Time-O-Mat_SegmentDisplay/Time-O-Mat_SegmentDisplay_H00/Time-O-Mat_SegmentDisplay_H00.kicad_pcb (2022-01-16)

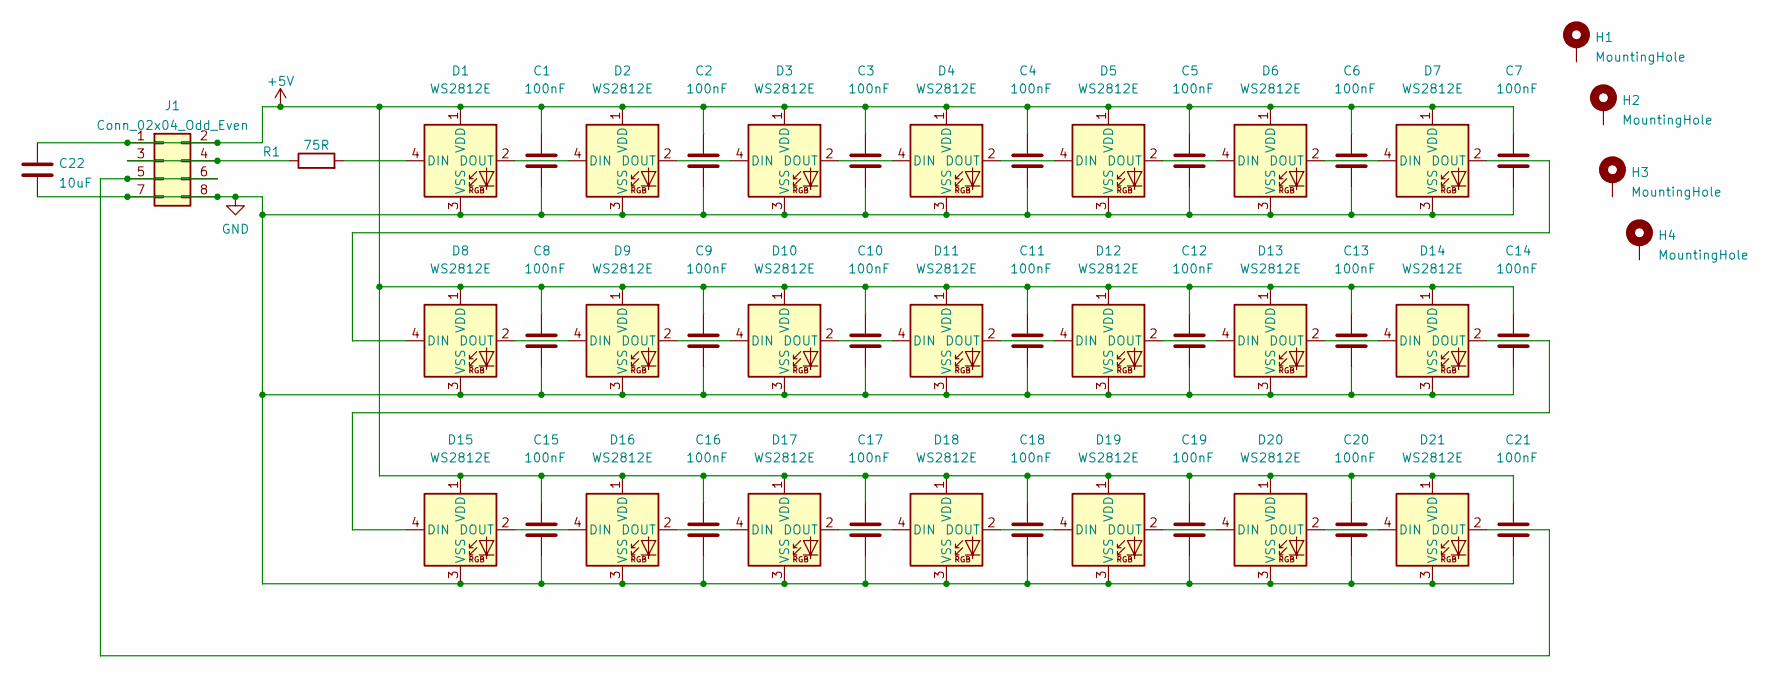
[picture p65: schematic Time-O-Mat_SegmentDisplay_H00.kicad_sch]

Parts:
C1, C2, C3, C4, C5, C6, C7, C8, C9, C10, C11, C12, C13, C14, C15, C16, C17, C18, C19, C20, C21: 100nF; C_0402_1005Metric; LCSC C1525
C22: 10uF; C_0603_1608Metric; LCSC C19702
D1, D2, D3, D4, D5, D6, D7, D8, D9, D10, D11, D12, D13, D14, D15, D16, D17, D18, D19, D20, D21: WS2812E; LED_WS2812B_PLCC4_5.0x5.0mm_P3.2mm; LCSC C139127
H1, H2, H3, H4: MountingHole; MountingHole_3.2mm_M3_Pad_Via
J1: Conn_02x04_Odd_Even; PinSocket_2x04_P2.54mm_Horizontal
R1: 75R; R_0603_1608Metric; LCSC C4275

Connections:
+5V: C1.1, C2.1, C3.1, C4.1, C5.1, C6.1, C7.1, C8.1, C9.1, C10.1, C11.1, C12.1, C13.1, C14.1, C15.1, C16.1, C17.1, C18.1, C19.1, C20.1, C21.1, C22.1, D1.1 (VDD), D2.1 (VDD), D3.1 (VDD), D4.1 (VDD), D5.1 (VDD), D6.1 (VDD), D7.1 (VDD), D8.1 (VDD), D9.1 (VDD), D10.1 (VDD), D11.1 (VDD), D12.1 (VDD), D13.1 (VDD), D14.1 (VDD), D15.1 (VDD), D16.1 (VDD), D17.1 (VDD), D18.1 (VDD), D19.1 (VDD), D20.1 (VDD), D21.1 (VDD), J1.1, J1.2
GND: C1.2, C2.2, C3.2, C4.2, C5.2, C6.2, C7.2, C8.2, C9.2, C10.2, C11.2, C12.2, C13.2, C14.2, C15.2, C16.2, C17.2, C18.2, C19.2, C20.2, C21.2, C22.2, D1.3 (VSS), D2.3 (VSS), D3.3 (VSS), D4.3 (VSS), D5.3 (VSS), D6.3 (VSS), D7.3 (VSS), D8.3 (VSS), D9.3 (VSS), D10.3 (VSS), D11.3 (VSS), D12.3 (VSS), D13.3 (VSS), D14.3 (VSS), D15.3 (VSS), D16.3 (VSS), D17.3 (VSS), D18.3 (VSS), D19.3 (VSS), D20.3 (VSS), D21.3 (VSS), J1.7, J1.8
unnamed: D1.2 (DOUT), D2.4 (DIN)
unnamed: D1.4 (DIN), R1.2
unnamed: D2.2 (DOUT), D3.4 (DIN)
unnamed: D3.2 (DOUT), D4.4 (DIN)
unnamed: D4.2 (DOUT), D5.4 (DIN)
unnamed: D5.2 (DOUT), D6.4 (DIN)
unnamed: D6.2 (DOUT), D7.4 (DIN)
unnamed: D7.2 (DOUT), D8.4 (DIN)
unnamed: D8.2 (DOUT), D9.4 (DIN)
unnamed: D10.2 (DOUT), D11.4 (DIN)
unnamed: D9.2 (DOUT), D10.4 (DIN)
unnamed: D11.2 (DOUT), D12.4 (DIN)
unnamed: D12.2 (DOUT), D13.4 (DIN)
unnamed: D13.2 (DOUT), D14.4 (DIN)
unnamed: D14.2 (DOUT), D15.4 (DIN)
unnamed: D15.2 (DOUT), D16.4 (DIN)
unnamed: D16.2 (DOUT), D17.4 (DIN)
unnamed: D17.2 (DOUT), D18.4 (DIN)
unnamed: D18.2 (DOUT), D19.4 (DIN)
unnamed: D19.2 (DOUT), D20.4 (DIN)
unnamed: D20.2 (DOUT), D21.4 (DIN)
unnamed: D21.2 (DOUT), J1.5, J1.6
unnamed: J1.3, J1.4, R1.1

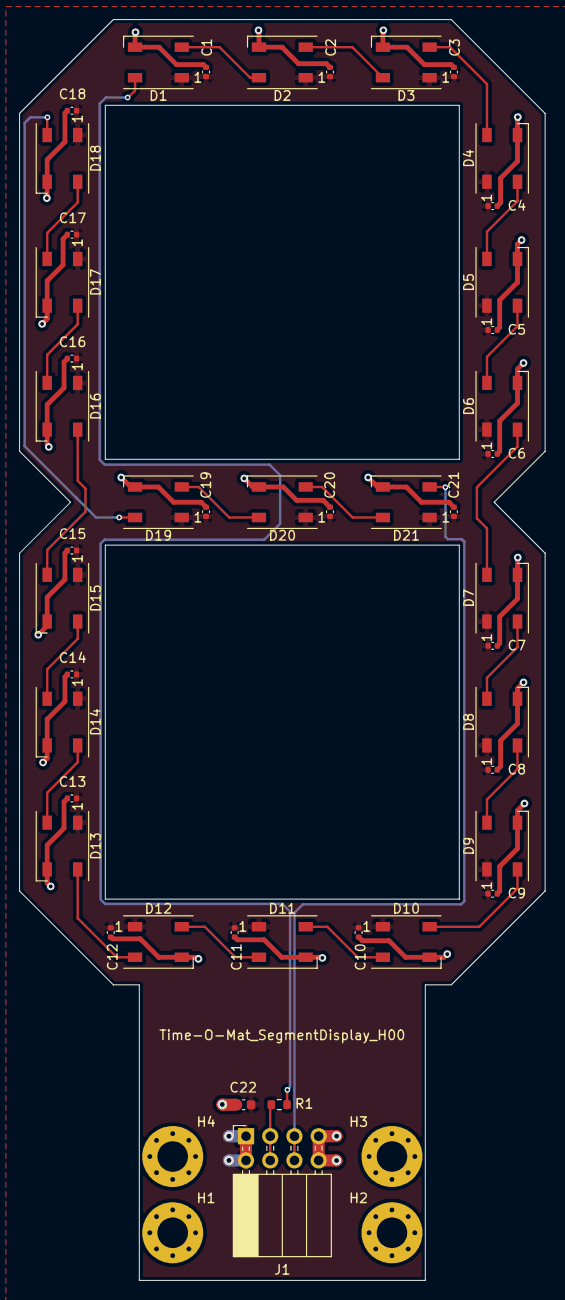
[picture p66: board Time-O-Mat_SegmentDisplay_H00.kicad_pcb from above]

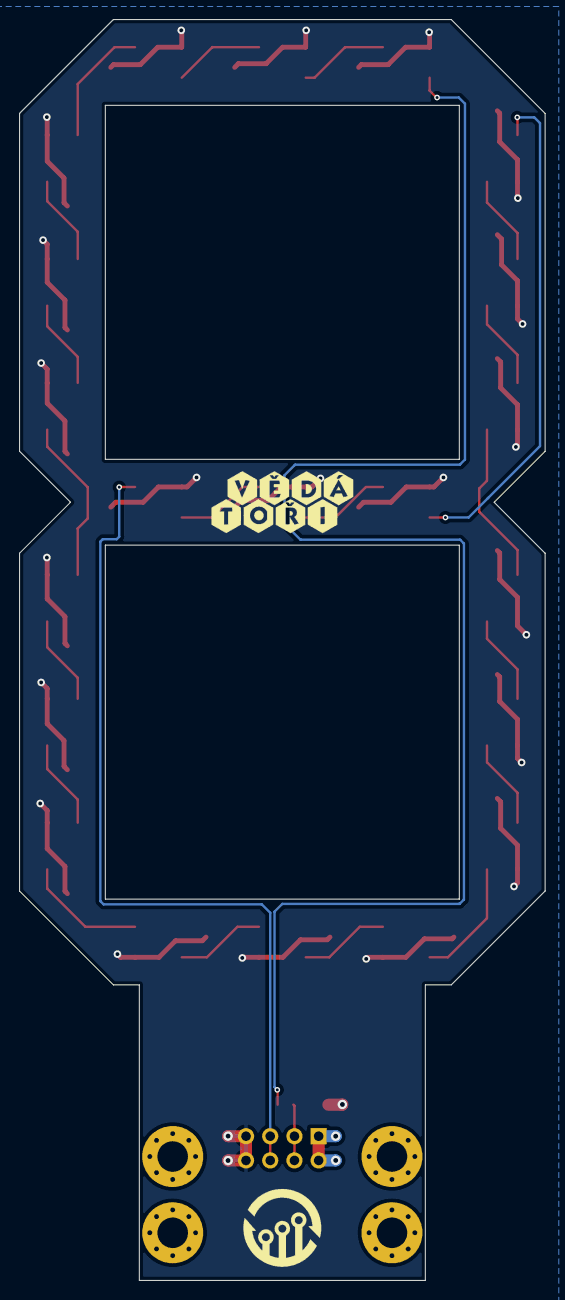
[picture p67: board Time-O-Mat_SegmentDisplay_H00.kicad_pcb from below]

Board: 2 copper layers, 55.1 x 132.3 mm, 51 parts (2 on the bottom side), 25 nets.

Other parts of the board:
G1: Vedatori_logo; Vedatori_15mm
G2: CoufalElektronika_logo; Coufal_elektronika_notext_10mm

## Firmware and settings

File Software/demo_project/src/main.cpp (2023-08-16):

#include "ToMat/ToMat.h"

ColorRGB frontColor = red;
ColorRGB backColor = {255, 180, 85};

void setup() {
    ToMat.begin();
    ToMat.startWiFiCaptain("<your_name>");
    ToMat.display.setTransition(all, Exponential, 2.0);
    ToMat.display.setBrightness(all, 0.0);
    ToMat.display.setPanels(backlight, backColor);
}

void loop() {
    // Handle side-button features
    if(ToMat.buttonRead(0)) {
        ESP.restart();
    }
    if(ToMat.buttonRead(1)) {
        ToMat.piezo.playMelody(themeMelodyFull);
    }

    // Handle manual time control
    if(ToMat.buttonRead(2) && ToMat.touchBar.getPressed(0)) {
        ToMat.time.shiftMinutes(-1);
    }
    if(ToMat.buttonRead(2) && ToMat.touchBar.getPressed(1)) {
        ToMat.time.shiftMinutes(1);
    }

    // Handle manual color control
    int colorStep = 20;
    if(ToMat.buttonRead(2) && ToMat.touchBar.getPressed(2)) {
        frontColor = shiftColor(frontColor, -colorStep, 0, 0);
    }
    if(ToMat.buttonRead(2) && ToMat.touchBar.getPressed(3)) {
        frontColor = shiftColor(frontColor, colorStep, 0, 0);
    }

    if(ToMat.buttonRead(2) && ToMat.touchBar.getPressed(4)) {
        frontColor = shiftColor(frontColor, 0, -colorStep, 0);
    }
    if(ToMat.buttonRead(2) && ToMat.touchBar.getPressed(5)) {
        frontColor = shiftColor(frontColor, 0, colorStep, 0);
    }

    if(ToMat.buttonRead(2) && ToMat.touchBar.getPressed(6)) {
        frontColor = shiftColor(frontColor, 0, 0, -colorStep);
    }
    if(ToMat.buttonRead(2) && ToMat.touchBar.getPressed(7)) {
        frontColor = shiftColor(frontColor, 0, 0, colorStep);
    }
    
    // Handle WebApp commands
    if(ToMat.commandGetIndexed(0) == "rgb") {
        frontColor.red = ToMat.commandGetIndexed(1).toInt();
        frontColor.green = ToMat.commandGetIndexed(2).toInt();
        frontColor.blue = ToMat.commandGetIndexed(3).toInt();
        ToMat.commandClear();
    }
    if(ToMat.commandGetIndexed(0) == "settime") {
        int hours = ToMat.commandGetIndexed(1).toInt();
        int minutes = ToMat.commandGetIndexed(2).toInt();
        ToMat.time.setTime(hours, minutes);
        ToMat.commandClear();
    }
    if(ToMat.commandGetIndexed(0) == "setzone") {
        ToMat.time.setTimeZone(ToMat.commandGetIndexed(1));
        ToMat.commandClear();
    }

    // Update LED brightness
    float illumination = ToMat.illumination.get(0);     // Front photoresistor
    float brightnessFront = ToMat.autoBrightnessFront(illumination);
    float brightnessBack = ToMat.autoBrightnessBack(illumination);
    ToMat.display.setBrightness(frontlight, brightnessFront);
    ToMat.display.setBrightness(backlight, brightnessBack);

    // Update displayed time
    String timeDisp = ToMat.time.getClockText();
    if(timeDisp[0] == '0') {
        timeDisp[0] = ' ';
    }
    ToMat.display.setText(timeDisp, frontColor);
    ToMat.display.setPanels(colon, frontColor);

    ToMat.printDiagnostics();

    delay(500);
}

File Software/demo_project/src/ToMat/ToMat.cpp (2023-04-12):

#include "ToMat.h"

#include "OneWire.h"
#include "DallasTemperature.h"
#include "SPIFFS.h"

OneWire oneWire(TM::ONE_WIRE_PIN);
DallasTemperature sensors(&oneWire);
Melody themeMelodyFull(
	"TEMPO=140 " 
	"F5#/8 H4/8 E5#/8 H4/8 F5#/8 H4/8 E5#/8 H4/8 F5#/8 C5#/8 E5#/8 C5#/8 F5#/8 C5#/8 E5#/8 C5#/8 F5#/8 A4#/8 E5#/8 A4#/8 F5#/8 A4#/8 E5#/8 A4#/8 F5#/8 A4#/8 E5#/8 A4#/8 D5#/8 A4#/8 E5#/8 A4#/8 F5#/8 H4/8 E5#/8 H4/8 F5#/8 H4/8 E5#/8 H4/8 "
    "F5#/8 C5#/8 E5#/8 C5#/8 F5#/8 C5#/8 E5#/8 C5#/8 F5#/8 A4#/8 E5#/8 A4#/8 F5#/8 A4#/8 E5#/8 A4#/8 F5#/8 A4#/8 E5#/8 A4#/8 D5#/8 F4#/8 C4#/8 F4#/8 E4#/4 E4#/4 E4#/4 E4#/8 D4#/8 "
    "E4#/8 F4#/8 E4#/8 D4#/8* D4#/8 F4#/8  E4#/4 E4#/4 E4#/8 F4#/8 E4#/8 D4#/8 D4#/2 R/4 A3#/8 D4#/8 "
    "C4#/4 C4#/4 C4#/4 C4#/8 H3/8 C4#/8 D4#/8 C4#/8 C4#/2 C4#/8 C4#/8 C4#/4 C4#/8 D4#/4 A3#/8 A3#/8 A3#/2 R/4 D4#/8 F4#/8 "
    "E4#/4 E4#/4 E4#/4 E4#/8 D4#/8 E4#/8 F4#/8 E4#/8 D4#/4* D4#/8 F4#/8 E4#/4 E4#/4 E4#/8 F4#/8 E4#/8 D4#/8 D4#/2 R/4 A3#/8 D4#/8 "
    "C4#/4 C4#/4 C4#/4 C4#/8 H3/8 C4#/8 D4#/8 C4#/8 C4#/2 C4#/8 C4#/8 C4#/8 C4#/8 C4#/8 D4#/4 A3#/8 A3#/8 C4#/2 R/2 "
    "F5#/8 F5#/8 R/8 F5#/8 R/8 F5#/8 R/8 F5#/8 R/8 F5#/8 R/2 F5#/8 F5#/8 R/8 F5#/8 R/8 F5#/8 R/8 G5#/8* F5#/8 F5#/8 "
    "F5#/8 E5#/8 D5#/8 R/8 F5#/8 F5#/8 R/8 F5#/8 R/8 F5#/8 R/8 F5#/8 R/8 F5#/8 R/8 F5#/8 F5#/4 E5#/8 D5#/8 E5#/8 E5#/8 "
    //REPETICE - HLAVNI MELODIE
    "R/2 R/8 D5#/8 E5#/8 F5#/8 F5#/8 E5#/8 D5#/8 R/4 G5#/4 G5#/4 F5#/8 E5#/8 R/8 D5#/8 R/8 D5#/4 R/8 D5#/4* R/8 R/4 R/4 R/4* D5#/8 E5#/8 F5#/8 F5#/8 F5#/4 F5#/4 F5#/4 F5#/4 E5#4 E5#/4 D5#/4 D5#/4 "
    "R/2 R/8 D5#/8 E5#/8 F5#/8 F5#/8 E5#/8 D5#/8 R/4 G5#/4 G5#/4 F5#/8 E5#/8 R/8 D5#/8 R/8 D5#/4 R/8 D5#/4* R/8 R/4 R/4 R/4* D5#/8 E5#/8 F5#/8 F5#/8 F5#/4 F5#/4 F5#/4 F5#/4 E5#4 E5#/4 D5#/4 D5#/4 "
);
Melody themeMelody(
	"TEMPO=140 " 
	"R/2 R/8 D5#/8 E5#/8 F5#/8 F5#/8 E5#/8 D5#/8 R/4 G5#/4 G5#/4 F5#/8 E5#/8 R/8 D5#/8 R/8 D5#/4 R/8 D5#/4* R/8 R/4 R/4 R/4* D5#/8 E5#/8 F5#/8 F5#/8 F5#/4 F5#/4 F5#/4 F5#/4 E5#4 E5#/4 D5#/4 D5#/4 "
    "R/2 R/8 D5#/8 E5#/8 F5#/8 F5#/8 E5#/8 D5#/8 R/4 G5#/4 G5#/4 F5#/8 E5#/8 R/8 D5#/8 R/8 D5#/4 R/8 D5#/4* R/8 R/4 R/4 R/4* D5#/8 E5#/8 F5#/8 F5#/8 F5#/4 F5#/4 F5#/4 F5#/4 E5#4 E5#/4 D5#/4 D5#/4 "
);

void TM::refreshTaskQuick(void * parameter) {
    for(;;) {
        ToMat.display.update();
        ToMat.touchBar.update();
        ToMat.illumination.update();
        ToMat.time.updateRTC();
        delay(20);
    }
}

void TM::refreshTaskSlow(void * parameter) {
    for(;;) {
        ToMat.power.update();
        ToMat.display.setCurrentLimit(ToMat.power.getLimitA() - TM::idleCurrent);
        ToMat.updateTemperature();

        static uint32_t internetUpdateTime = 0;
        static uint32_t softApDisableTime = 0;
        static bool softApEnabled = true;
		if((millis() - internetUpdateTime) > TM::INTERNET_UPDATE_PERIOD || internetUpdateTime == 0) {
			ToMat.checkInternetConnected();
            if(ToMat.getInternetConnected()) {
                internetUpdateTime = millis();
                if(softApEnabled) {
                    softApDisableTime = millis();
                }
            }
            else if(ToMat.getWifiCaptStarted() && !softApEnabled) {
                softApEnable();
            }
		}
        if(ToMat.getInternetConnected()) {
            ToMat.time.updateNTP();
            ToMat.weather.updateBothWF();
        }
        if(softApDisableTime != 0 && (millis() - softApDisableTime) > TM::SOFT_AP_DISABLE_TIMEOUT) {
            softApDisableTime = 0;
            softApEnabled = false;
            softApDisable();
        }
        delay(1000);
    }
}

void ToMat_class::begin() {
    beginCalled = true;


    power.begin(TM::CC_PIN[0], TM::CC_PIN[1]);
    illumination.update();
    display.begin();
    display.setCurrentLimit(ToMat.power.getLimitA() - TM::idleCurrent);
    time.begin(1000 * 60 * 15);
    touchBar.begin();
    piezo.begin(TM::BUZZER_CHANNEL, TM::BUZZER_PIN);

	weather.init(1000 * 60 * 15);
	weather.setKey(TM::WEATHER_API_KEY, WEATHERAPI::WA_DEFAULT);
	weather.setPosition(50.36, 15.79, "Choteborky", WEATHERAPI::WA_DEFAULT);

    for(int i = 0; i < 3; ++i) {
        pinMode(TM::BUTTON_PIN[i], INPUT_PULLUP);
    }

    sensors.begin();
    
    xTaskCreatePinnedToCore(TM::refreshTaskQuick, "refreshTaskQuick", 10000 , NULL, 3, NULL, 1);
    xTaskCreatePinnedToCore(TM::refreshTaskSlow, "refreshTaskSlow", 10000 , NULL, 0, NULL, 0);

    display.setUpdateActive(true);
}

bool ToMat_class::buttonRead(int buttonID) {
    if(buttonID < 0 || buttonID > 2) {
        printf("Invalid button ID: %d\n", buttonID);
        return 0;
    }
    return !digitalRead(TM::BUTTON_PIN[buttonID]);  // 1 = pressed
}

void ToMat_class::updateTemperature() {
    sensors.requestTemperatures();
    float newTemp = sensors.getTempCByIndex(0);
    if(newTemp > -100.0) {
        // Filter out nonsense measurements
        temperature = newTemp;
    }
}

float ToMat_class::getTemperature() {
    return temperature;
}

float ToMat_class::autoBrightnessFront(float illumination) {
    float brightness = 0.0;
    if(illumination > 0.7) {
        brightness = (illumination - 0.7) / 0.3 * 0.8 + 0.2;
    }
    else if(illumination > 0.5) {
        brightness = (illumination - 0.5) / 0.2 * 0.15 + 0.05;
    }
    else if(illumination > 0.2) {
        brightness = (illumination - 0.2) / 0.3 * 0.046 + 0.004;
    }
    else {
        brightness = 0.004;
    }
    return brightness;
}
float ToMat_class::autoBrightnessBack(float illumination) {
    float brightness = 0.0;
    if(illumination > 0.7) {
        brightness = 0.0;
    }
    else if(illumination > 0.5) {
        brightness = -(illumination - 0.5) / 0.2 * 0.1 + 0.1;
    }
    else if(illumination > 0.2) {
        brightness = (illumination - 0.2) / 0.3 * 0.1;
    }
    else {
        brightness = 0.0;
    }
    return brightness;
}

void ToMat_class::printDiagnostics() {
    for(int i = 0; i <= 2; ++i) {
        printf("btn%d: %d ", i, buttonRead(i));
    }
    
    printf("touchDigit: ");
    for(int i = 0; i <= 7; ++i) {
        printf("%d", touchBar.getPressed(i));
    }

    printf(" power: %s %.1fA ", power.getVoltagesText().c_str(), power.getLimitA());
    printf("illum: %s", illumination.getIlluminationText().c_str());

    //printf("priority: %d ", uxTaskPriorityGet(NULL));

    printf("temp: %f ", temperature);

    String timeDisp = ToMat.time.getClockText();
    printf("time: %s ", timeDisp.c_str());

    printf("weather: %s \n", ToMat.weather.getWeather().getWeatherString().c_str());

}
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

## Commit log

2022-01-15 First Hardware commit
    [18650_case_batt.step, Encoders.sch, Gyro.sch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]
2022-01-15 Created segment PCB
    [18650_case_batt.step, Eight v2 - Dot PCB outline.dxf, Eight v2 - PCB outline (1).dxf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]
2022-01-15 Exported step model with components
    [Time-O-Mat_SegmentDisplay_H00.kicad_sch, Time-O-Mat_SegmentDisplay_H00.step]
2022-01-15 Updated segment pcb
    [Time-O-Mat_SegmentDisplay_H00.kicad_pcb, Time-O-Mat_SegmentDisplay_H00.kicad_sch]
2022-01-16 PCB updates
    [Time-O-Mat_SegmentDisplay_H00.kicad_sch]
2022-01-16 Colon update
    [18650_case_batt.step, Encoders.sch, Gyro.sch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]
2022-01-16 HW update
    [Time-O-Mat_MoBo_H00.kicad_pcb, Time-O-Mat_MoBo_H00.kicad_sch, Time-O-Mat_TouchBar_H00.kicad_pcb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]
2022-01-19 HW updates
    [Time-O-Mat_MoBo_H00.kicad_pcb, Time-O-Mat_MoBo_H00.kicad_sch, Time-O-Mat_TouchBar_H00.kicad_pcb]
2022-01-19 HW updates.
    [Time-O-Mat_MoBo_H00.kicad_sch]
2022-02-15 Exported up to date STEP models and manufacturing data
    Exported up to date 3D models of all PCB parts.
    Created new subpanels fot manufacturing to counteract duplicit designators on different boards.
    [BOM.xlsx, BOM2.xlsx, BOM3.xlsx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]
2022-02-16 Added H00 PCB panel screenshot to Readme.
2022-03-01 HW designers notes.
    [WS2812 power consumption mapping.xlsx]
2022-03-24 Tested HW components
    Photoresistor missing
    [Time_o_mat.h, main.cpp]
2022-03-29 Basic ntp clock demo. Displaying characters and short text on the display.
    [Time_o_mat.h, main.cpp]
2022-04-07 Updating leds synchronously. Added color definitions.
2022-05-31 H01 changes
    [Four segments and colon-B_Cu.gbr, Four segments and colon-B_Mask.gbr, Four segments and colon-B_Paste.gbr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]
2022-05-31 H01 touchbar updates
    [Time-O-Mat_TouchBar_H01.kicad_pcb, Time-O-Mat_TouchBar_H01.step]
2022-06-25 H01 manufacaturing changes
    [BOMMoBoH01.xlsx, Time-O-Mat_MoBo_H01.csv, Time-O-Mat_MoBo_H01.kicad_pcb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]
2022-06-28 Fixed linear transition stable state. Setting brightness once.
    [main.cpp]
2022-07-09 RGB and HSV color representation. Fixed LED linear transition. Reindexed LED segments.Controlling backlight.
    [main.cpp]
2022-07-12 H02 commits
    [Time-O-Mat_MoBo_H01-B_Cu.gbr, Time-O-Mat_MoBo_H01-B_Mask.gbr, Time-O-Mat_MoBo_H01-B_Paste.gbr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]
2022-07-12 H02 updates
    [Time-O-Mat_MoBo_H02.kicad_pcb, Time-O-Mat_MoBo_H02.kicad_sch, USB+Power.kicad_sch]
2022-07-12 Exported manufacturing data
    [BOMMoBoH01.xlsx, BOMMoBoH02.xlsx, BOM_xinglight.xlsx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]
2022-07-13 H02 changes
    [Time-O-Mat_MoBo_H02.kicad_pcb]
2022-07-13 Final HW changes
    [Time-O-Mat_MoBo_H01-B_Cu.gbr, Time-O-Mat_MoBo_H01-B_Mask.gbr, Time-O-Mat_MoBo_H01-B_Paste.gbr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]
2022-08-10 Manual update
    Photoresistor, LED strip and touchbar added to Electronics manual.
2022-08-11 Corrections in electronics manual.
    [Time_o_mat.h]
2022-08-12 Added buttons and touchbar module to TM lib.
2022-08-13 Added USB power limit module.
2022-08-13 Printing diagnostic info via lib function.
2022-08-15 Updated prog. manual up to buttons.
2022-08-15 Reading temperature + in manual.
2022-08-15 Digital touchbar output. Turning leds off after start.
2022-08-17 Fixed touchbar filter.
2022-08-18 Fixed display refresh without wifi.
    [ToMat.cpp]
2022-08-19 Some fixes to Weather
    [ToMat.cpp, ToMat.h]
2022-08-19 Added theme melody, fixed main.cpp
    [ToMat.cpp, ToMat.h, main.cpp]
2022-08-19 Update power api.
2022-08-19 Fixed disabling softAP when wifiCapt not started.
    [ToMat.cpp, ToMat.h]
2022-08-20 Mechanical files added
    .stl, .dxf and .svg files added.
    [Box - Back.stl, Box - Bottom.stl, Box - Front.stl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]
2022-10-21 Revert "Time module rework"
    This reverts commit 9a64cf988bfc1bbdb4341091c141d592ec8ff98f.
    [ToMat.cpp]
2022-10-30 Fixed NTP summer time offset. Added manual time settings. Added front display color settings.
    [ToMat.cpp, main.cpp]
2022-12-26 Fixed int to uint8_t conversion in wifi command.
    [main.cpp]
2023-02-21 LED states as structs
2023-03-18 Fixed brightness and transition setters.
    [main.cpp]
2023-03-31 Updating LEDs only when necessary.
2023-03-31 Power module automatic mode
2023-04-10 Limiting LED current.
2023-04-11 Added power limit to prog. manual. transRate -> transTime.
2023-04-12 Fix idle current const. Refactored main loop.
    [ToMat.cpp, ToMat.h, main.cpp]
2023-04-13 Fix idle current. Narrowed exp. transition. Printing diagnostics.
    [ToMat.h, main.cpp]
2023-04-14 Fixed colon color updating.
    [main.cpp]
